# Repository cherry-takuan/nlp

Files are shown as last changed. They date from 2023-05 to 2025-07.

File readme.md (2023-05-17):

# NLP(NAND Logic Processor)
 現在開発中のNANDのみを用いたCPUのプロジェクトです．
現在以下のバリエーションが存在します  
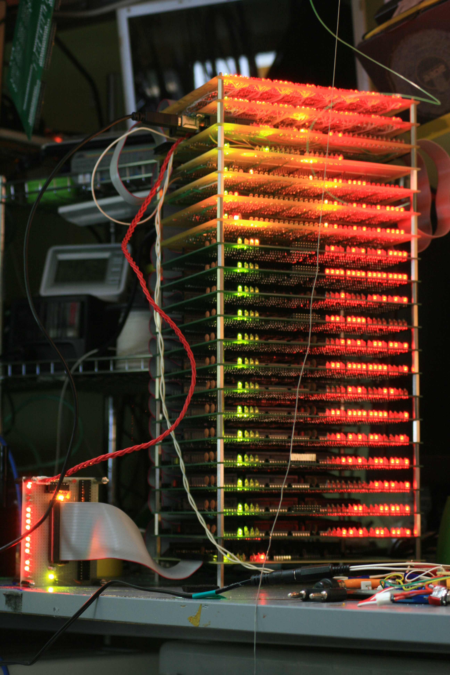
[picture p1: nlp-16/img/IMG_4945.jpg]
NLP-16

- NLP-16
- NLP-16A

 NLP-16は本プロジェクトの最初の成果物です．2019年(私が高校2年)の冬に設計を開始し，そこから３年ほどかけ製作しました．  
 [動作(Twitter)](https://twitter.com/cherry_takuan/status/1593374888496021505)  
単独での動作に成功しましたがいくつかの改善点が見つかったため，NLP-16によって得られた知見を基に改良版としてNLP-16Aを現在は開発中です．  
 また，NLP-16Aではキット化を目標に設計，製作しています．

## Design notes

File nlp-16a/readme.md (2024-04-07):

# NLP-16A
NLP-16の知見を基に現在製作しているNAND CPU．
スペックを維持したままキット化(あわよくば教育用に)を目標にしている．
## 歴
- 2023年始 次世代機(NLP-16A)の開発の検討
- 2023/03/11 NLP-16の開発を中止．NLP-16によって得られた知見を基に改良版の16Aの開発に移行．
- 2023/03/15 NLP-16A ALU開発開始
- 2023/05/15～ 基板到着．試作開始
- 2023/07/26～ ALU制御基板開発開始
- 2023/08/10～ デバッガ開発開始

## 現在の作業
- [ALUの製作](./Hardware/alu_c)→完了
- ALU制御(回路設計段階)→完了
- [デバッガの製作](./Hardware/debugger)→完了
- Y BUS制御→完了
- A BUS制御→完了
- Acc→完了
- Reg→完了

## 現時点で判明している不良個所
### ALU  
電源のターミナルブロックとICの干渉  
NLP-16と基板形状の不一致  
ALU制御基板-ALU基板間の制御ピンにおいて入力Bの符号ビットが設計から欠落  
デコード回路の軽微な修正
### 命令デコーダ
設計中
### レジスタ，データバス  
設計完了  
Y BUS内部処理モードにAccの追加
### I/O
設計完了  
特になし．

### デバッガ  
設計完了(USB-UART変換は未定)  

## 設計変更点  
- MEMのRegAddressを10から11に変更  
- RegAddress10をRegFに変更(これはまた変更の可能性があるが，変更の範囲は内部モードで使用しない用途に限る)  

## NLP-16との更新  
- PCB化  
- レジスタバスに用いた回路を変更．アクセスの最悪値を約1/3に高速化した  
- 1word命令の増強．演算系命令を中心にアキュムレータを積極的に使用する演算を行う．  
- 割り込み関連命令の増強．割り込み禁止/許可命令，ソフトウェア割り込みの実装を行った．

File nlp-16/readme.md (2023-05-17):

# NLP-16
NLP-16は2入力NANDのみで構成された16bitCPUです．  
NANDのみでありながらi8080のような多彩な命令を備えています．  
NLP-16  
## 歴
- 2019/11/19 プロジェクト開始
- 2020/06/13算術論理演算装置(ALU)の完成．PCによって制御を行いハードウェアのテストを行う
- 2022/03/21 レジスタおよびデータバス制御の完成．PCを用いてハードウェアの自動テストを行う
- 2022/03/30 プロセッサの各要素を外部のマイコンから制御し，目的の命令を実行できることを確認．また，テストの一環としてフィボナッチ数列を20項までを1セットとして1000セットの計算を実施，成功．
(以下は日にちを要確認，仮の日にち)
- 2022/09/02 命令デコーダを実装完了．
- 2022/09/03 ROM基板を製作．NLP-16のみで独立した動作に成功．
- 2022/09/04 MakerFaireTokyo2022にちぇりー技術として単独出展し，NLP-16を展示．不安定ながら好評いただいた．
- 2023/03/11 NLP-16の開発を中止．NLP-16によって得られた知見を基に改良版の16Aの開発に移行．

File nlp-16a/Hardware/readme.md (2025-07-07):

# ハードウェア
ハードウェアへのリンク。回路/基板データをクリックするとブラウザからアートワークや回路が閲覧できます。kicanvasすごい。ありがとう。

アーキテクチャ，命令セットは以下から。

[アーキテクチャ](https://github.com/cherry-takuan/nlp/tree/master/nlp-16a/architecture)
[命令セット](https://github.com/cherry-takuan/nlp/blob/master/nlp-16a/architecture/ISA.pdf)

## NLP-16A本体
***
### 演算装置
ALUはプロセッサ内での演算処理を行うユニットです。NLP-16Aでは8bit ALUを2ユニット使用し16bitの並列演算を行っています。

ALU制御回路回路はALUを操作するための制御信号生成し，また演算結果からフラグを生成する機能を持っています。
***
#### ALU本体
[alu_c](https://github.com/cherry-takuan/nlp/tree/master/nlp-16a/Hardware/alu_c)

[回路/基板データ](https://kicanvas.org/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)

最新バージョン : v1.2

#### ALU制御
[alu_ctrl](https://github.com/cherry-takuan/nlp/tree/master/nlp-16a/Hardware/alu_ctrl)

[回路/基板データ](https://kicanvas.org/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)

最新バージョン : v1.1
***
### レジスタファイル
レジスタファイルとは，プロセッサ内で一時的に記憶するレジスタと呼ばれる回路を複数集積したものです。NLP-16Aでは16bitのデータを記憶可能なレジスタを16本持っています。

汎用レジスタは5本で，残りのレジスタは何らかの役割を持ち，単純な記憶以外の動作も行うことがあります。

***
### レジスタ
[Reg](https://github.com/cherry-takuan/nlp/tree/master/nlp-16a/Hardware/Reg)

[回路/基板データ](https://kicanvas.org/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)

最新バージョン : v1.1

#### アキュムレータ
[Accumulztor](https://github.com/cherry-takuan/nlp/tree/master/nlp-16a/Hardware/Accumulator)

[回路/基板データ](https://kicanvas.org/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)

最新バージョン : v1.1

#### ALU入力バス(A BUS)制御
[A_BUS_Ctrl](https://github.com/cherry-takuan/nlp/tree/master/nlp-16a/Hardware/A_BUS_Ctrl)

[回路/基板データ](https://kicanvas.org/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)

最新バージョン : v1.1

#### ALU出力バス(Y BUS)制御
[Y_BUS_Ctrl](https://github.com/cherry-takuan/nlp/tree/master/nlp-16a/Hardware/Y_BUS_Ctrl)

[回路/基板データ](https://kicanvas.org/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)

最新バージョン : v1.2
***
### 入出力
NLP-16Aは16 bit x 64 kwordの1つの入出力ポートを持っています。
内部的にはレジスタの一つとしてアクセス可能な構造になっています。

主記憶及び外部デバイスとの接続に使用されます。
***
#### 外部バス制御
[Bus_terminator](https://github.com/cherry-takuan/nlp/tree/master/nlp-16a/Hardware/BUS_terminator)

[回路/基板データ](https://kicanvas.org/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)

最新バージョン : v1.1

***
### 制御装置
制御装置では，上記のユニットを入力された命令に従って制御を行います。

***

#### 命令デコーダ
[Instruction_decoder](https://github.com/cherry-takuan/nlp/tree/master/nlp-16a/Hardware/Instruction_decoder)

[回路/基板データ](https://kicanvas.org/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)

最新バージョン : v1.1

#### ステート保持レジスタ
[State_hold](https://github.com/cherry-takuan/nlp/tree/master/nlp-16a/Hardware/State_hold)

[回路/基板データ](https://kicanvas.org/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)

最新バージョン : v1.0

#### 命令デコーダ グルーロジック
[ID_interface](https://github.com/cherry-takuan/nlp/tree/master/nlp-16a/Hardware/ID_interface)

[回路/基板データ](https://kicanvas.org/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)

最新バージョン : v1.1

***

## 周辺機器

***

### NLP-16A専用デバッガ
基板の自動テストやRAMへのIPLデータ書き込み等で使用。

[debug](https://github.com/cherry-takuan/nlp/tree/master/nlp-16a/Hardware/debug)

[回路/基板データ](https://kicanvas.org/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)

最新バージョン : v1.1

### マザーボード
プロセッサに周辺機器を接続するためのボード。マザーと言いつつ本体よりかなり小さい。

[IO_board](https://github.com/cherry-takuan/nlp/tree/master/nlp-16a/Hardware/IO_board)

[回路/基板データ](https://kicanvas.org/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)

最新バージョン : v1.1

### RAMボード(デバッガ接続版)
主記憶装置。デバッガから内容を書き換えることが可能で，IPL等の導入に使用できる。

[RAM_board](https://github.com/cherry-takuan/nlp/tree/master/nlp-16a/Hardware/RAM_board)

[回路/基板データ](https://kicanvas.org/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)

最新バージョン : v1.1

### 通信ボード
RS-232Cを介して様々なデバイスと通信可能。PC，サーマルプリンタ，MSMPインターフェイス等と接続した実績がある。

[RS_232C_board](https://github.com/cherry-takuan/nlp/tree/master/nlp-16a/Hardware/RS_232C_board)

[回路/基板データ](https://kicanvas.org/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)

最新バージョン : v1.2

### ビデオボード

キャラクタジェネレータ付きの640x480画素のVGA映像出力ボード。
VRAM領域にテキストデータを書き込むと対応した画面位置に文字を表示する機能を持つ。

なお以下のリポジトリは画面に表示こそ可能だが，ハードウェアに一部不具合があるバージョン。今後修正を反映予定(正常に動作するボードは完成済みで反映待ち)

[VGAボード](https://github.com/cherry-takuan/NLP_VGA)

[回路/基板データ](https://kicanvas.org/?github=https%3A%2F%2Fgithub.com%2Fcherry-takuan%2FNLP_VGA)

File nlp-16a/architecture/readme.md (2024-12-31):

# NLP-16Aアーキテクチャ

NLP-16Aはストアドプログラム方式の16bit CPUです。
i8085の命令セットを参考に，16bitへの拡張やアドレッシングモードの拡充等を行っています。  

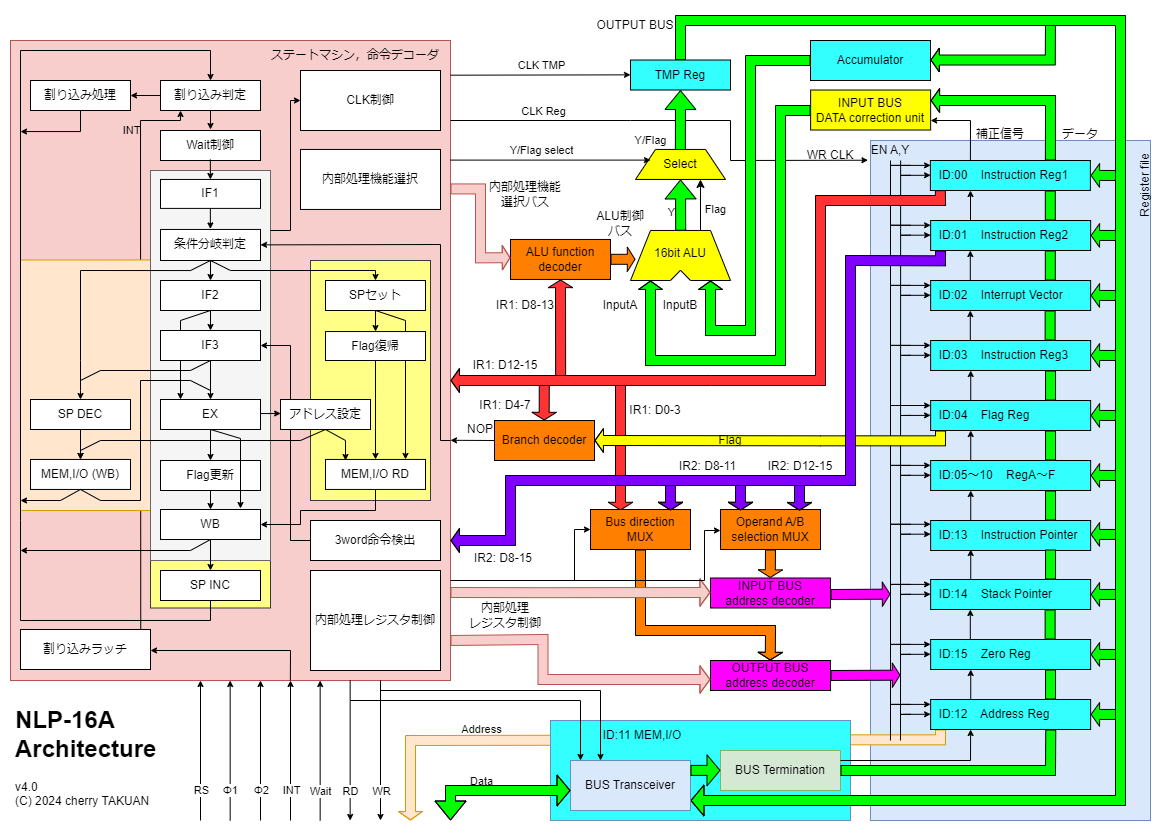
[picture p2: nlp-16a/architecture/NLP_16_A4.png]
Architecture アーキテクチャ


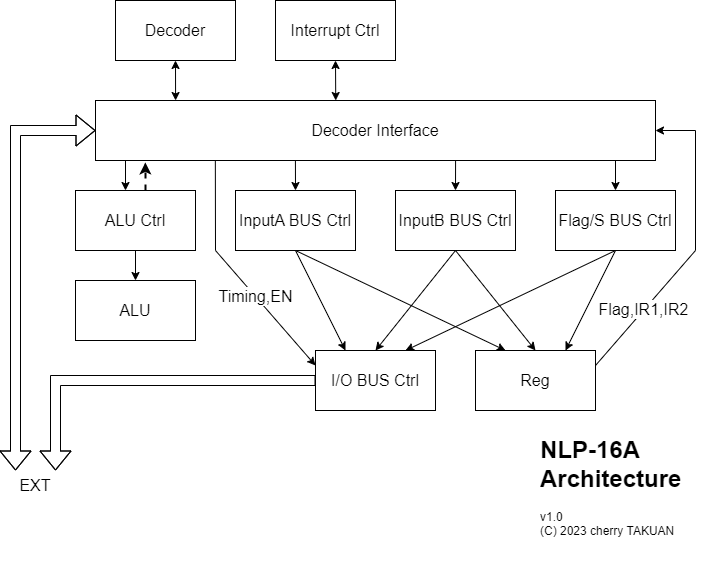
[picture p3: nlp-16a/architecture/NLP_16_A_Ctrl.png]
Control 制御関連の接続


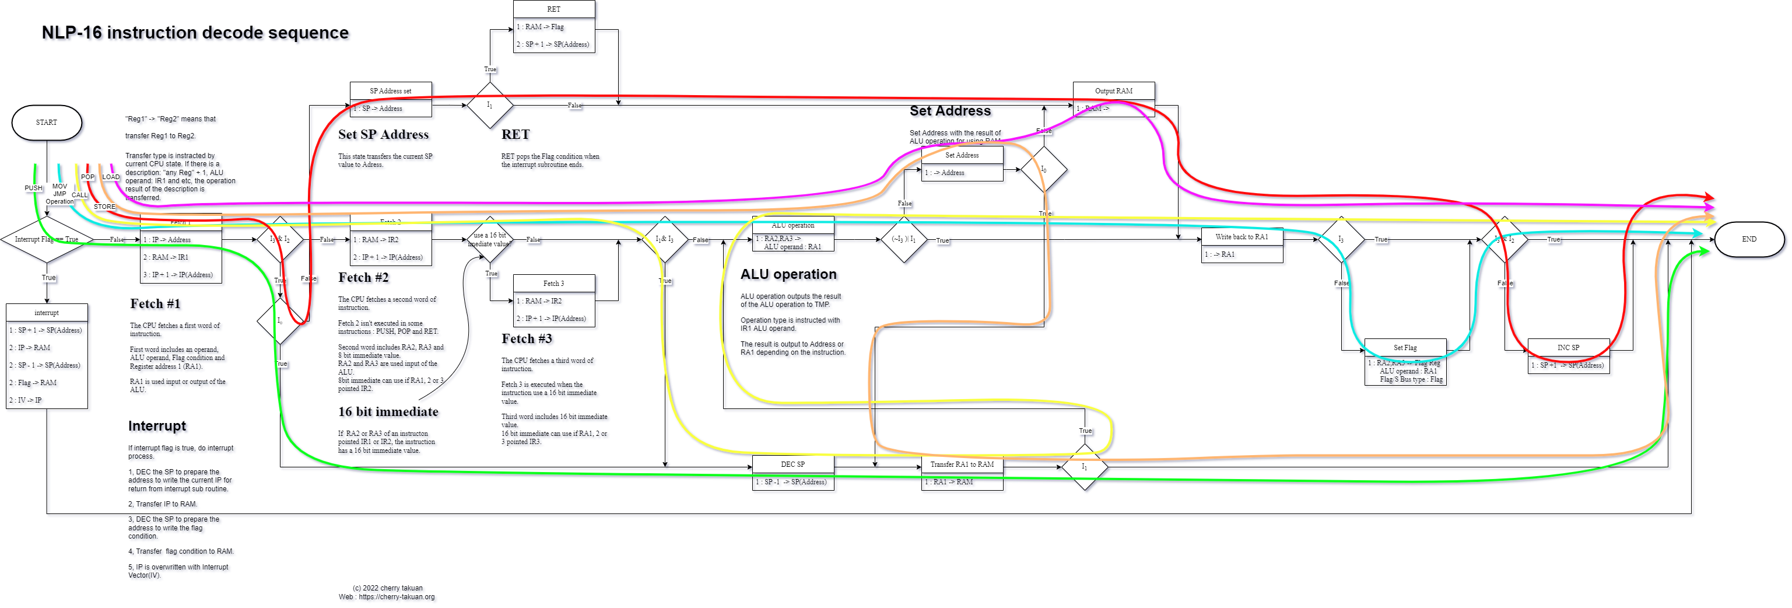
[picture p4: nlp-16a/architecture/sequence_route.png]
sequence 命令実行シーケンス


## ISA

[ISA.pdf](https://github.com/cherry-takuan/nlp/blob/master/nlp-16a/architecture/ISA.pdf)

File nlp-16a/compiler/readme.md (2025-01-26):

# NLP-16Aコンパイラ nlpcc  

開発中のNLP-16A向けのコンパイラです．最初はcherry c compilerの略でCCCにしようと思いましたがなんかアレなのでnlp c compilerからnlpccとしました．

機械語はコンパイル結果をnlpasmフォルダ内にあるアセンブラを通して生成します．

このコンパイラは主に以下のプロジェクトを参考にして作っています．  

- [低レイヤを知りたい人のためのCコンパイラ作成入門](https://www.sigbus.info/compilerbook)
- [comproc](https://github.com/uchan-nos/comproc/tree/main)

`make test`を実行するとエミュレータを通してテストが実行され，テスト結果が[report.txt](report.txt)に出力されます。

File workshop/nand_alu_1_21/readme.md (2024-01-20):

# NANDだけでALUを作るワークショップ資料

NANDだけでALUを作るワークショップ資料で使用する予定の資料を公開します．

なお，GitHub上のPDFビューアではリンクがクリックできないようなので資料中のリンクを掲載しておきます．

 [1ページ目 https://cherry-takuan.org](https://cherry-takuan.org)  

 [3ページ目 https://scrapbox.io/uchan/ComProc_CPU_Board%E7%B5%84%E3%81%BF%E7%AB%8B%E3%81%A6%E3%81%AE%E6%89%8B%E5%BC%95%E3%81%8D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](https://scrapbox.io/uchan/ComProc_CPU_Board%E7%B5%84%E3%81%BF%E7%AB%8B%E3%81%A6%E3%81%AE%E6%89%8B%E5%BC%95%E3%81%8D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)  
 
 [6ページ目 https://github.com/cherry-takuan/nlp/blob/master/nlp-16a/Hardware/alu_c/%E5%9B%9E%E8%B7%AF%E3%83%97%E3%83%AC%E3%83%93%E3%83%A5%E3%83%BC.pdf](https://github.com/cherry-takuan/nlp/blob/master/nlp-16a/Hardware/alu_c/%E5%9B%9E%E8%B7%AF%E3%83%97%E3%83%AC%E3%83%93%E3%83%A5%E3%83%BC.pdf)

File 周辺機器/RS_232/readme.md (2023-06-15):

# 通信モジュール  
RS-232Cを用いた通信モジュールの回路図を公開します．なお，レベル変換の回路は入っていないのでMAX232などを用いて適切に接続してください(ロジックレベルのUARTでは必要ありません)  
また詳細な解説については[ここ]()を参照してください．

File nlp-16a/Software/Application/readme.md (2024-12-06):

# アプリケーション例
NLP-16で実際に動作したアプリケーション例です．
このディレクトリにあるnlpasm.pyや[NLP-16Aオンラインアセンブラ](https://cherry-takuan.org/nlpasm/)からアセンブル可能。

- mikubug.asm  
モニタプログラムです．MIKBUGをパクってミクバグにしました．意味はない．  
以下のプログラムはこのモニタプログラムから呼び出して実行する．
  
- life_game.asm
知人の [きっちーさん](https://twitter.com/rikeden_net)が書いてくださったライフゲームのプログラムの修正版．  
なぜ修正版かと言うと，NLP-16には公式アセンブラが2種類あり，後発のアセンブラであるちぇりー製アセンブラで動くようにしたかったからという...なお，ちぇりー製アセンブラは記法が悪い意味でめちゃくちゃで癖が強い．  
0x9000-900Fの間を盤面の記憶に使用する(つまりその間に干渉する位置にはプログラムを配置できない)

- RPN.asm
逆ポーランド記法の計算機．多分動く

- gochiusa.asm
CPU本体から放射されるノイズを使用した演奏プログラム。実行すると付近においてあるラジオからごちうさOPが鳴るはず。(1.4MHz前後で使用し，ラジオのチューニングもその付近)

- pi.asm
円周率を150桁計算できる。3MHzで10分ほどかかる。がたろう氏のプログラムを移植した。  
参考:[自作TTLコンピュータで円周率を計算する](http://diode.matrix.jp/SOFT/R8/PAI_1.htm) がたろう  
0x9000-9200の間を数値保持に使用
- MSMP.asm
自作CPUを語る会の有志で策定，実装を行った通信プロトコル。  
[自作CPU向けメッセージングプロトコル](https://scrapbox.io/uchan/%E8%87%AA%E4%BD%9CCPU%E5%90%91%E3%81%91%E3%83%A1%E3%83%83%E3%82%BB%E3%83%BC%E3%82%B8%E3%83%B3%E3%82%B0%E3%83%97%E3%83%AD%E3%83%88%E3%82%B3%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)  
2024年冬に行った自作CPUを語る会で実機実験を行った。  
[自作 CPU 同士で通信してみた](https://uchan.net/ublog.cgi/communicating-between-toy-cpus) uchan  
本アプリケーションはMSMPで通信するだけでなく，逆ポーランド記法の計算式メッセージを受信すると，その計算結果を返信するAPIを含む。

## アプリケーションのロードと実行方法

### プログラムのロード
mikubug起動後，Lコマンドを使用。mikubugは標準のコントロールソフト(Software/debugger/test/main.py)から起動した後，自動的に立ち上がりプロンプト*が表示される。Lを入力後開始アドレスを入力する。開始アドレスはmikubug本体の領域，mikubugが使用する予約領域，プログラムが使用する領域を避ける必要がある。  
- mikubug 0x0000 - 0x0400
- mikugug予約領域 0x8000 - 0x8100

は指定不可。(MEM領域破壊が起きる)

だいたいいつも0x8100から0x8500あたりを指定している。

ok.が表示されたのちプログラム受信待ちになるため，アセンブラが出力したファイルを送信する。  
送信が完了するとok.が表示されてモニタに戻る。

### プログラムの起動
Gコマンドを使用。Gを入力後，開始アドレスを入力する。アドレスはロード時に使用したアドレスを指定する。

## 付属資料:MIKUBUG使用方法

Mikubugは6800用のモニタプログラム「MIKBUG」を参考に開発した，NLP-16A向けのプログラムのデバッグ，評価を簡単に行うためのソフトウェアです。

コマンド
- Dコマンド ： DUMPコマンド
指定した領域のメモリダンプを行います。バグを放置しているため，先頭アドレスから７FFF以内の領域を超えて指定すると即リターンされます。
- Mコマンド ： MODIFYコマンド
指定したアドレスの内容を操作できます。内容を入力後エンターで内容を操作，スペースで無変更，ESCで終了ができます。これを使用して機械語プログラミングも可能です。
- Lコマンド ： LOADコマンド
指定したアドレスにRS-232C経由でバイナリを転送することができます。ファイルは16進文字列をASCIIで転送し，スラッシュが来ると転送を終了します。自作UARTボードの性能をフルで使用するために色々やってます。
- Rコマンド ： Regコマンド？
レジスタの値を出力するコマンドです。一番デバッグに使用しそうなコマンドですが，全然使わなかったのでv2.0では消去されています。このコマンドが無いせいで実質デバッグ，評価を行うソフトウェアではなくなっている気がします。
- Gコマンド ： GOコマンド
指定したアドレスから始まるユーザープログラムを呼び出すコマンドです。

また，ユーティリティとして，RS-232C入出力ルーチン，PRINTルーチン，数値表示ルーチン，16進数値入力ルーチン，VGA(画面制御)ドライバ等が提供されています。

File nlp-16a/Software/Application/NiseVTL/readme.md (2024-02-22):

# 偽VTL
VTLっぽい奴＋テキストエディタをNLP-16，16Aに実装したい．
試しにCで書いてみた．

## エディタ
edっぽい操作．数値を入れるとその行にカーソルが飛んでaでその位置に挿入，cでその行を上書き，dで削除．

pで全ソース表示．

数値以外にも.で現在のカーソル位置，\$で最終行が指定できる．
例えば`1,4`で1-4行目を表示，`4,$`で4行目から最終行まで表示，`.,3`で先頭から3行目まで表示となる．

rで先頭からプログラムが走る．
おまけでDでギャップバッファのデバッグ表示．

## 偽VTL

だいたいVTL．
変数はA-Zと配列1つのみ．  
\#に数値を代入で指定行(先頭の行番号)に飛ぶ．?は数値の入出力で$が文字の入出力．  
式の評価はちょっと変で左辺をRPNで評価し，右辺に代入．
配列の使い方
```
10 20,2*1=:
20 1:=?
```
実行すると40が返ってくる．
```
10| array[1] = 20*2
20| print(array[1])
```
みたいな感じ．
最上位のスタックを配列のアドレスになり(ここでは1):で配列が使用される位置．

適当に使って試してみて欲しい．

実行できるサンプルプログラム(フィボナッチ数列)
```
10 0=A,1=B
20 AB+=C,B=A,C=B,C=?,',',100,C>20*=#
30 'END\n'
```

マンデルブロ集合の奴
```
10 50=F
20 0,12-=Y
30 0,39-=X
40 X229*100/=C
50 Y416*100/=D
60 C=A
70 D=B
80 0=I
90 BF/=Q,BQF*-=S
100 AA*BB*-F/C+=T
110 AQ*AS*F/+2*D+=B
120 T=A
130 AF/=P,BF/=Q
140 PP*QQ*+5>180*=#
150 I1+=I,I16<90*=#
160 ' '
170 200=#
180 I7I10>*+=I
190 I48+=$
200 X1+=X,X40<40*=#
210 '\n'
220 Y1+=Y,Y12<30*=#
```

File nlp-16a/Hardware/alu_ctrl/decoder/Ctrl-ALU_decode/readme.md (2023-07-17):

# ALU制御回路シミュレーション  
ALU制御回路の一部の機能を検証しました．  
具体的には  
ID -(6bit 制御バス)→ ALU制御回路 -(8bit制御バス + carry)→ ALU  
となっている部分のALU制御回路の部分にあるデコーダ回路を検証しています．  
  
実現したい真理値表はALU_Ctrl.jpgにあるもので，ALU制御回路からALUまでは負論理である．  

シミュレーション結果は以下のようになった．  

VCD info: dumpfile test.vcd opened for output.  
                   0: |0, 1, 1, 1, 1 | 0, 0, 0 |     C0 = 0, C1 = 1, C2 = 0, C3 = 0, C4 = 1, C5 = 0, c_flag = x  
                  10: |0, 1, 1, 1, 1 | 0, 0, 1 |     C0 = 0, C1 = 1, C2 = 0, C3 = 0, C4 = 0, C5 = 1, c_flag = x  
                  20: |1, 0, 1, 1, 1 | 1, 0, 0 |     C0 = 0, C1 = 0, C2 = 1, C3 = 0, C4 = 1, C5 = 0, c_flag = x  
                  30: |1, 0, 1, 1, 1 | 0, 1, 1 |     C0 = 0, C1 = 0, C2 = 1, C3 = 1, C4 = 0, C5 = 0, c_flag = x  
                  40: |1, 0, 1, 1, 1 | 0, 0, 0 |     C0 = 0, C1 = 0, C2 = 1, C3 = 1, C4 = 1, C5 = 0, c_flag = x  
                  50: |1, 1, 0, 1, 1 | 0, 0, 0 |     C0 = 0, C1 = 0, C2 = 0, C3 = 1, C4 = 1, C5 = 0, c_flag = x  
                  60: |1, 1, 0, 1, 1 | 1, 1, 1 |     C0 = 0, C1 = 0, C2 = 0, C3 = 0, C4 = 0, C5 = 0, c_flag = x  
                  70: |0, 1, 1, 1, 1 | 0, 1, 0 |     C0 = 0, C1 = 1, C2 = 1, C3 = 0, C4 = 1, C5 = 1, c_flag = x  
                  80: |0, 1, 1, 1, 1 | 0, 1, 1 |     C0 = 0, C1 = 1, C2 = 1, C3 = 0, C4 = 0, C5 = 0, c_flag = x  
                  90: |1, 1, 1, 0, 1 | 0, 1, 1 |     C0 = 1, C1 = 0, C2 = 0, C3 = 1, C4 = 0, C5 = 0, c_flag = x  
                 100: |1, 1, 1, 0, 1 | 1, 1, 1 |     C0 = 1, C1 = 0, C2 = 0, C3 = 0, C4 = 0, C5 = 0, c_flag = x  
                 110: |1, 1, 1, 0, 1 | 1, 0, 1 |     C0 = 1, C1 = 0, C2 = 0, C3 = 0, C4 = 1, C5 = 0, c_flag = x  
                 120: |1, 1, 1, 1, 0 | 0, 1, 1 |     C0 = 1, C1 = 0, C2 = 1, C3 = 1, C4 = 0, C5 = 0, c_flag = x  
                 130: |1, 1, 1, 1, 0 | 1, 1, 1 |     C0 = 1, C1 = 0, C2 = 1, C3 = 0, C4 = 0, C5 = 0, c_flag = x  
                 140: |1, 1, 1, 1, 0 | 1, 0, 1 |     C0 = 1, C1 = 0, C2 = 1, C3 = 0, C4 = 1, C5 = 0, c_flag = x  

(carryは行っていない)  
あってるのでおｋ．以上．

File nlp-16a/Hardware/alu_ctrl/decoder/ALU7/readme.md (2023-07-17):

# 入力  
Ctrl0  
介入モード(~ALU_G)  
    デフォルト動作はMOV

非演算モード(IR16)
    デフォルト動作はスルー

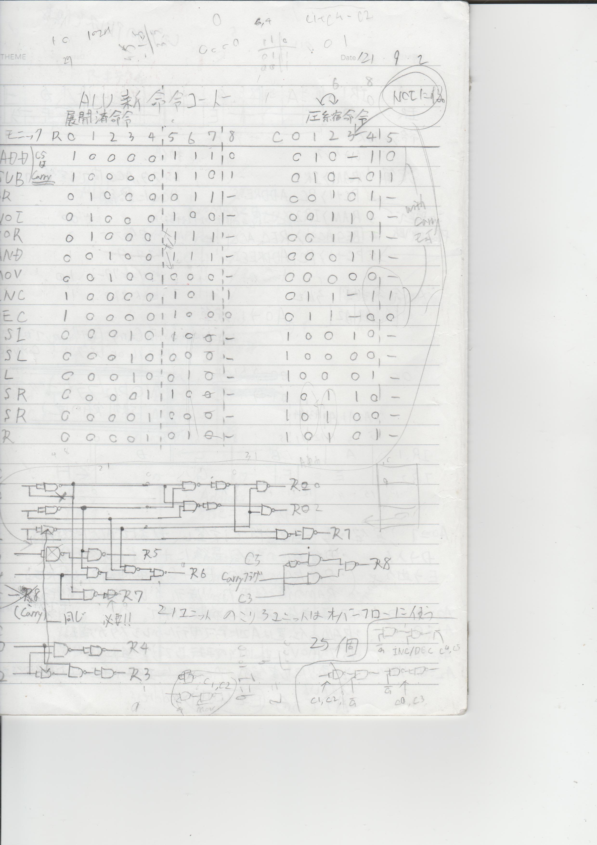
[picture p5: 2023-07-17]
nlp-16a/Hardware/alu_ctrl/decoder/Ctrl-ALU_decode/ALU_Ctrl.jpg

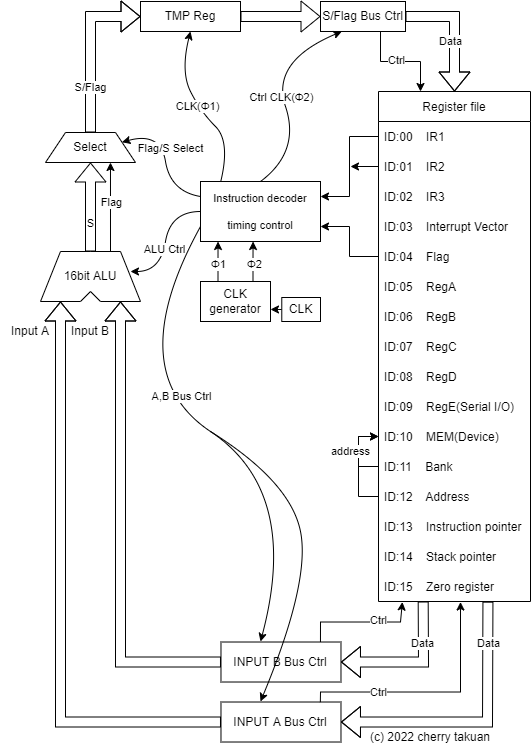
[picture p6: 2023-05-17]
nlp-16/architecture/architecture.png

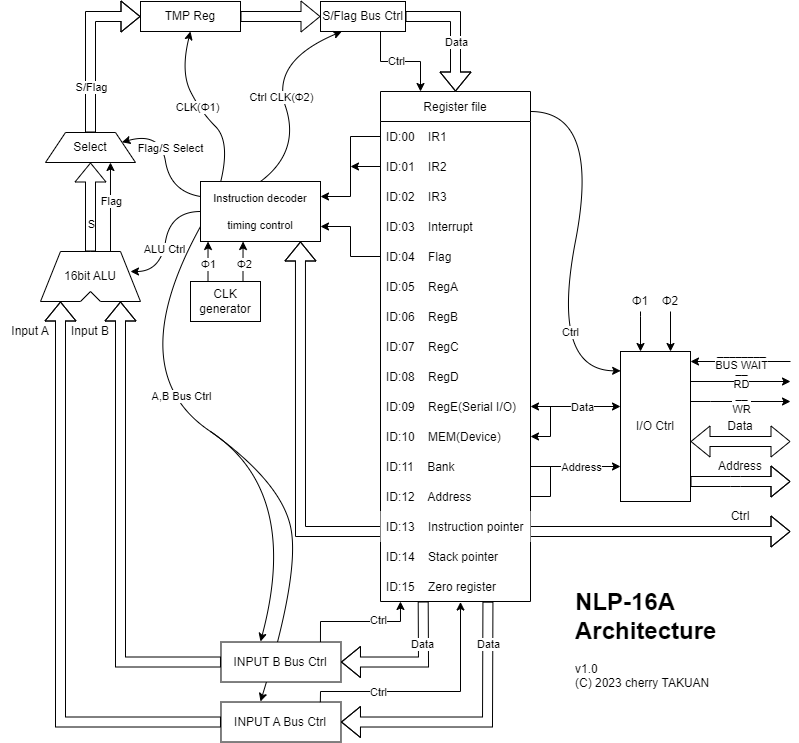
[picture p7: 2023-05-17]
nlp-16a/architecture/NLP_16_A.png

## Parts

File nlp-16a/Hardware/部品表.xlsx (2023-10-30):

 | 調達先はすべて株式会社秋月電子通商
 | 品名 | 型番 | 通販コード | 単価 | 個数 | 小計
ALU制御 | NAND | U74HC00 | I-14052 | ¥20 | 28 | ¥560
 | ネットワーク抵抗4.7k ohm | RKC8BD472J | R-13724 | ¥25 | 3 | ¥75
 | チップ抵抗 470R | RC0603J470R | R-06471 | ¥500 | 1 | ¥500
 | チップ抵抗 10R | RC0603J10R | R-13832 | ¥850 | 1 | ¥850
 | セラミックコンデンサ 0.1μF 200個入り | DSXC75TJYF104Z | P-07935 | ¥200 | 1 | ¥200
 | 黄色LED 10個入り | OSY6PA3E34B | I-12692 | ¥110 | 1 | ¥110
 | 赤色LED 10個入り | OSR5JA3E34B | I-16588 | ¥80 | 1 | ¥80
 | ターミナルブロック2P | WJ300-5.0-02P-140-00A | P-15877 | ¥20 | 1 | ¥20
 | ピンヘッダL型2x40 | PH-2x40RG | C-00148 | ¥100 | 1 | ¥100
 | ピンヘッダ2x40 | PH-2x40SG | C-00082 | ¥50 | 2 | ¥100
 | 調達先はすべて株式会社秋月電子通商
 |  |  |  |  | 合計 | ¥2595
デバッガ1セット | CH32V003F4P6 | CH32V003F4P6 | I-18061 | ¥50 | 1 | ¥50 | 個数4→1に
 | ピンヘッダ1x6L | PH-1X6RG(2) | C-05336 | ¥10 | 1 | ¥10
 | ピンソケット1x6L | 2212R-06G-85 | C-03795 | ¥20 | 2 | ¥40
 | ピンヘッダ2x10 | PH-2x10SG | C-00078 | ¥50 | 4 | ¥200
 | ピンヘッダ2x20 | PH-2x20SG/RH | C-00080 | ¥50 | 1 | ¥50
 | チップ抵抗470 | ALU制御の余りを使用 |  |  |  | ¥0
 | チップ抵抗4.7k | ALU制御の余りを使用 |  |  |  | ¥0
 | ネットワーク抵抗4.7k ohm | RKC8BD472J | R-13724 | ¥25 | 2 | ¥50 | 個数0→2に
 | LED |  |  |  |  | ¥0
 |  |  |  |  | 合計 | ¥400
 | チップセラミックコンデンサ0.1μF | GRM188R11E104KA01D | P-14557 | ¥100 | 1 | ¥100
 |  |  |  |  | 4セット | ¥1700
ALU手動テストボード | USB Type-Cコネクタ 電源供給用 | A295-CTRPB-1 | C-16895 | ¥40 | 1 | ¥40
 | DIPスイッチ 8P | EDS108SZ | P-00587 | ¥70 | 1 | ¥70
 | DIPスイッチ 4P | EDS104SZ | P-00586 | ¥60 | 1 | ¥60
 | ピンヘッダ 2×10 (20P) | PH-2x10SG | C-00078 | ¥50 | 2 | ¥100
 | ターミナルブロック 2P 緑 縦 小 | TB111-2-2-E-1-1 | P-02333 | ¥35 | 2 | ¥70 | 20円のものははまらない時があるので35円のものに変更
 | 集合抵抗 8素子 10kΩ | RKC8BD103J | R-11910 | ¥30 | 1 | ¥30 | 4.7kは4素子が無かったため，10kに変更
 | 集合抵抗 4素子 10kΩ | RKC4BD103 | R-11909 | ¥20 | 1 | ¥20
 | ２×１０（２０Ｐ）リボンケーブル | DG01032-0041-01-180mm | C-13378 | ¥200 | 1 | ¥200
 |  |  |  |  | 合計 | ¥590
 |  |  |  |  | 1人で | ¥1770
 |  |  |  |  | 2人で | ¥3540
ALU | NAND | U74HC00 | I-14052 | ¥20 | 60 | ¥1200
 | ネットワーク抵抗4.7k ohm | RKC8BD472J | R-13724 | ¥25 | 8 | ¥200
 | 3mm赤色LED 625nm OSR5JA3E34B (10個入) | OSR5JA3E34B | I-16588 | ¥80 | 6 | ¥480
 | ピンヘッダ (オスL型) 2×10 (20P) | PH-2x10RG | C-10903 | ¥60 | 4 | ¥240
 | 電源用電解コンデンサー100μF35V105℃ ルビコンZLH | 35ZLH100MEFC6.3X11 | P-02724 | ¥15 | 1 | ¥15
 | ターミナルブロック 2P 緑 縦 小 | TB111-2-2-E-1-1 | P-02333 | ¥35 | 1 | ¥35
 |  |  |  |  | 合計 | ¥2170
 |  |  |  |  | ふたりで | ¥4340
 | セラミックコンデンサ 0.1μF 200個入り | DSXC75TJYF104Z | P-07935 | ¥200 | 0 | ¥0
 | チップ抵抗 10R | RC0603J10R | R-13832 |  | 0 | ¥0 | 前回までに発注した余りのパーツを使用
 | チップ抵抗 470R | RC0603J10R | R-13832 |  | 0 | ¥0
 |  |  |  |  | 合計 | ¥0
その他 | 耐熱電子ワイヤー 1m×10色 導体外径0.54mm(AWG24相当) | 0.2sq (7/0.18) AWG24x10 | P-10672 | ¥300 | 1 | ¥300
 | USB Type-A Type-C変換ケーブル | 100円ショップで調達 |  | ¥110 | 2 | ¥220
 |  |  |  |  | 総計 | ¥7880
 |  |  |  |  | 送料込み | ¥8380

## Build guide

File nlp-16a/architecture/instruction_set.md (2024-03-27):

# NLP-16A 命令セット

2024-03-09 改定

NLP-16Aの命令セット，2024/02/26時点での暫定．
本当はNLP-16にバイナリレベルでの後方互換を保ちたかったのですが，デコードの関係上ちょっとやめました．

## 命令bit構成
NLP-16A 命令セットでは1～3ワードの可変長命令を採用している．
各ワードの構成は以下の通り．

| 1word |  |  |
|:-:|:-:|:-:|
| opcode (8 bit) | Flag (4 bit) | operand A (4 bit)|

| 2word |  |  |
|:-:|:-:|:-:|
| operand B (4 bit)| operand C (4 bit)| 8 bit Imm (8 bit)|

| 3word |
|:-:|
| 16 bit Imm (16 bit)|

### Flagフィールド
NLP-16A命令セットではすべての命令において条件実行ができる．条件は1ワード目のFlagフィールドで設定し，条件に合致した場合は実行され，合致しない場合には命令は無視され，次の命令を実行する．

なお，必要クロック数は実行，非実行に依らない．

サフィックスはアセンブリでは以下のような表現になる．
`MOV.s B,A`(直前の演算結果が負の場合，RegAの値をRegBに転送する．)
| 条件 |サフィックス| 値 |
|:-:|:-:|:-:|
|NOP|.nop|0x0|
|Cが立っている時に実行|.c|0x8|
|前回の演算結果がオーバーフローしたときに実行|.v|0xA|
|0の時に実行|.z|0xC|
|負の時に実行|.s|0xE|
|常に実行|無|0x1|
|Cが立っていない時に実行|.nc|0x9|
|オーバーフローしなかったときに実行|.nv|0xB|
|非ゼロで実行|.nz|0xD|
|正，もしくは0の時に実行|.ns|0xF|

### 汎用レジスタID
operand AからCで指定するレジスタのID．アキュムレータAccは指定することはできない．
| 汎用レジスタ | 値 |
|:-:|:-:|
| Reg A | 0x5 |
| Reg B | 0x6 |
| Reg C | 0x7 |
| Reg D | 0x8 |
| Reg E | 0x9 |
| Reg F | 0xA |

## 演算系命令

`x`はDon't care，`-`は存在しない(例えば2ワード命令では3ワード目を使用しない等)フィールド．

### 算術演算

#### ADD
|ニモニック (効果)| 命令ワード数 | opcode | operand A | operand B | operand C| 8 bit Imm| 16 bit Imm|備考|
|:-:|:-:|:-:|:-:|:-:|:-:|:-:|:-:|:-:|
|ADD c, a,  b<br>(c = a+b)|2| 0x0A | c | a | b | x | - ||
|ADD c, a,  Imm8<br>(c = a+Imm8)|2| 0x0A | c | a | 0x1 | Imm8 | - ||
|ADD c, a,  Imm16<br>(c = a+Imm16)|3| 0x0A | c | a | 0x2 | x | Imm16 ||
|ADD a<br>(a = a + Acc)|1| 0x4A | a | - | - | - | - ||
|ADC c, a,  b<br>(c = a+b+carry)|2| 0x0E | c | a | b | x | - ||
|ADC c, a,  Imm8<br>(c = a+Imm8+carry)|2| 0x0E | c | a | 0x1 | Imm8 | - ||
|ADC c, a,  Imm16<br>(c = a+Imm16+carry)|3| 0x0E | c | a | 0x2 | x | Imm16 ||
|ADC a<br>(a = a + Acc+carry)|1| 0x4E | a | - | - | - | - ||

#### SUB
|ニモニック (効果)| 命令ワード数 | opcode | operand A | operand B | operand C| 8 bit Imm| 16 bit Imm|備考|
|:-:|:-:|:-:|:-:|:-:|:-:|:-:|:-:|:-:|
|SUB c, a,  b<br>(c = a-b)|2| 0x09 | c | a | b | x | - ||
|SUB c, a,  Imm8<br>(c = a-Imm8)|2| 0x09 | c | a | 0x1 | Imm8 | - |operand BとCは入れ替え(計算順序の入れ替え)可能(次行)|
|SUB c, Imm8, a<br>(c = Imm8 - a)|2| 0x09 | c | 0x01 | a | Imm8 | - |入れ替え後|
|SUB c, a,  Imm16<br>(c = a-Imm16)|3| 0x09 | c | a | 0x2 | x | Imm16 |計算順序の入れ替え可能 SUB c,a,Imm8参照|
|SUB a<br>(a = a - Acc)|1| 0x49 | a | - | - | - | - ||
|SBB c, a,  b<br>(c = a-b-borrow)|2| 0x0D | c | a | b | x | - ||
|SBB c, a,  Imm8<br>(c = a-Imm8-borrow)|2| 0x0D | c | a | 0x1 | Imm8 | - |計算順序の入れ替え可能 SUB c,a,Imm8参照|
|SBB c, a,  Imm16<br>(c = a-Imm16-borrow)|3| 0x0D | c | a | 0x2 | x | Imm16 |計算順序の入れ替え可能 SUB c,a,Imm8参照|
|SBB a<br>(a = a - Acc-borrow)|1| 0x4D | a | - | - | - | - ||

#### INC
|ニモニック (効果)| 命令ワード数 | opcode | operand A | operand B | operand C| 8 bit Imm| 16 bit Imm|備考|
|:-:|:-:|:-:|:-:|:-:|:-:|:-:|:-:|:-:|
|INC b, a<br>(b = a+1)|2| 0x1B | b | a | x | x | - ||
|INC a, Imm8<br>(a = Imm8+1)|2| 0x1B | a | 0x1 | x | Imm8 | - ||
|INC a, Imm16<br>(a = Imm16+1)|3| 0x1B | a | 0x2 | x | x | Imm16 ||
|INC a<br>(a = a+1)|1| 0x5B | a | - | - | - | - ||
|INCC b, a<br>(b = a+1+carry)|2| 0x1F | b | a | x | x | - ||
|INCC a, Imm8<br>(a = Imm8+1+carry)|2| 0x1F | a | 0x1 | x | Imm8 | - ||
|INCC a, Imm16<br>(a = Imm16+1+carry)|3| 0x1F | a | 0x2 | x | x | Imm16 ||
|INCC a<br>(a = a+1+carry)|1| 0x5F | a | - | - | - | - ||

#### DEC
|ニモニック (効果)| 命令ワード数 | opcode | operand A | operand B | operand C| 8 bit Imm| 16 bit Imm|備考|
|:-:|:-:|:-:|:-:|:-:|:-:|:-:|:-:|:-:|
|DEC b, a<br>(b = a-1)|2| 0x18 | b | a | x | x | - ||
|DEC a, Imm8<br>(a = Imm8-1)|2| 0x18 | a | 0x1 | x | Imm8 | - ||
|DEC a, Imm16<br>(a = Imm16-1)|3| 0x18 | a | 0x2 | x | x | Imm16 ||
|DEC a<br>(a = a-1)|1| 0x58 | a | - | - | - | - ||
|DECB b, a<br>(b = a-1-borrow)|2| 0x1C | b | a | x | x | - ||
|DECB a, Imm8<br>(a = Imm8-1-borrow)|2| 0x1C | a | 0x1 | x | Imm8 | - ||
|DECB a, Imm16<br>(a = Imm16-1-borrow)|3| 0x1C | a | 0x2 | x | x | Imm16 ||
|DECB a<br>(a = a-1-borrow)|1| 0x5C | a | - | - | - | - ||

### 論理演算
|ニモニック (効果)| 命令ワード数 | opcode | operand A | operand B | operand C| 8 bit Imm| 16 bit Imm|備考|
|:-:|:-:|:-:|:-:|:-:|:-:|:-:|:-:|:-:|
|AND c, a,b<br>(c = a & b)|2| 0x06 | c | a | b | x | - ||
|AND a<br>(a = a & Acc)|1| 0x46 | a | - | - | - | - ||
|OR c, a,b<br>(c = a \| b)|2| 0x12 | c | a | b | x | - ||
|OR a<br>(a = a \| Acc)|1| 0x52 | a | - | - | - | - ||
|NOT b, a<br>(b = ~a)|2| 0x14 | b | a | x | x | - ||
|NOT a<br>(a = ~a)|1| 0x54 | a | - | - | - | - ||
|XOR c, a,b<br>(c = a ^ b)|2| 0x16 | c | a | b | x | - ||
|XOR a<br>(a = a ^ Acc)|1| 0x56 | a | - | - | - | - ||

### シフト演算
|ニモニック (効果)| 命令ワード数 | opcode | operand A | operand B | operand C| 8 bit Imm| 16 bit Imm|備考|
|:-:|:-:|:-:|:-:|:-:|:-:|:-:|:-:|:-:|
|SHL a<br>(a = a << 1)|1| 0x60 | a | - | - | - | - ||
|SHR a<br>(a = a >> 1)|1| 0x70 | a | - | - | - | - ||
|SAL a<br>(a = a << 1)|1| 0x64 | a | - | - | - | - |算術シフト|
|SAR a<br>(a = a >> 1)|1| 0x74 | a | - | - | - | - |算術シフト|
|ROL a<br>(a = a << 1)|1| 0x62 | a | - | - | - | - |ロール命令|
|ROR a<br>(a = a >> 1)|1| 0x72 | a | - | - | - | - |ロール命令|
|SHL b,a<br>(b = a << 1)|2| 0x60 | b | a | x | x | - ||
|SHR b,a<br>(b = a >> 1)|2| 0x70 | b | a | x | x | - ||
|SAL b,a<br>(b = a << 1)|2| 0x64 | b | a | x | x | - |算術シフト|
|SAR b,a<br>(b = a >> 1)|2| 0x74 | b | a | x | x | - |算術シフト|
|ROL b,a<br>(b = a << 1)|2| 0x62 | b | a | x | x | - |ロール命令|
|ROR b,a<br>(b = a >> 1)|2| 0x72 | b | a | x | x | - |ロール命令|

## 転送命令
|ニモニック (効果)| 命令ワード数 | opcode | operand A | operand B | operand C| 8 bit Imm| 16 bit Imm|備考|
|:-:|:-:|:-:|:-:|:-:|:-:|:-:|:-:|:-:|
|MOV b, a<br>(b <- a)|2| 0x00 | b | a | x | x | - ||
|MOV a, Imm8<br>(a <- Imm8)|2| 0x00 | a | 0x1 | x | Imm8 | - ||
|MOV a, Imm16<br>(a <- Imm16)|3| 0x00 | a | 0x2 | x | x | Imm16 ||

## JMP命令
### 無条件JMP命令
#### 直接アドレッシング
|ニモニック (効果)| 命令ワード数 | opcode | operand A | operand B | operand C| 8 bit Imm| 16 bit Imm|備考|
|:-:|:-:|:-:|:-:|:-:|:-:|:-:|:-:|:-:|
|JMP Imm8<br>(IP <- Imm8)|2| 0x00 | 0xD | 0x1 | Imm8 | x | - ||
|JMP Imm16<br>(IP <- Imm16)|3| 0x00 | 0xD | 0x2 | x | x | Imm16 ||

#### レジスタ間接アドレッシング
|ニモニック (効果)| 命令ワード数 | opcode | operand A | operand B | operand C| 8 bit Imm| 16 bit Imm|備考|
|:-:|:-:|:-:|:-:|:-:|:-:|:-:|:-:|:-:|
|JMP a<br>(IP <- a)|2| 0x00 | 0xD | a | x | x | - ||

#### ベース修飾アドレッシング？
ベースレジスタは存在しないため，ベースレジスタに代わり汎用レジスタを使用する
|ニモニック (効果)| 命令ワード数 | opcode | operand A | operand B | operand C| 8 bit Imm| 16 bit Imm|備考|
|:-:|:-:|:-:|:-:|:-:|:-:|:-:|:-:|:-:|
|JMP a+Imm8<br>(IP <- a+Imm8)|2| 0x0A | 0xD | a | 0x1 | Imm8 | - |ベース+オフセット(Imm)|
|JMP a+Imm16<br>(IP <- a+Imm16)|3| 0x0A | 0xD | a | 0x2 | x | Imm16 |ベース+オフセット(Imm)|
|JMP a-Imm8<br>(IP <- a-Imm8)|2| 0x09 | 0xD | a | 0x1 | Imm8 | - |ベース-オフセット(Imm)|
|JMP a-Imm16<br>(IP <- a-Imm16)|3| 0x09 | 0xD | a | 0x2 | x | Imm16 |ベース-オフセット(Imm)|
|JMP a+b<br>(IP <- a+b)|2| 0x0A | 0xD | a | b | x | - ||
|JMP a-b<br>(IP <- a-b)|2| 0x09 | 0xD | a | b | x | - ||

#### IP相対アドレッシング
|ニモニック (効果)| 命令ワード数 | opcode | operand A | operand B | operand C| 8 bit Imm| 16 bit Imm|備考|
|:-:|:-:|:-:|:-:|:-:|:-:|:-:|:-:|:-:|
|JMP IP+a<br>(IP <- IP+a)|2| 0x0A | 0xD | 0xD | a | x | - ||
|JMP IP+Imm8<br>(IP <- a+Imm8)|2| 0x0A | 0xD | 0xD | 0x1 | Imm8 | - ||
|JMP IP+Imm16<br>(IP <- a+Imm16)|3| 0x0A | 0xD | 0xD | 0x2 | x | Imm16 ||
|JMP IP-a<br>(IP <- IP-a)|2| 0x09 | 0xD | 0xD | a | x | - ||
|JMP IP-Imm8<br>(IP <- a-Imm8)|2| 0x09 | 0xD | 0xD | 0x1 | Imm8 | - ||
|JMP IP-Imm16<br>(IP <- a-Imm16)|3| 0x09 | 0xD | 0xD | 0x2 | x | Imm16 ||

### 条件JMP命令
NLP-16Aではすべての命令を条件実行可能なため，通常のJMP命令のFlagフィールドに条件を指定し，条件JMPを実現する．

## サブルーチン命令
### サブルーチンコール命令
#### 直接アドレッシング
|ニモニック (効果)| 命令ワード数 | opcode | operand A | operand B | operand C| 8 bit Imm| 16 bit Imm|備考|
|:-:|:-:|:-:|:-:|:-:|:-:|:-:|:-:|:-:|
|CALL Imm8<br>(IP <- Imm8)|2| 0xB0 | 0xD | 0x1 | Imm8 | x | - ||
|CALL Imm16<br>(IP <- Imm16)|3| 0xB0 | 0xD | 0x2 | x | Imm16 | - ||

#### レジスタ間接アドレッシング
|ニモニック (効果)| 命令ワード数 | opcode | operand A | operand B | operand C| 8 bit Imm| 16 bit Imm|備考|
|:-:|:-:|:-:|:-:|:-:|:-:|:-:|:-:|:-:|
|CALL a<br>(IP <- a)|2| 0xB0 | 0xD | a | x | x | - ||

#### ベース修飾アドレッシング？
ベースレジスタは存在しないため，ベースレジスタに代わり汎用レジスタを使用する
|ニモニック (効果)| 命令ワード数 | opcode | operand A | operand B | operand C| 8 bit Imm| 16 bit Imm|備考|
|:-:|:-:|:-:|:-:|:-:|:-:|:-:|:-:|:-:|
|CALL a+Imm8<br>(IP <- a+Imm8)|2| 0xBA | 0xD | a | 0x1 | Imm8 | - |ベース+オフセット(Imm)|
|CALL a+Imm16<br>(IP <- a+Imm16)|3| 0xBA | 0xD | a | 0x2 | x | Imm16 |ベース+オフセット(Imm)|
|CALL a-Imm8<br>(IP <- a-Imm8)|2| 0xB9 | 0xD | a | 0x1 | Imm8 | - |ベース-オフセット(Imm)|
|CALL a-Imm16<br>(IP <- a-Imm16)|3| 0xB9 | 0xD | a | 0x2 | x | Imm16 |ベース-オフセット(Imm)|
|CALL a+b<br>(IP <- a+b)|2| 0xBA | 0xD | a | b | x | - ||
|CALL a-b<br>(IP <- a-b)|2| 0xB9 | 0xD | a | b | x | - ||

#### IP相対アドレッシング
|ニモニック (効果)| 命令ワード数 | opcode | operand A | operand B | operand C| 8 bit Imm| 16 bit Imm|備考|
|:-:|:-:|:-:|:-:|:-:|:-:|:-:|:-:|:-:|
|CALL IP+a<br>(IP <- IP+a)|2| 0xBA | 0xD | 0xD | a | x | - ||
|CALL IP+Imm8<br>(IP <- a+Imm8)|2| 0xBA | 0xD | 0xD | 0x1 | Imm8 | - ||
|CALL IP+Imm16<br>(IP <- a+Imm16)|3| 0xBA | 0xD | 0xD | 0x2 | x | Imm16 ||
|CALL IP-a<br>(IP <- IP-a)|2| 0xB9 | 0xD | 0xD | a | x | - ||
|CALL IP-Imm8<br>(IP <- a-Imm8)|2| 0xB9 | 0xD | 0xD | 0x1 | Imm8 | - ||
|CALL IP-Imm16<br>(IP <- a-Imm16)|3| 0xB9 | 0xD | 0xD | 0x2 | x | Imm16 ||

#### 条件サブルーチンコール
条件JMP同様．

### リターン命令
|ニモニック (効果)| 命令ワード数 | opcode | operand A | operand B | operand C| 8 bit Imm| 16 bit Imm|備考|
|:-:|:-:|:-:|:-:|:-:|:-:|:-:|:-:|:-:|
|RET|1| 0xC0 | 0xD | - | - | - | - ||

## メモリ操作
### LOAD命令
#### 直接アドレッシング
|ニモニック (効果)| 命令ワード数 | opcode | operand A | operand B | operand C| 8 bit Imm| 16 bit Imm|備考|
|:-:|:-:|:-:|:-:|:-:|:-:|:-:|:-:|:-:|
|LOAD a,Imm8<br>(a <-MEM\[Imm8])|2| 0x80 | a | 0x1 | Imm8 | x | - ||
|LOAD a,Imm16<br>(a <-MEM\[Imm16])|3| 0x80 | a | 0x2 | x | x | Imm16 ||

#### レジスタ間接アドレッシング
|ニモニック (効果)| 命令ワード数 | opcode | operand A | operand B | operand C| 8 bit Imm| 16 bit Imm|備考|
|:-:|:-:|:-:|:-:|:-:|:-:|:-:|:-:|:-:|
|LOAD a,b<br>(a <-MEM\[b])|2| 0x80 | a | b | x | x | - ||

#### ベース修飾アドレッシング？
ベースレジスタは存在しないため，ベースレジスタに代わり汎用レジスタを使用する
|ニモニック (効果)| 命令ワード数 | opcode | operand A | operand B | operand C| 8 bit Imm| 16 bit Imm|備考|
|:-:|:-:|:-:|:-:|:-:|:-:|:-:|:-:|:-:|
|LOAD a,b+Imm8<br>(a <-MEM\[b+Imm8])|2| 0x8A | a | b | 0x1 | Imm8 | - |ベース+オフセット(Imm)|
|LOAD a,b+Imm16<br>(a <-MEM\[b+Imm16])|3| 0x8A | a | b | 0x2 | x | Imm16 |ベース+オフセット(Imm)|
|LOAD a,b-Imm8<br>(a <-MEM\[b-Imm8])|2| 0x89 | a | b | 0x1 | Imm8 | - |ベース-オフセット(Imm)|
|LOAD a,b-Imm16<br>(a <-MEM\[b-Imm16])|3| 0x89 | a | b | 0x2 | x | Imm16 |ベース-オフセット(Imm)|
|LOAD a,b+c<br>(a <-MEM\[b+c])|2| 0x8A | a | b | c | x | - ||
|LOAD a,b-c<br>(a <-MEM\[b-c])|2| 0x89 | a | b | c | x | - ||

#### IP相対アドレッシング
|ニモニック (効果)| 命令ワード数 | opcode | operand A | operand B | operand C| 8 bit Imm| 16 bit Imm|備考|
|:-:|:-:|:-:|:-:|:-:|:-:|:-:|:-:|:-:|
|LOAD a,IP+b|2| 0x8A | a | 0xD | b | x | - ||
|LOAD a,IP+Imm8|2| 0x8A | a | 0xD | 0x1 | Imm8 | - ||
|LOAD a,IP+Imm16|3| 0x8A | a | 0xD | 0x2 | x | Imm16 ||
|LOAD a,IP-b<br>|2| 0x89 | a | 0xD | b | x | - ||
|LOAD a,IP-Imm8|2| 0x89 | a | 0xD | 0x1 | Imm8 | - ||
|LOAD a,IP-Imm16|3| 0x89 | a | 0xD | 0x2 | x | Imm16 ||

#### SP相対アドレッシング
|ニモニック (効果)| 命令ワード数 | opcode | operand A | operand B | operand C| 8 bit Imm| 16 bit Imm|備考|
|:-:|:-:|:-:|:-:|:-:|:-:|:-:|:-:|:-:|
|LOAD a,SP+b|2| 0x8A | a | 0xE | b | x | - ||
|LOAD a,SP+Imm8|2| 0x8A | a | 0xE | 0x1 | Imm8 | - ||
|LOAD a,SP+Imm16|3| 0x8A | a | 0xE | 0x2 | x | Imm16 ||
|LOAD a,SP-b<br>|2| 0x89 | a | 0xE | b | x | - ||
|LOAD a,SP-Imm8|2| 0x89 | a | 0xE | 0x1 | Imm8 | - ||
|LOAD a,SP-Imm16|3| 0x89 | a | 0xE | 0x2 | x | Imm16 ||

### STORE命令
LOADのopcode最上位ニブルが0x9となる．例えばSP相対の`STORE a,SP+Imm8`であれば以下のようになる．
|ニモニック (効果)| 命令ワード数 | opcode | operand A | operand B | operand C| 8 bit Imm| 16 bit Imm|備考|
|:-:|:-:|:-:|:-:|:-:|:-:|:-:|:-:|:-:|
|STORE a,SP+Imm8<br>(MEM\[SP+Imm8] <- a)|2| 0x9A | a | 0xE | 0x1 | Imm8 | - ||

その他のアドレッシングでもLOAD同様である．

## POP，PUSH命令
### POP
|ニモニック (効果)| 命令ワード数 | opcode | operand A | operand B | operand C| 8 bit Imm| 16 bit Imm|備考|
|:-:|:-:|:-:|:-:|:-:|:-:|:-:|:-:|:-:|
|POP a|1| 0xD0 | a | - | - | - | - ||
### PUSH
|ニモニック (効果)| 命令ワード数 | opcode | operand A | operand B | operand C| 8 bit Imm| 16 bit Imm|備考|
|:-:|:-:|:-:|:-:|:-:|:-:|:-:|:-:|:-:|
|PUSH a|1| 0xC0 | a | - | - | - | - ||

## 比較命令
### CMP
|ニモニック (効果)| 命令ワード数 | opcode | operand A | operand B | operand C| 8 bit Imm| 16 bit Imm|備考|
|:-:|:-:|:-:|:-:|:-:|:-:|:-:|:-:|:-:|
|CMP a, b|2| 0x09 | 0xF | a | b | x | - ||

#### 即値とのCMP
|ニモニック (効果)| 命令ワード数 | opcode | operand A | operand B | operand C| 8 bit Imm| 16 bit Imm|備考|
|:-:|:-:|:-:|:-:|:-:|:-:|:-:|:-:|:-:|
|CMP a, Imm8|2| 0x09 | 0xF | a | 0x1 | Imm8 | - ||
|CMP a, Imm8|3| 0x09 | 0xF | a | 0x2 | x | Imm16 ||

## 割り込み命令
### 割り込み許可
|ニモニック (効果)| 命令ワード数 | opcode | operand A | operand B | operand C| 8 bit Imm| 16 bit Imm|備考|
|:-:|:-:|:-:|:-:|:-:|:-:|:-:|:-:|:-:|
|STI|1| 0xFF | x | - | - | - | - ||
### 割り込み禁止
|ニモニック (効果)| 命令ワード数 | opcode | operand A | operand B | operand C| 8 bit Imm| 16 bit Imm|備考|
|:-:|:-:|:-:|:-:|:-:|:-:|:-:|:-:|:-:|
|CLI|1| 0xFE | x | - | - | - | - ||
### 割り込み復帰
|ニモニック (効果)| 命令ワード数 | opcode | operand A | operand B | operand C| 8 bit Imm| 16 bit Imm|備考|
|:-:|:-:|:-:|:-:|:-:|:-:|:-:|:-:|:-:|
|IRET|1| 0xE0 | 0xD | - | - | - | - ||
### ソフトウェア割り込み
JMP先はハードウェア割り込みと同様にIV Regにある番地に飛ぶ．
|ニモニック (効果)| 命令ワード数 | opcode | operand A | operand B | operand C| 8 bit Imm| 16 bit Imm|備考|
|:-:|:-:|:-:|:-:|:-:|:-:|:-:|:-:|:-:|
|INT|1| 0xFC | x | - | - | - | - ||

以上．

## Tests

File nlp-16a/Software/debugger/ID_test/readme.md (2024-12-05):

# 命令デコーダテスト
命令デコーダの動作テスト
テスト結果のリファレンスと実機の動作を比較し，テストを行う

## ハードウェア構成

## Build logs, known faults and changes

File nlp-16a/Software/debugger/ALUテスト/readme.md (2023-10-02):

# ALUテスト  

ALUハードウェアの自動テストを行います．

## ハードウェア構成

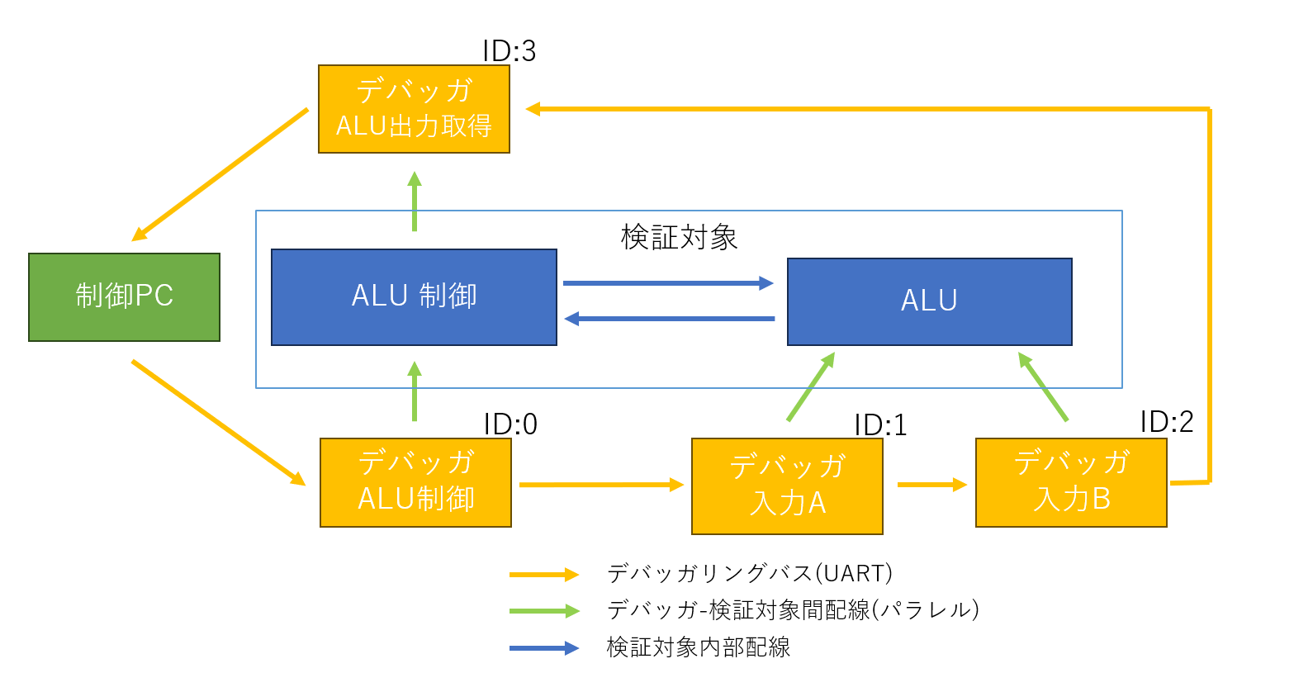
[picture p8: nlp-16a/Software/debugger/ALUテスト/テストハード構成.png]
テストハード構成
  

# 実行シーケンス

```
内容                    :   コマンド        :   レスポンス(期待する値)
----------------------------------------------------------------------
全体設定
全体リセット            :   FE-0F-0000      :   FE-0F-0000
デバイス認識            :   FE-00-0000      :   FE-00-0004

状態取得(全デバッガに対して繰り返し)
入出力方向取得          :   (ID)-01-0000    :   FF-01-0000
入力状態取得            :   (ID)-04-0000    :   FF-04-(現在の入力状態)
出力状態取得            :   (ID)-05-0000    :   FF-05-0000

入出力設定
ALU制御入出力設定       :   00-02-0FFF      :   FF-02-0FFF
入力A入出力設定         :   01-02-FFFF      :   FF-02-FFFF
入力B入出力設定         :   02-02-FFFF      :   FF-02-FFFF
ALU出力入出力設定       :   03-02-0000      :   FF-02-0000

テスト(ファンクション，値を変更し繰り返し)
ALUテスト機能設定       :   00-03-(機能)    :   FF-03-(機能)
入力Aテスト値設定       :   01-03-(値)      :   FF-03-(値)
入力Bテスト値設定       :   02-03-(値)      :   FF-03-(値)
ALU出力取得             :   03-04-0000      :   FF-04-(正常な演算結果)
```

## テスト機能

・A<<1  
・A>>1  
・A+B  
・A-B  
・A & B  
・A | B  
・A ^ B  
・A  
・~A  
・A + 1  
・A - 1

main.py内のFuncに追記すれば他の命令もテスト可能．

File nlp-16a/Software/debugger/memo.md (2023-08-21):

# メモ  
PC側はタイムアウト設定必須  
リングバス接続断を検出したい  
## 目指す入出力
### 構成  

・スレーブ2台  
・スレーブ1 16bit全出力  
・スレーブ2 16bit全入力  

```
    ┌───┐  ┌────┐  ┌────┐  
PC⇔│master│→│スレーブ│→│スレーブ│─┐  
    │      │←│ID 0    │←│ID 1    │─┘  
    └───┘  └────┘  └────┘  
                      ↓            ↓  
                     NLP-16Aの対象I/Oへ  
```

### 初期化フェーズ

マスタ出力  
FE-00-0000  
スレーブ出力  
FE-00-0002  
0002が返ってきているためスレーブ台数は2台と推定できる．  

### 機器状態取得
未定  

### 入出力方向取得フェーズ
#### スレーブ1
マスタ出力  
00-01-0000  
スレーブ出力  
FF-01-XXXX  

#### スレーブ2
マスタ出力  
01-01-0000  
スレーブ出力  
FF-01-XXXX

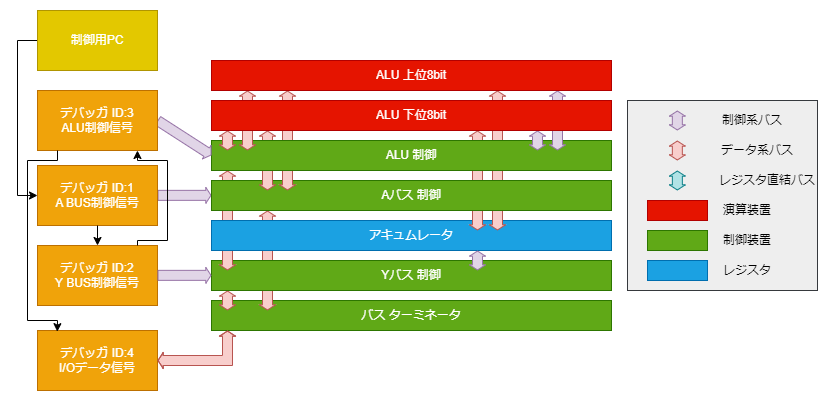
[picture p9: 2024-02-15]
nlp-16a/Software/debugger/ALU-データバステスト/テストハード構成.png

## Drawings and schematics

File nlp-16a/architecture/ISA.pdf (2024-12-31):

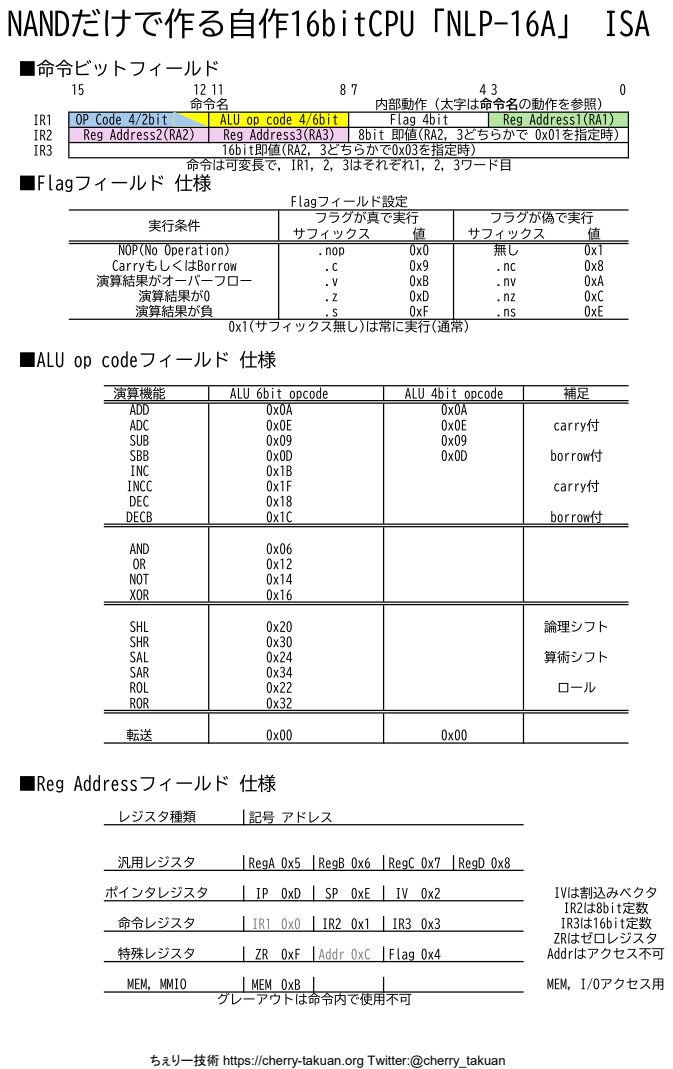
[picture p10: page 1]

ちぇりー技術 https://cherry-takuan.org Twitter:@cherry_takuan

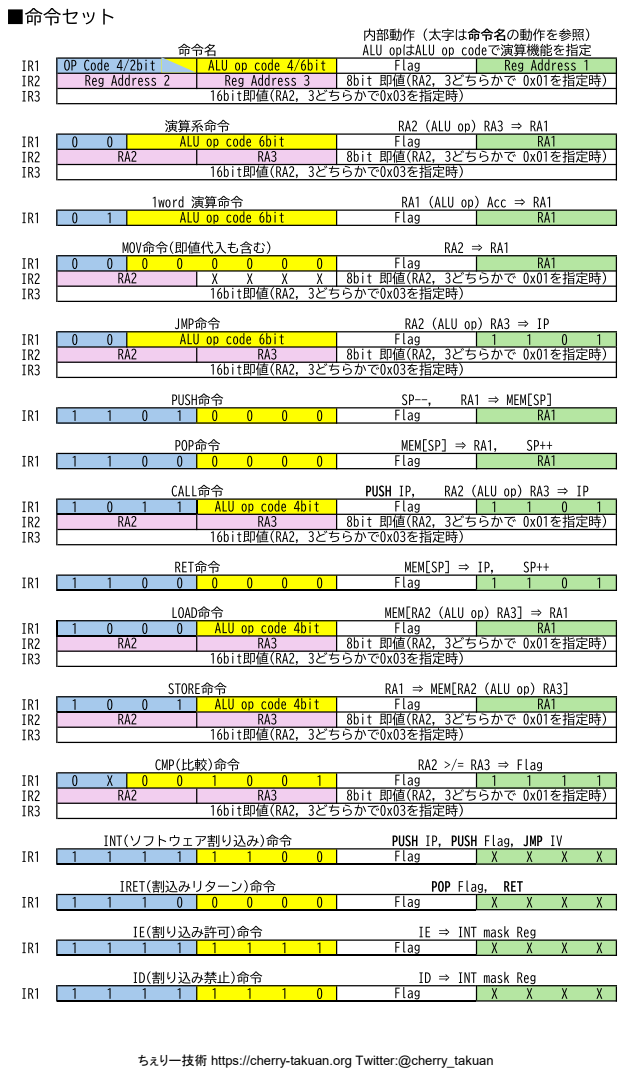
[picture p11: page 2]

ちぇりー技術 https://cherry-takuan.org Twitter:@cherry_takuan

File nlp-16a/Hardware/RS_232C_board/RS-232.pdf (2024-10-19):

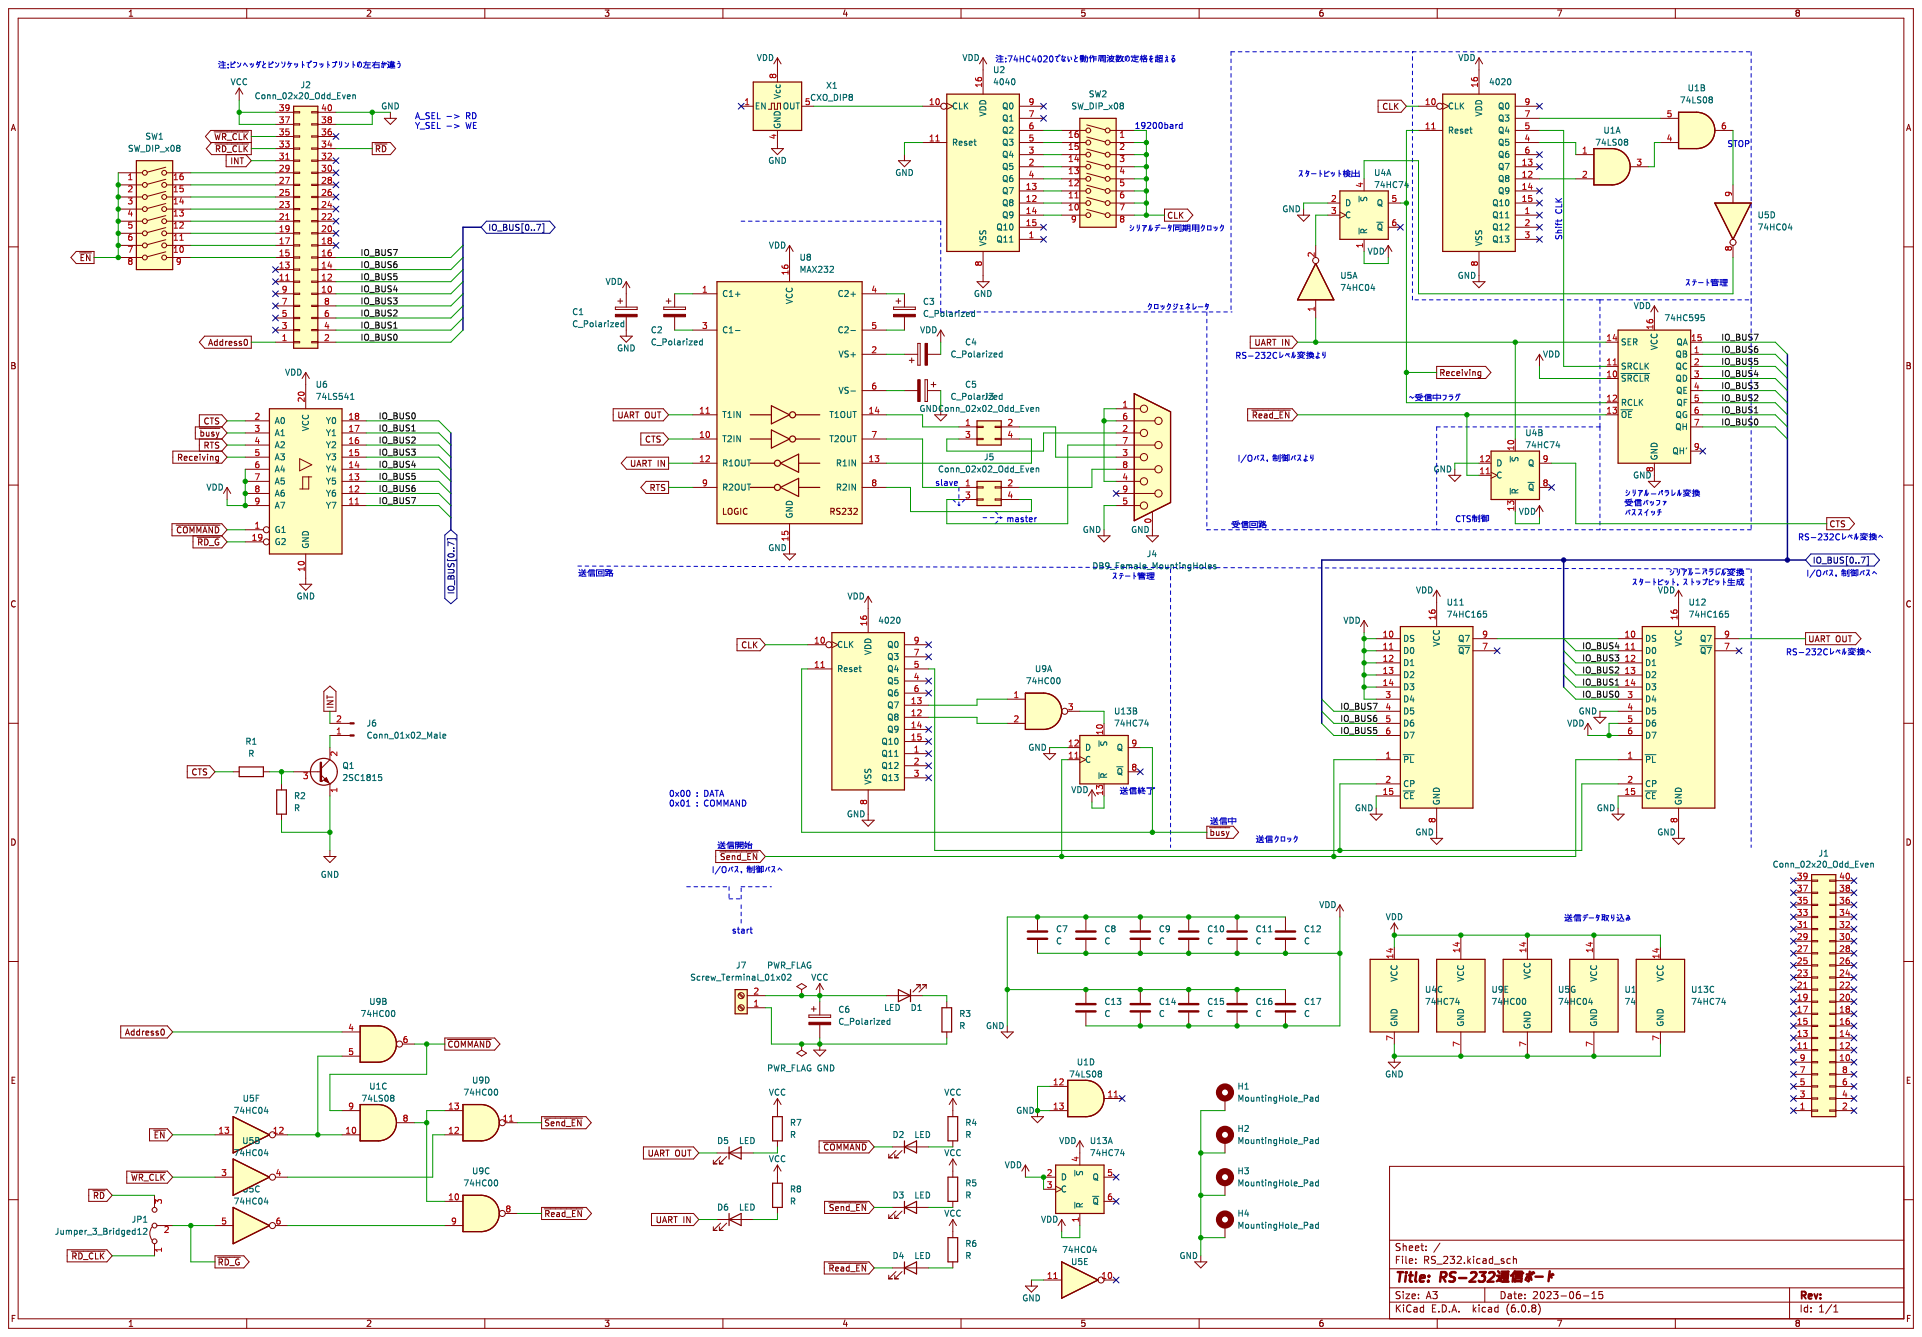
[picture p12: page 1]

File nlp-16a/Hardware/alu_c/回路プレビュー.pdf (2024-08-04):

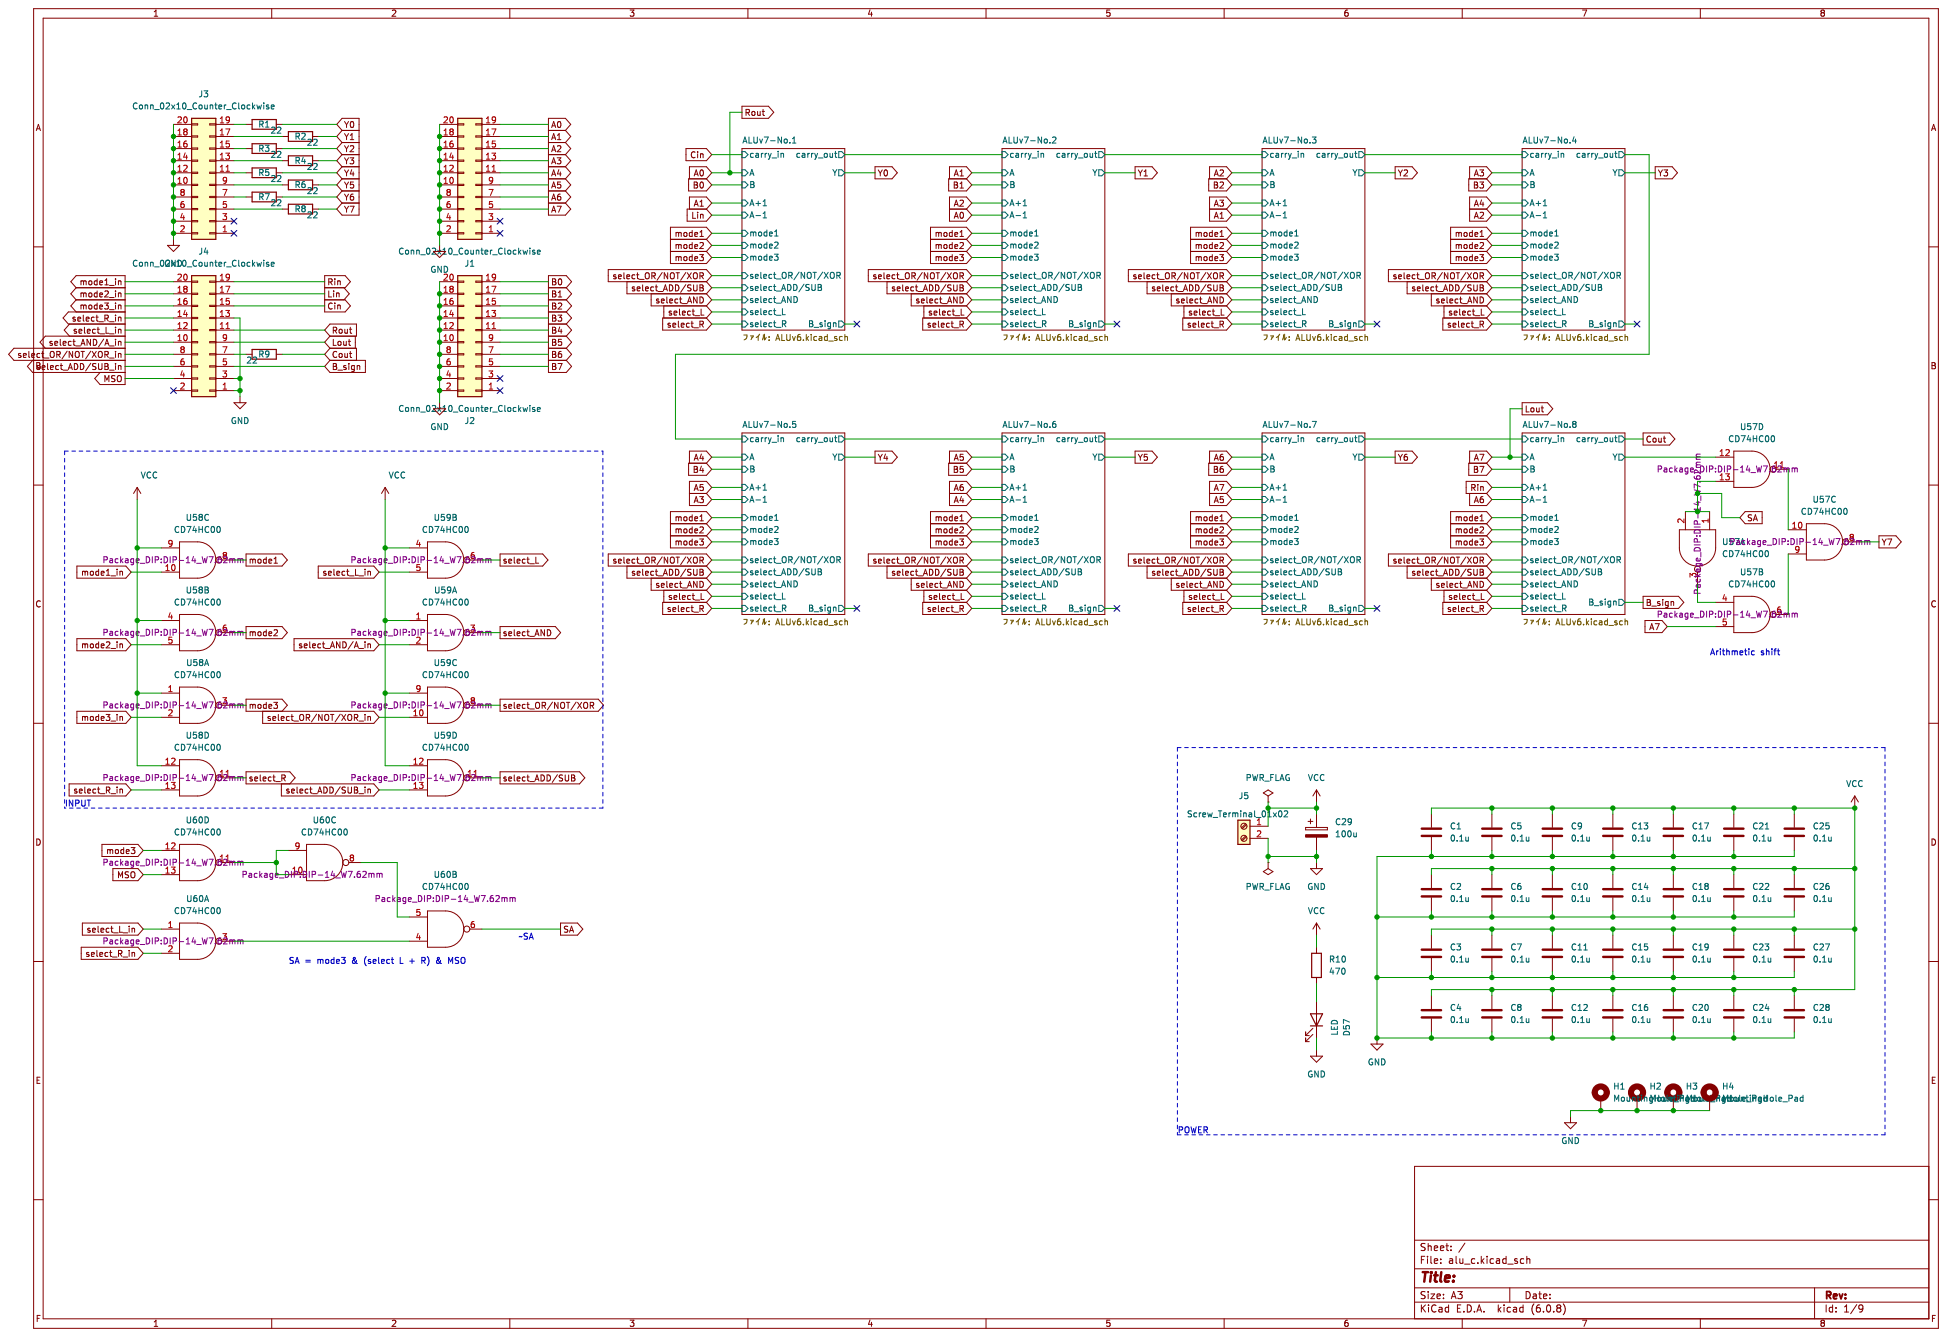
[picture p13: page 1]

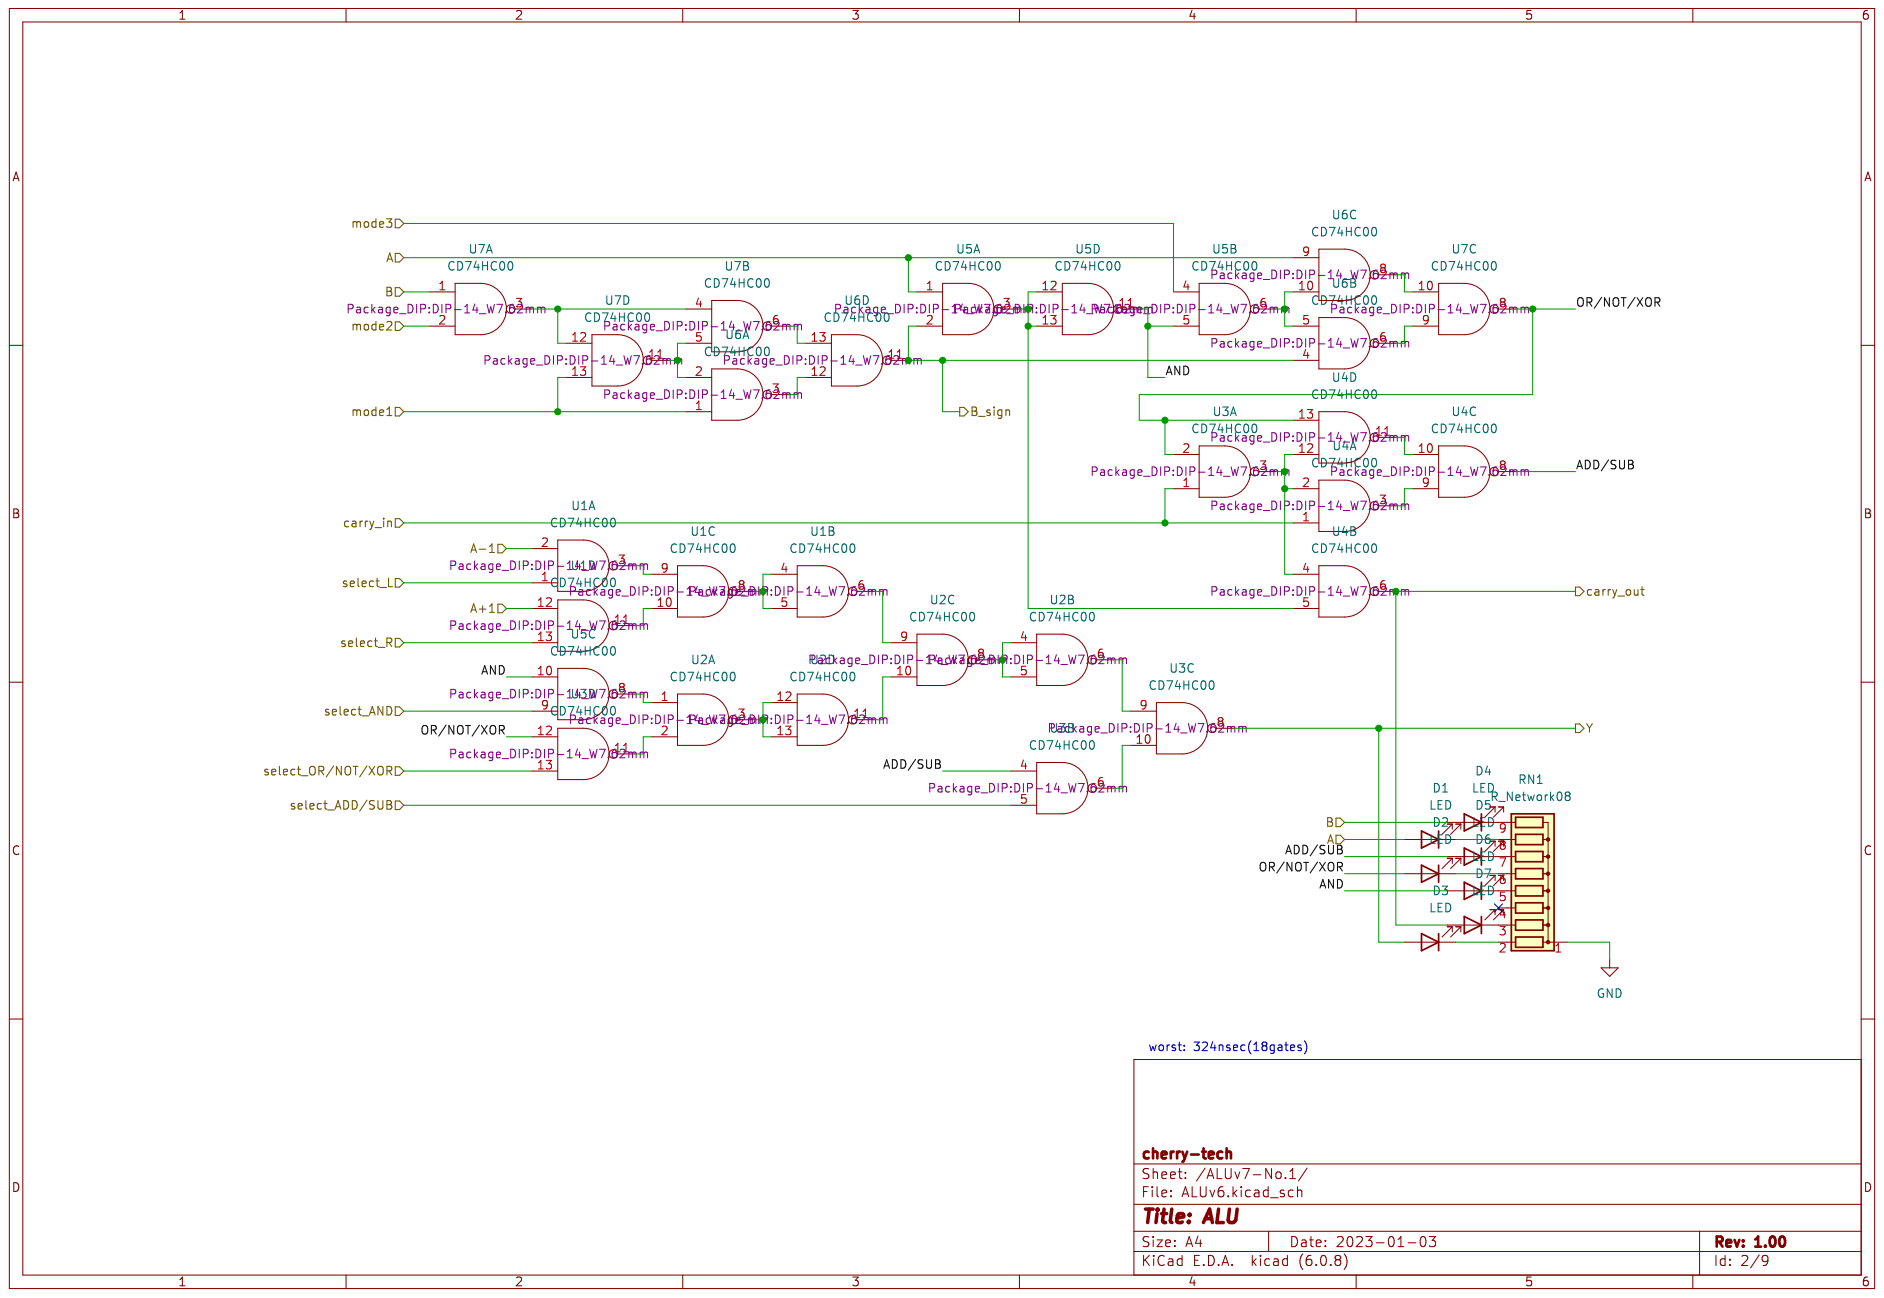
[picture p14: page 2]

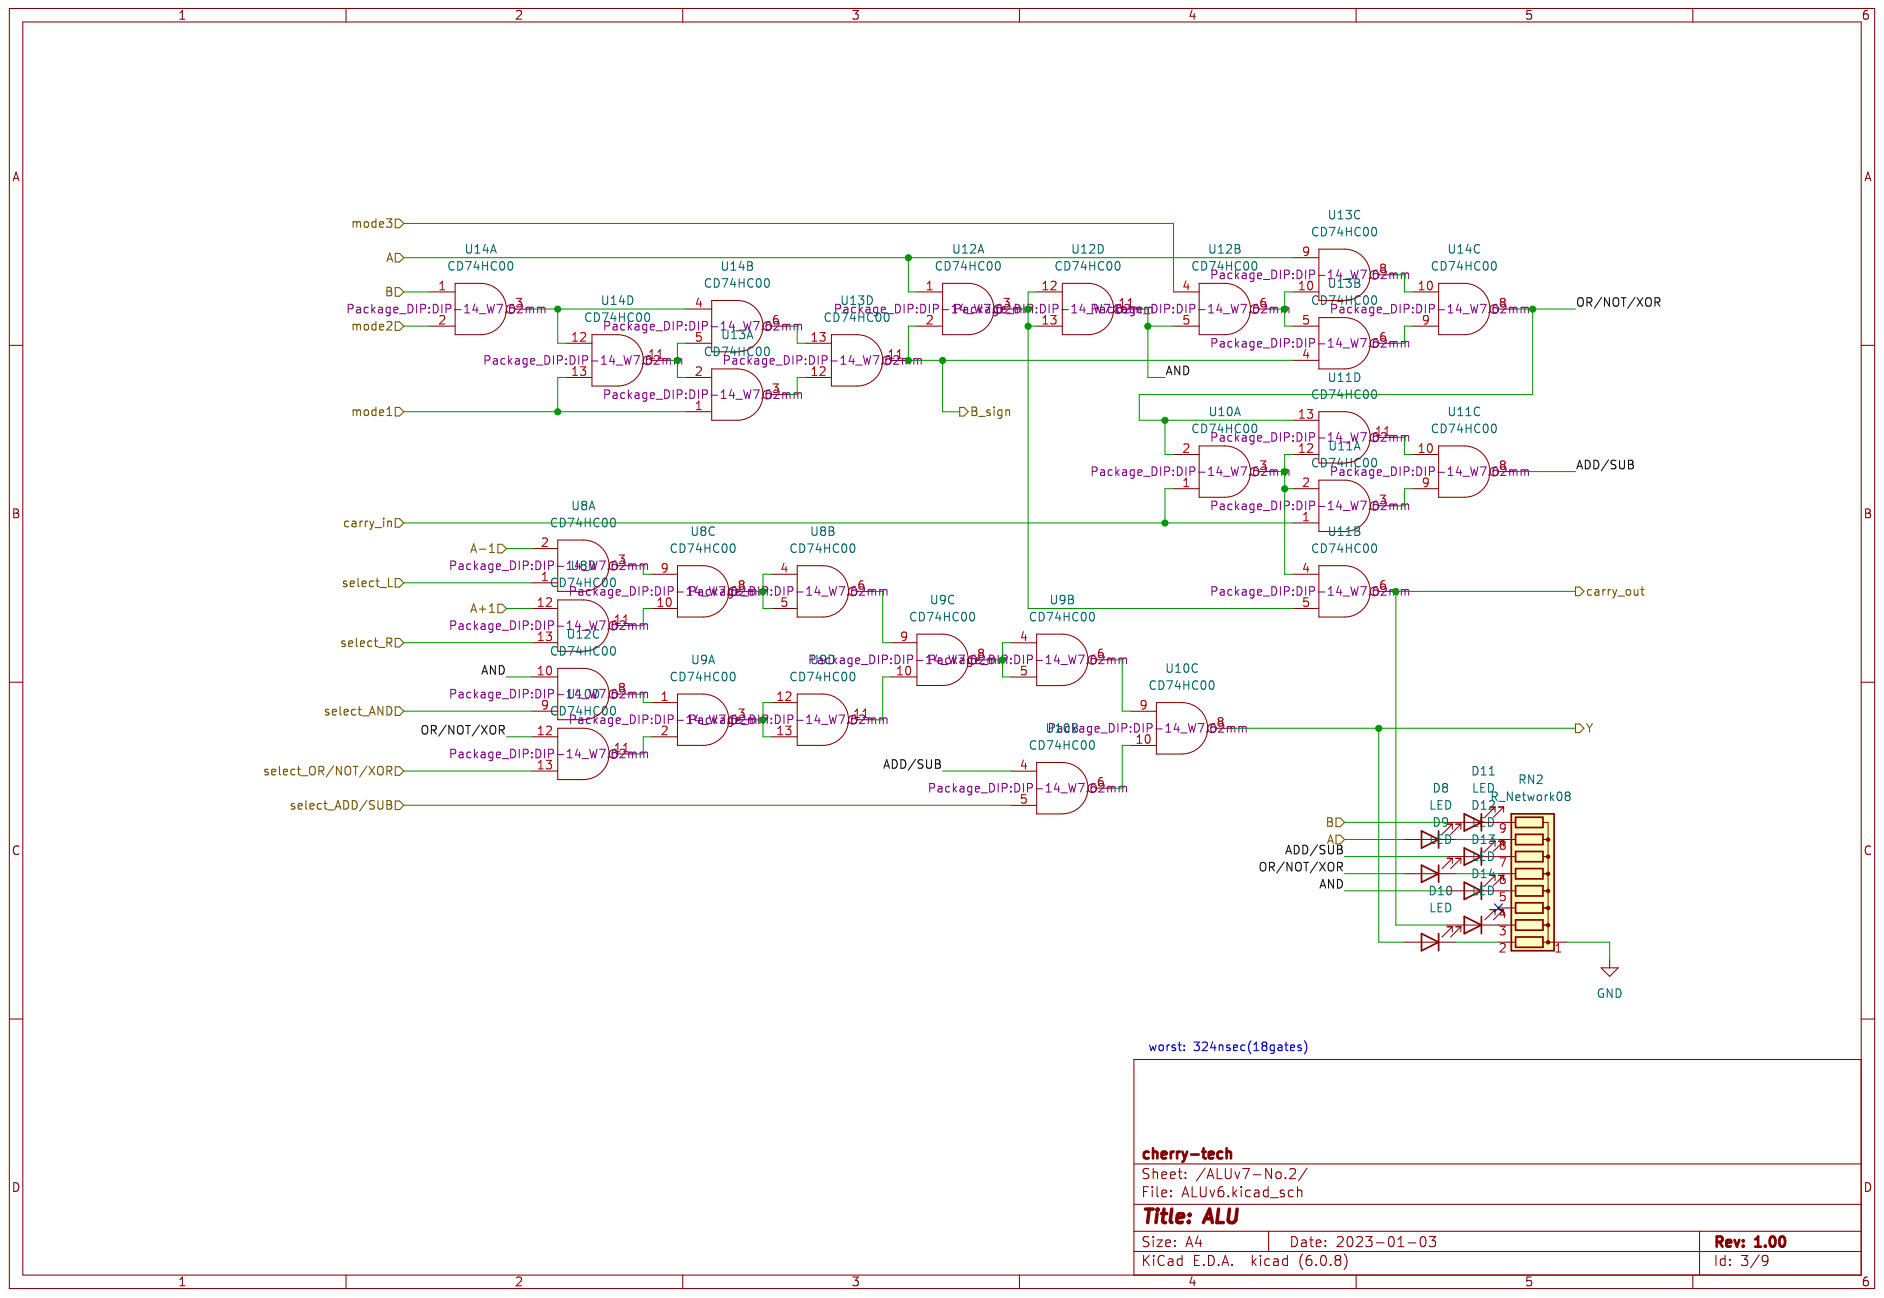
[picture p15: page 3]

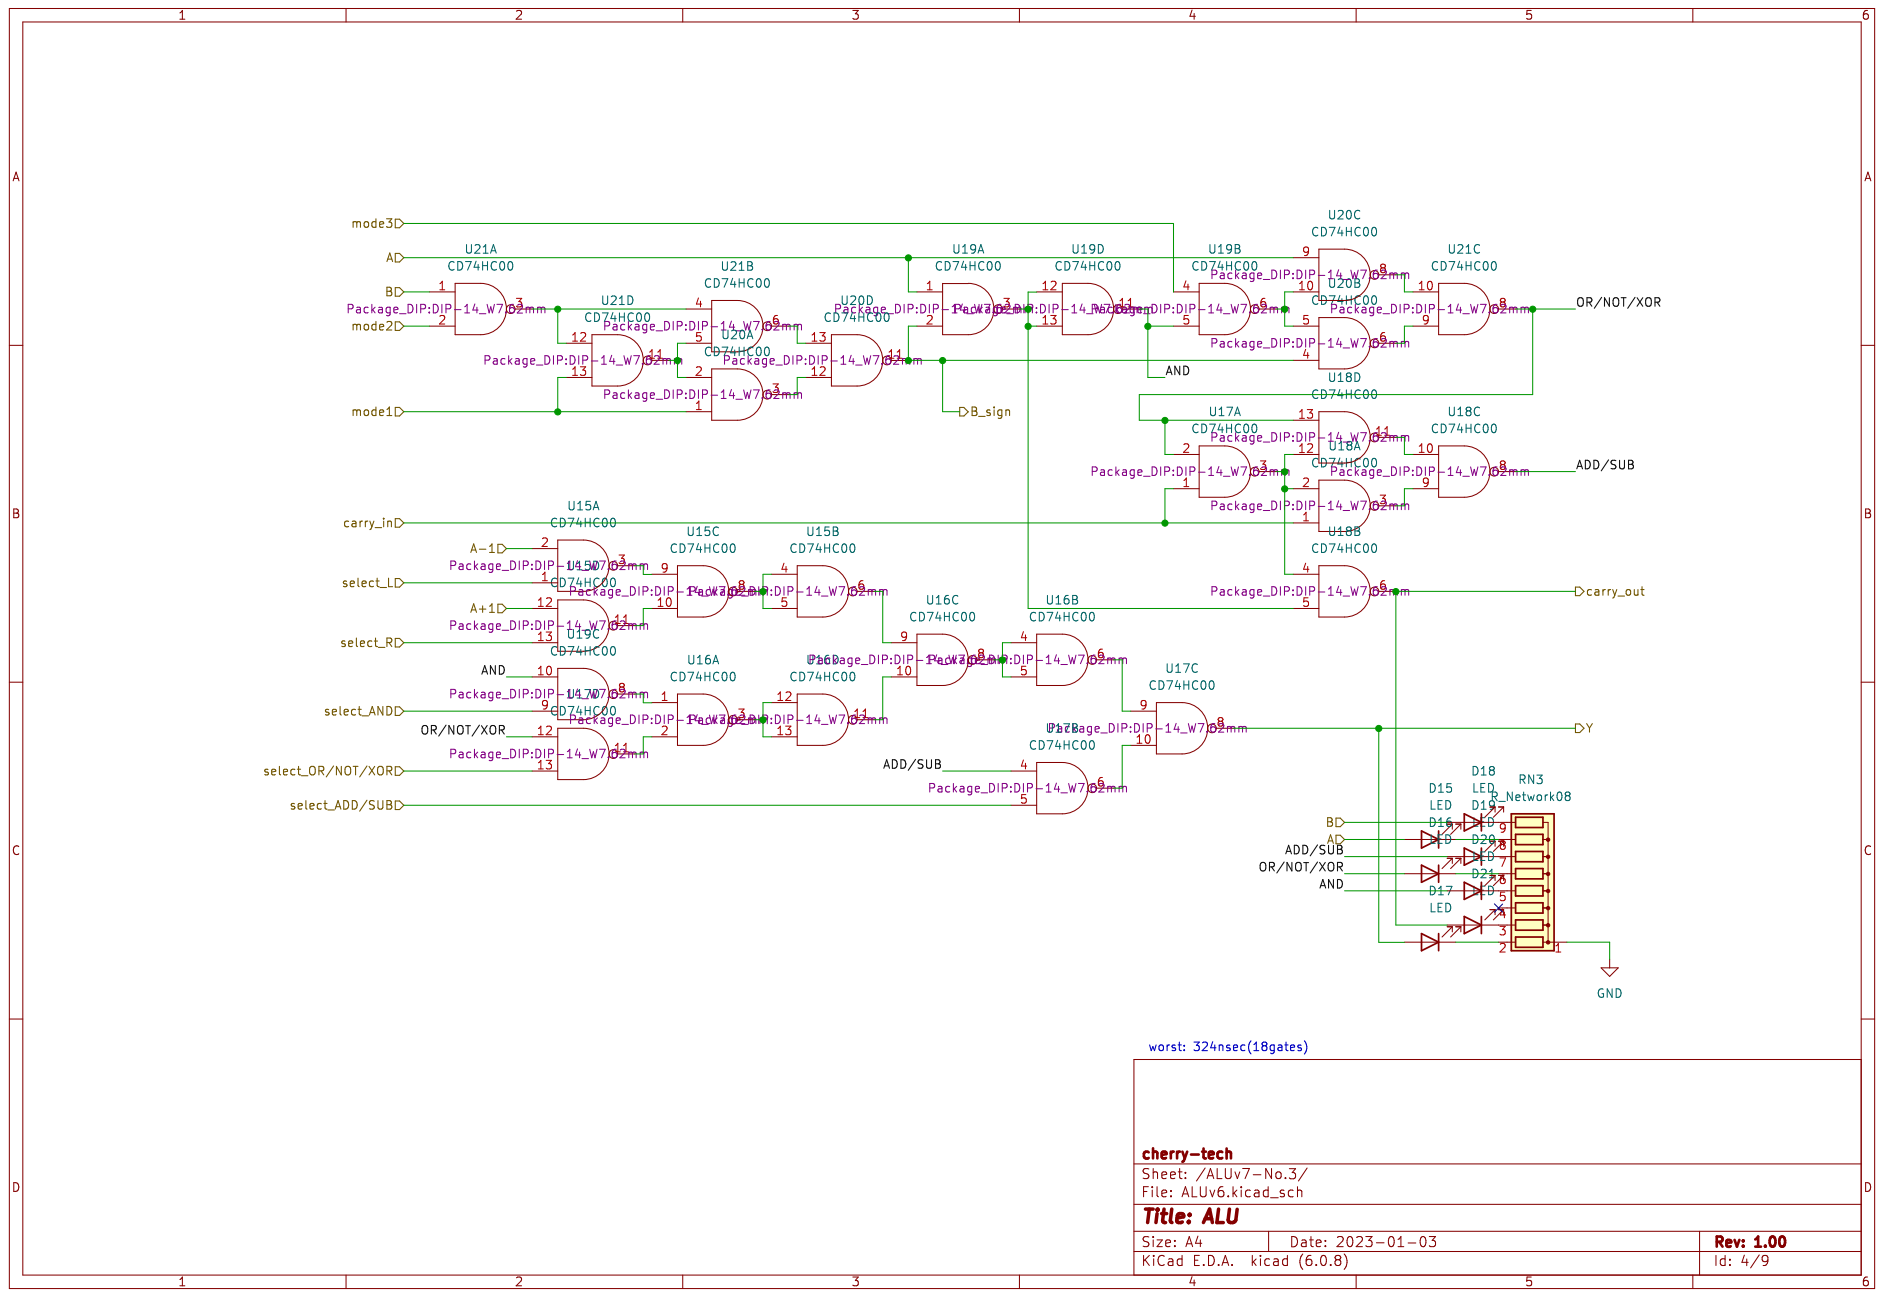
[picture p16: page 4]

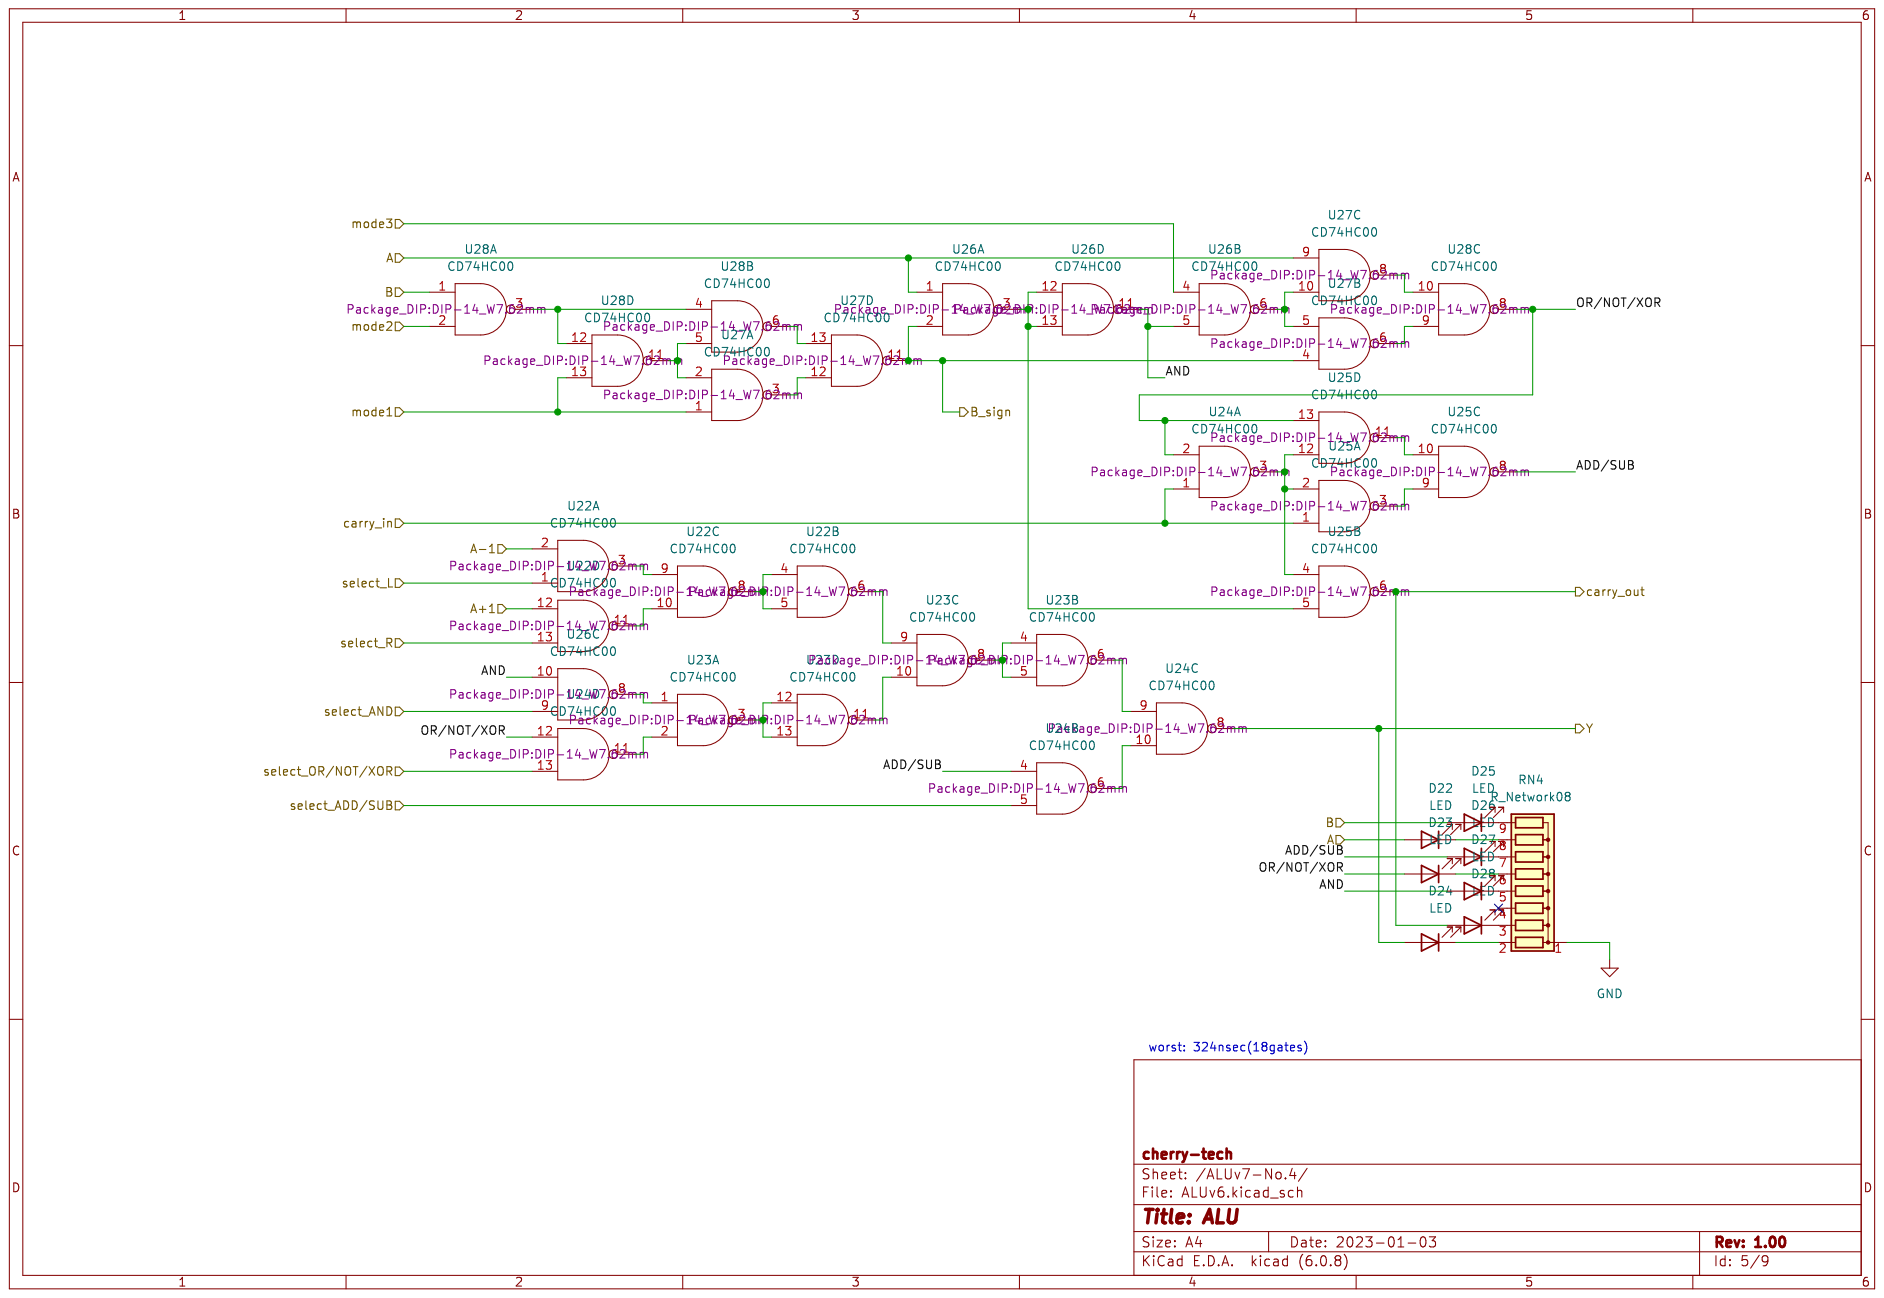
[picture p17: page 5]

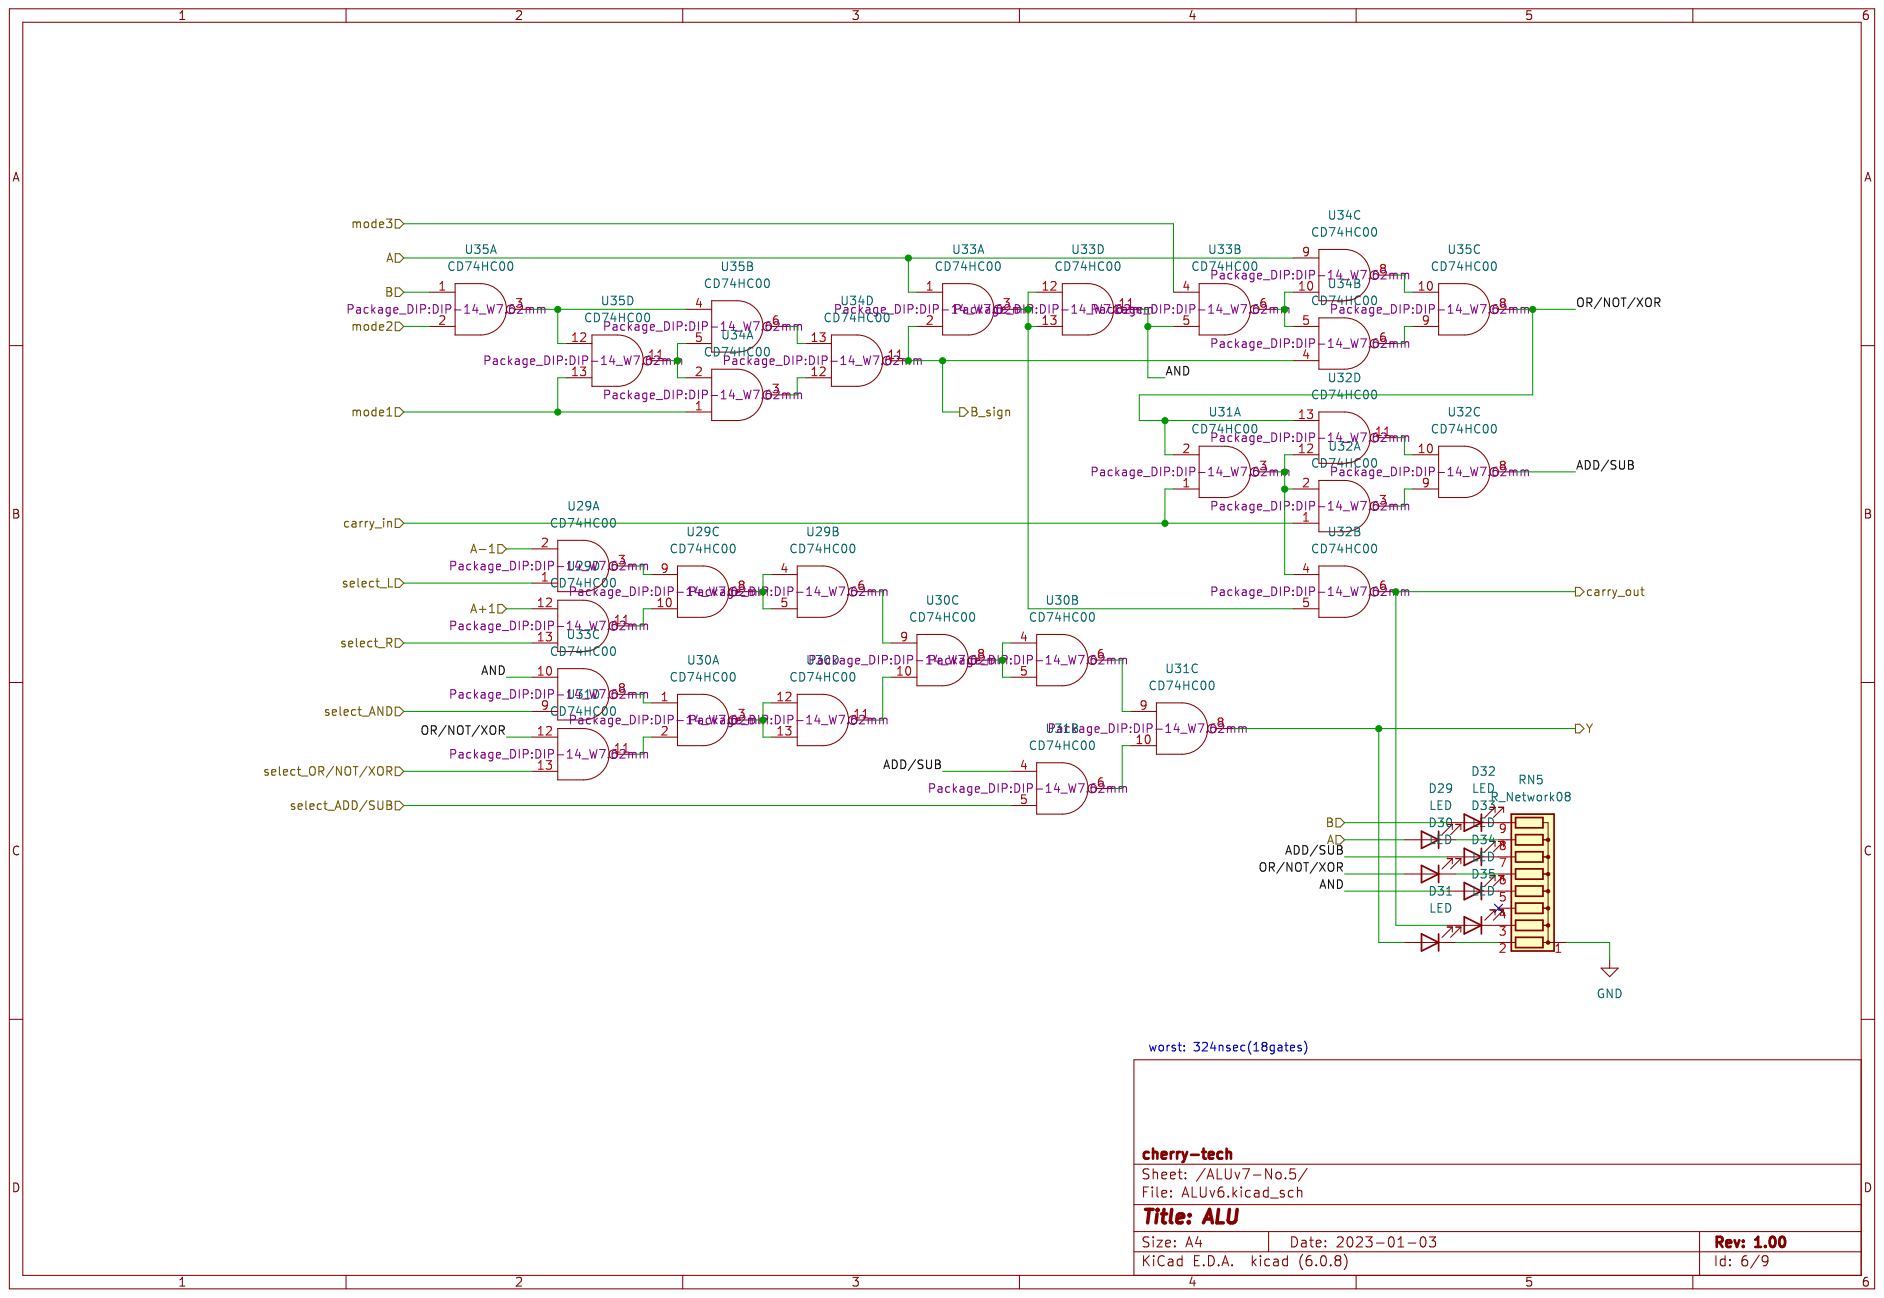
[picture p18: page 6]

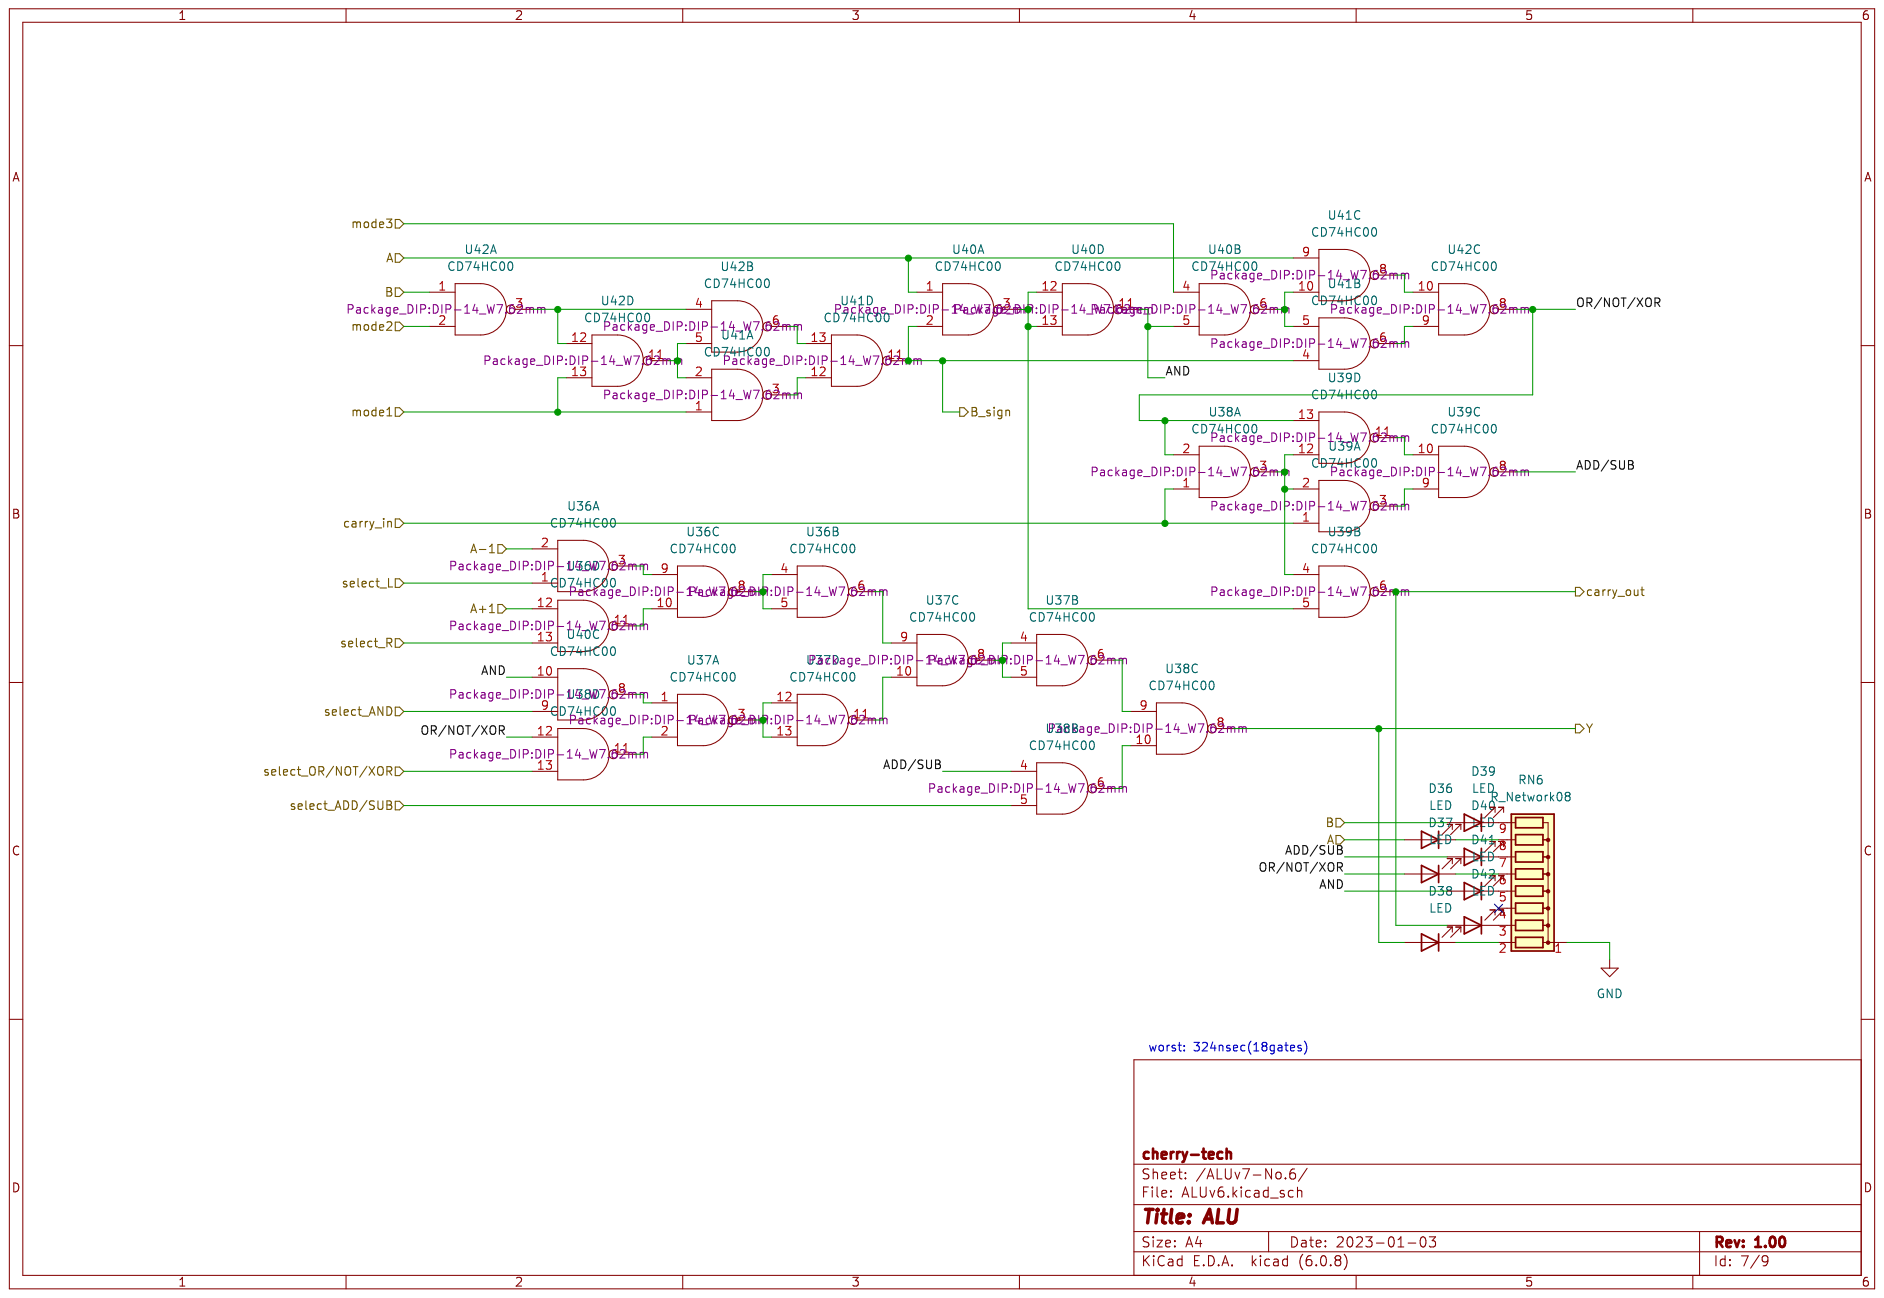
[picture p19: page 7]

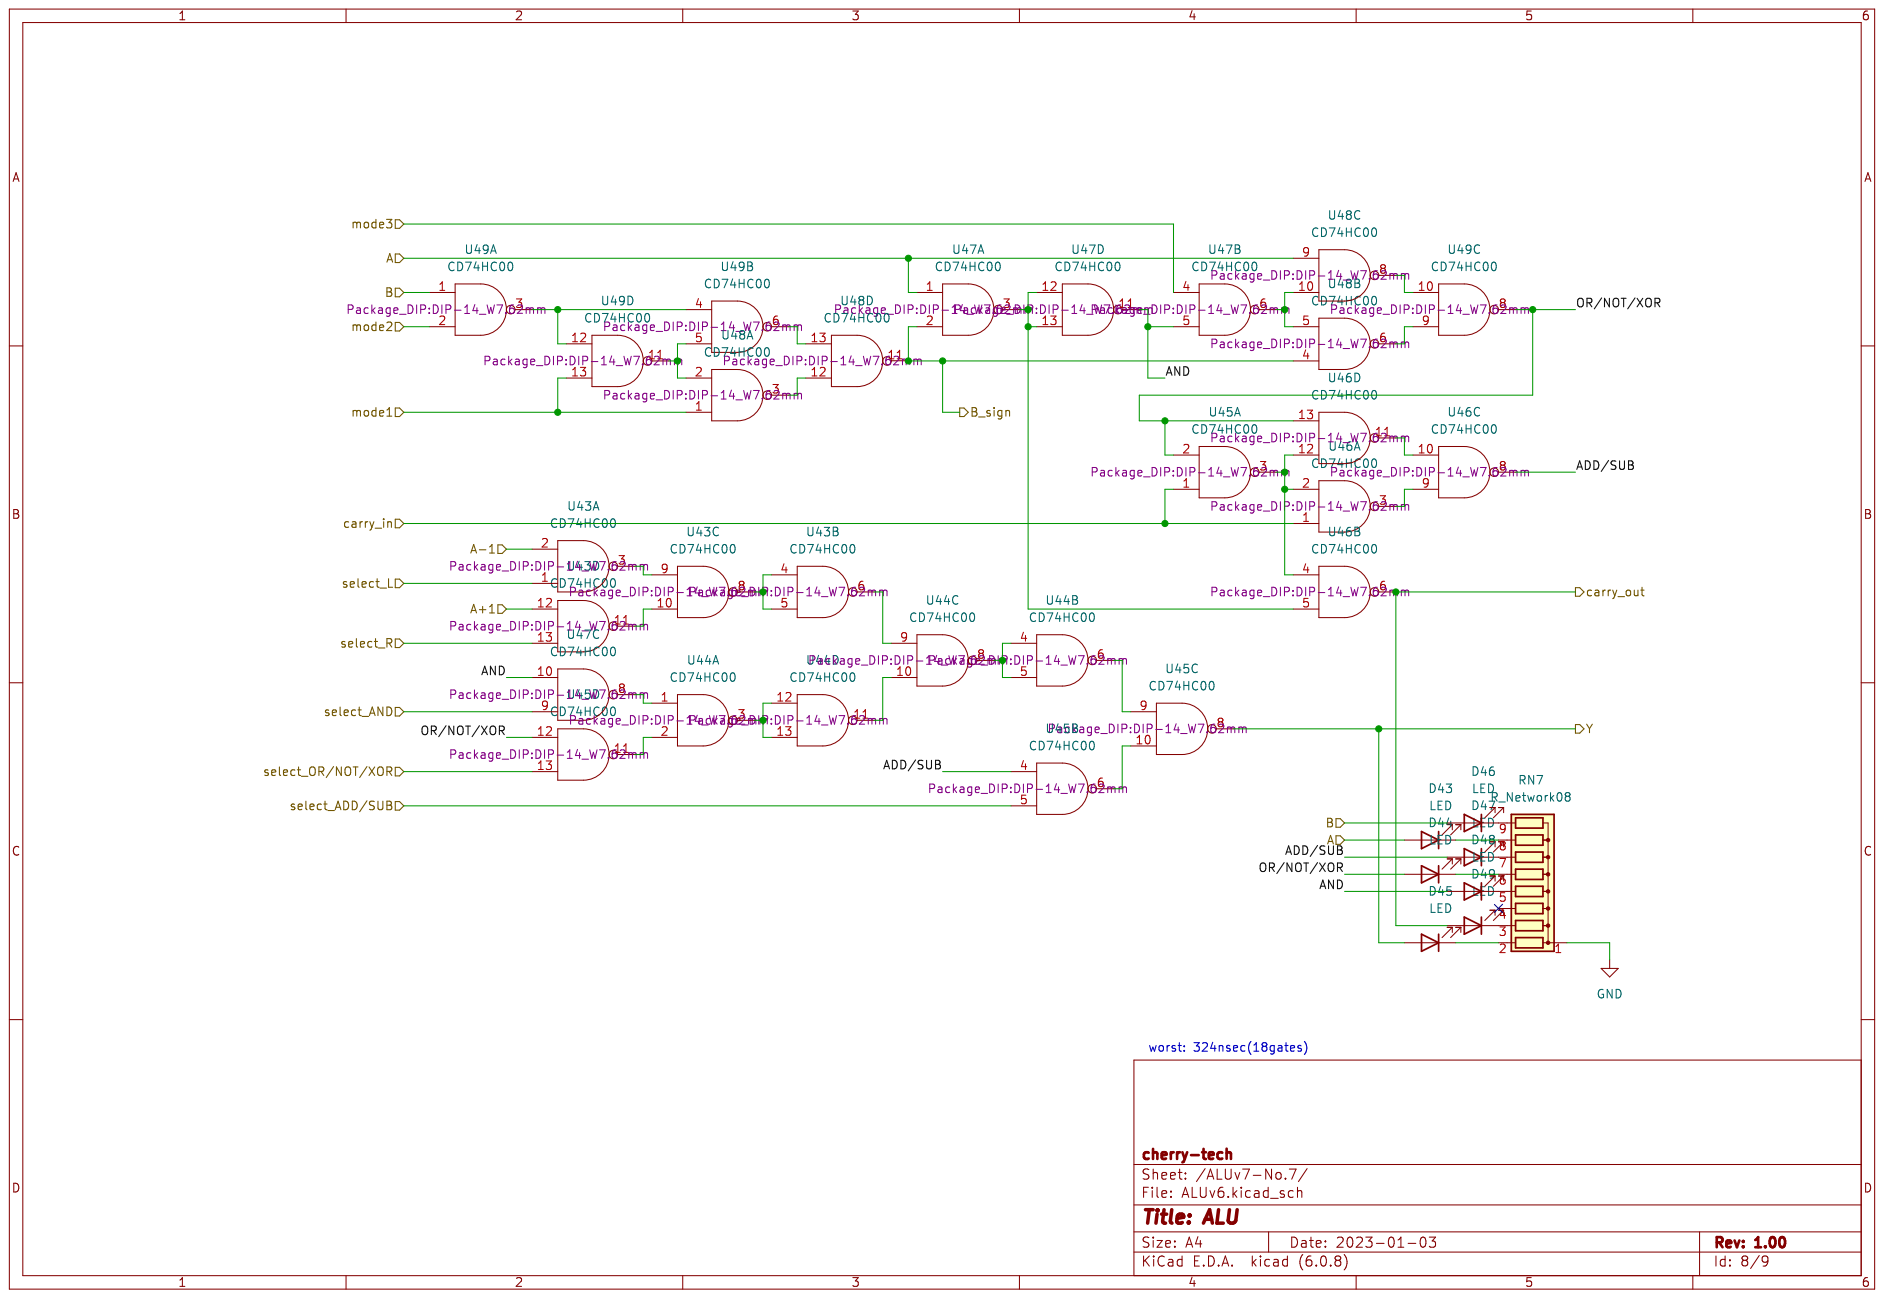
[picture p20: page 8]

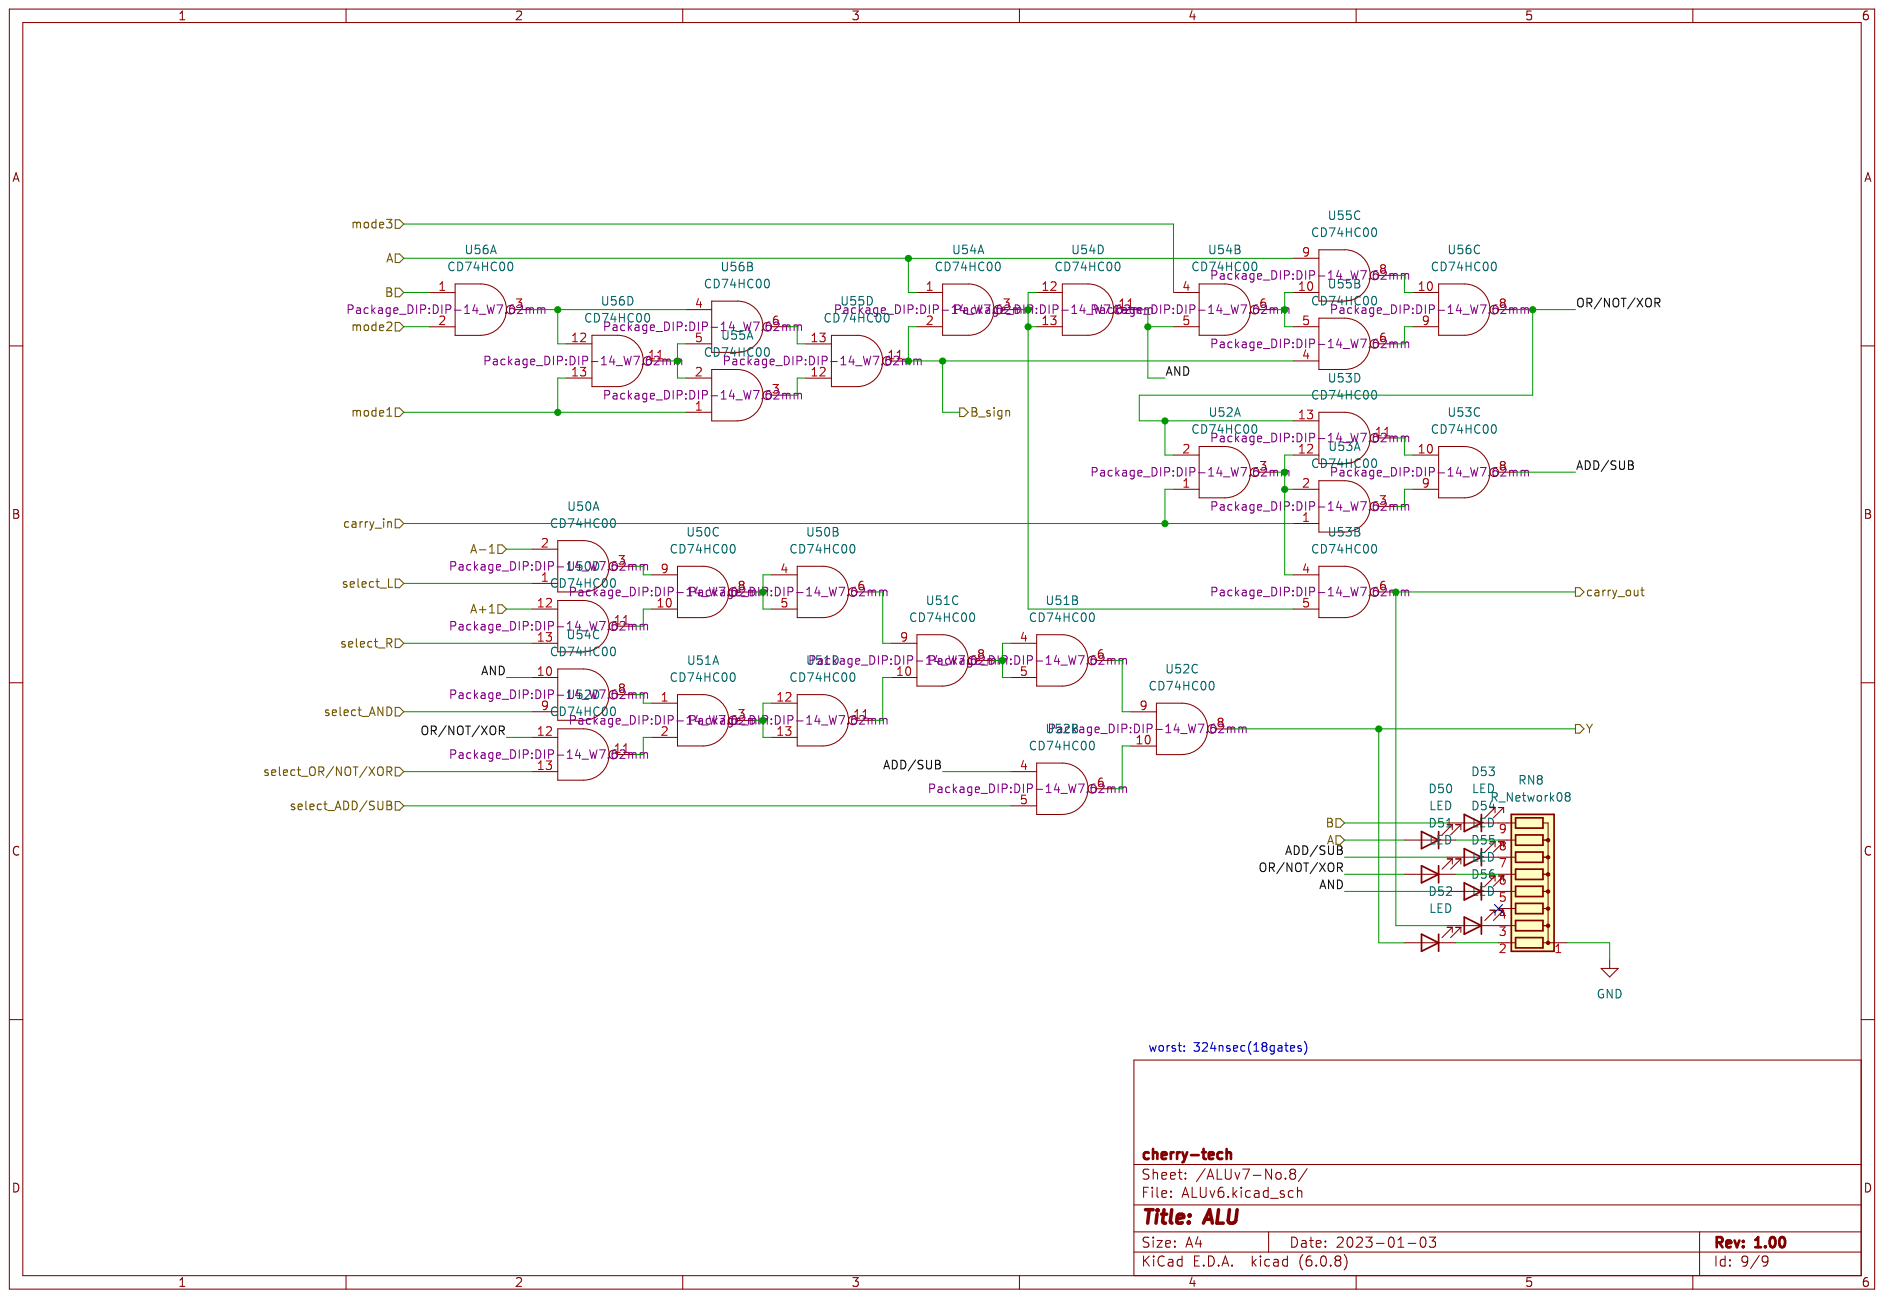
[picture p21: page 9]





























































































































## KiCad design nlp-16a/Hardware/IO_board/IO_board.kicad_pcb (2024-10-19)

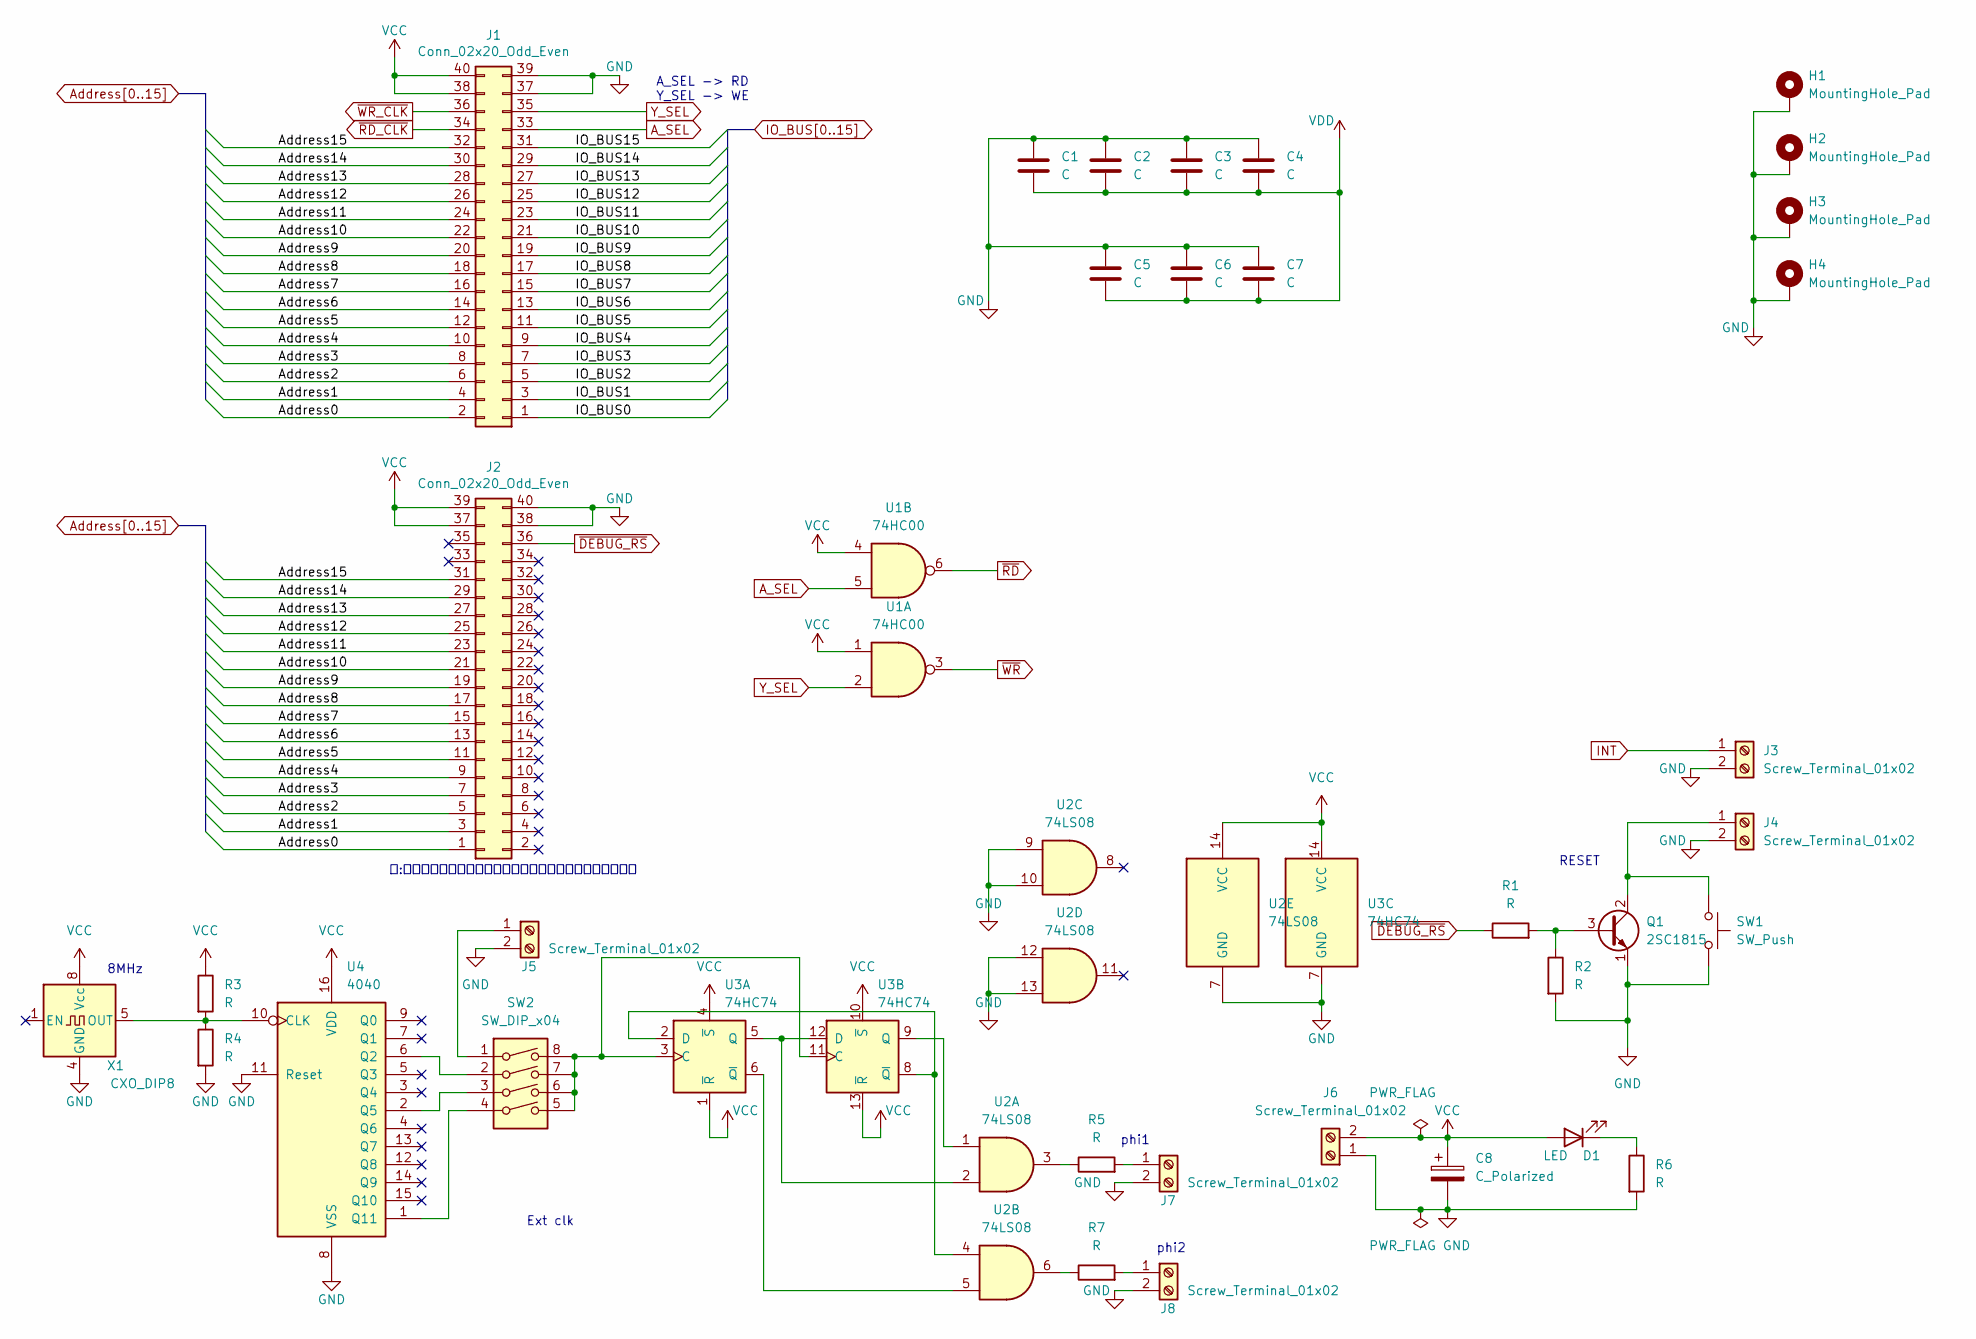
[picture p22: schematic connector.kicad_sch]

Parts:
C1, C2, C3, C4, C5, C6, C7: C; C_Disc_D7.0mm_W2.5mm_P5.00mm
C8: C_Polarized; CP_Radial_D5.0mm_P2.50mm
D1: LED; LED_D3.0mm
H1, H2, H3, H4: MountingHole_Pad; MountingHole_3.2mm_M3_Pad
J1: Conn_02x20_Odd_Even; PinHeader_2x20_P2.54mm_Horizontal
J2: Conn_02x20_Odd_Even; PinSocket_2x20_P2.54mm_Vertical
J3, J4, J5, J6, J7, J8: Screw_Terminal_01x02; TerminalBlock_bornier-2_P5.08mm
Q1: 2SC1815; TO-92_Inline
R1, R2, R3, R4, R5, R6, R7: R; R_0603_1608Metric_Pad0.98x0.95mm_HandSolder
SW1: SW_Push; SW_Tactile_SPST_Angled_PTS645Vx31-2LFS
SW2: SW_DIP_x04; SW_DIP_SPSTx04_Piano_10.8x11.72mm_W7.62mm_P2.54mm
U1: 74HC00; DIP-14_W7.62mm
U2: 74LS08; DIP-14_W7.62mm
U3: 74HC74; DIP-14_W7.62mm
U4: 4040; DIP-16_W7.62mm
X1: CXO_DIP8; Oscillator_DIP-8

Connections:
A_SEL: J1.33, U1.5
Address0: J1.2, J2.1; also elsewhere on the board
Address1: J1.4, J2.3; also elsewhere on the board
Address2: J1.6, J2.5; also elsewhere on the board
Address3: J1.8, J2.7; also elsewhere on the board
Address4: J1.10, J2.9; also elsewhere on the board
Address5: J1.12, J2.11; also elsewhere on the board
Address6: J1.14, J2.13; also elsewhere on the board
Address7: J1.16, J2.15; also elsewhere on the board
Address8: J1.18, J2.17; also elsewhere on the board
Address9: J1.20, J2.19; also elsewhere on the board
Address10: J1.22, J2.21; also elsewhere on the board
Address11: J1.24, J2.23; also elsewhere on the board
Address12: J1.26, J2.25; also elsewhere on the board
Address13: J1.28, J2.27; also elsewhere on the board
Address14: J1.30, J2.29; also elsewhere on the board
Address15: J1.32, J2.31; also elsewhere on the board
GND: C1.1, C2.1, C3.1, C4.1, C5.1, C6.1, C7.1, C8.2, H1.1, H2.1, H3.1, H4.1, J1.37, J1.39, J2.38, J2.40, J3.2, J4.2, J5.2, J6.1, J7.2, J8.2, Q1.1 (E), R2.2, R4.2, R6.2, SW1.2, U2.7 (GND), U2.9, U2.10, U2.12, U2.13, U3.7 (GND), U4.8 (VSS), U4.11 (Reset), X1.4 (GND); also elsewhere on the board
INT: J3.1; also elsewhere on the board
IO_BUS0: J1.1; also elsewhere on the board
IO_BUS1: J1.3; also elsewhere on the board
IO_BUS2: J1.5; also elsewhere on the board
IO_BUS3: J1.7; also elsewhere on the board
IO_BUS4: J1.9; also elsewhere on the board
IO_BUS5: J1.11; also elsewhere on the board
IO_BUS6: J1.13; also elsewhere on the board
IO_BUS7: J1.15; also elsewhere on the board
IO_BUS8: J1.17; also elsewhere on the board
IO_BUS9: J1.19; also elsewhere on the board
IO_BUS10: J1.21; also elsewhere on the board
IO_BUS11: J1.23; also elsewhere on the board
IO_BUS12: J1.25; also elsewhere on the board
IO_BUS13: J1.27; also elsewhere on the board
IO_BUS14: J1.29; also elsewhere on the board
IO_BUS15: J1.31; also elsewhere on the board
unnamed: D1.1 (K), R6.1
unnamed: J4.1, Q1.2 (C), SW1.1
unnamed: J5.1, SW2.1
unnamed: J7.1, R5.2
unnamed: J8.1, R7.2
unnamed: Q1.3 (B), R1.2, R2.1
unnamed: R3.2, R4.1, U4.10 (CLK), X1.5 (OUT)
unnamed: R5.1, U2.3
unnamed: R7.1, U2.6
unnamed: SW2.2, U4.6 (Q2)
unnamed: SW2.3, U4.2 (Q5)
unnamed: SW2.4, U4.1 (Q11)
unnamed: SW2.5, SW2.6, SW2.7, SW2.8, U3.3 (C), U3.11 (C)
unnamed: U2.1, U3.9 (Q)
unnamed: U2.2, U3.5 (Q), U3.12 (D)
unnamed: U2.4, U3.2 (D), U3.8 (~Q)
unnamed: U2.5, U3.6 (~Q)
Y_SEL: J1.35, U1.2
~DEBUG_RS: J2.36, R1.1
~RD_CLK: J1.34; also elsewhere on the board
~RD: U1.6; also elsewhere on the board
~WR_CLK: J1.36; also elsewhere on the board
~WR: U1.3; also elsewhere on the board

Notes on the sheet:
phi1
A_SEL -> RD Y_SEL -> WE
RESET
Ext clk
注:ピンヘッダとピンソケットでフットプリントの左右が違う
8MHz
phi2

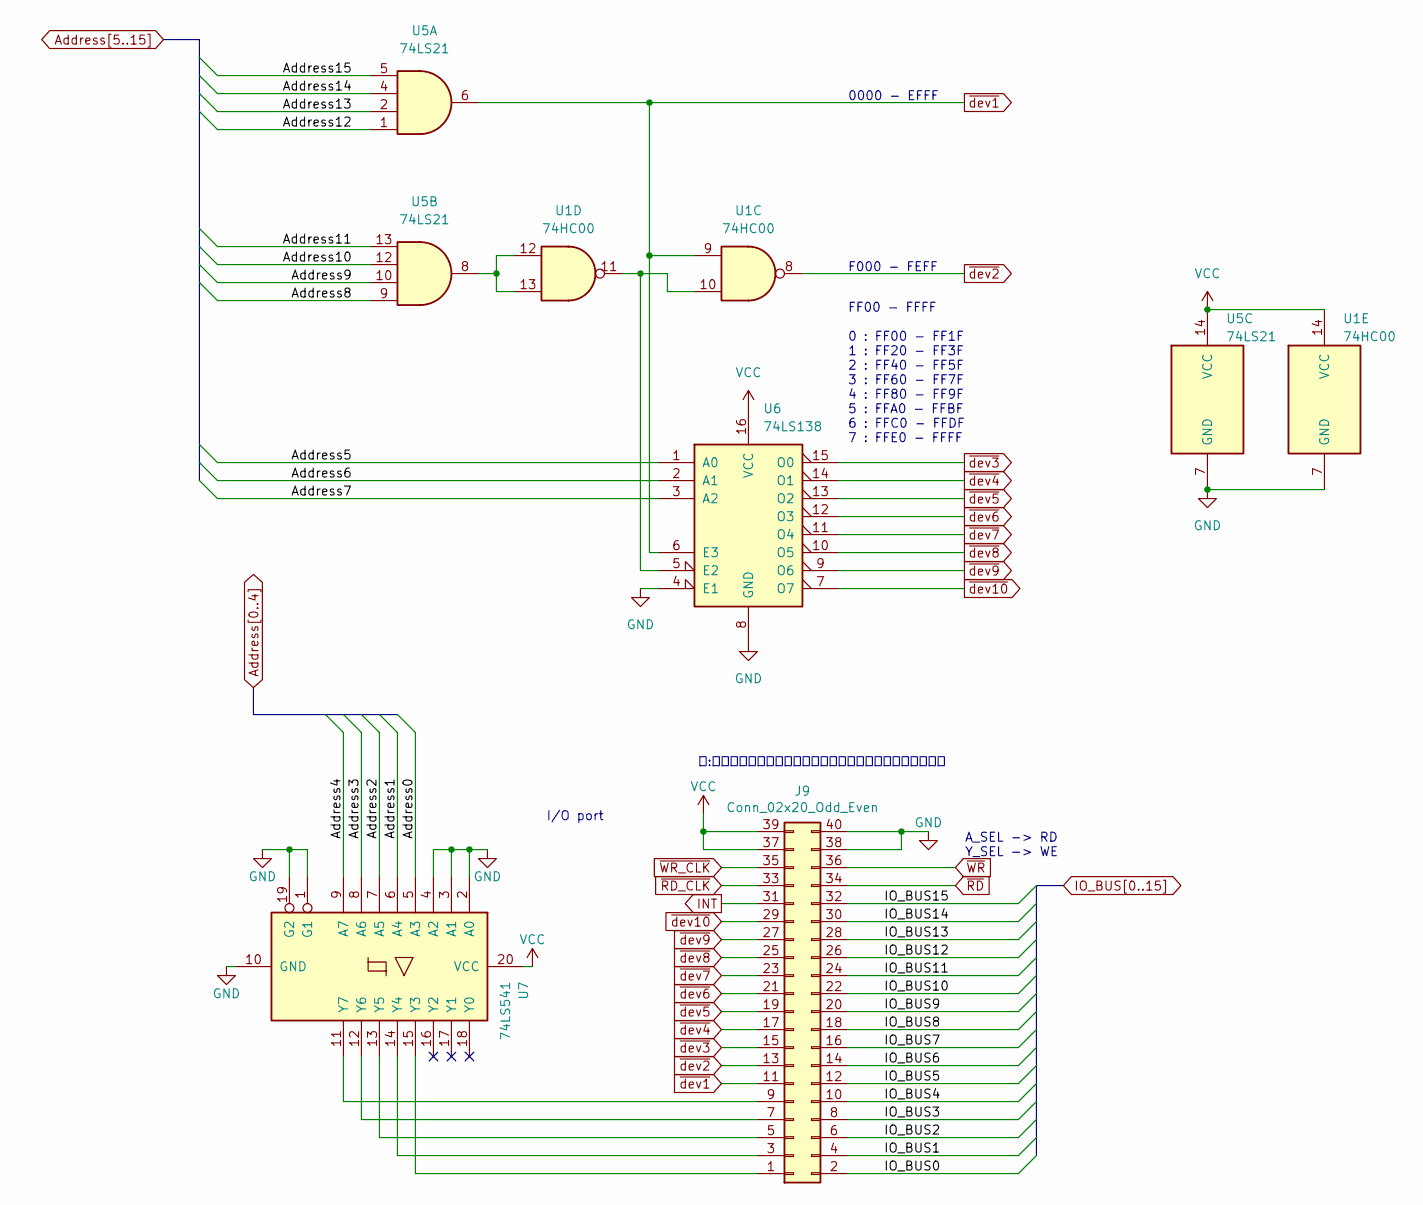
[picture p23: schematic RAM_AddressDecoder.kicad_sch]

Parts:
J9: Conn_02x20_Odd_Even; PinSocket_2x20_P2.54mm_Vertical
U1: 74HC00; DIP-14_W7.62mm
U5: 74LS21; DIP-14_W7.62mm
U6: 74LS138; DIP-16_W7.62mm
U7: 74LS541; DIP-20_W7.62mm

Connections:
Address0: U7.5 (A3); also elsewhere on the board
Address1: U7.6 (A4); also elsewhere on the board
Address2: U7.7 (A5); also elsewhere on the board
Address3: U7.8 (A6); also elsewhere on the board
Address4: U7.9 (A7); also elsewhere on the board
Address5: U6.1 (A0); also elsewhere on the board
Address6: U6.2 (A1); also elsewhere on the board
Address7: U6.3 (A2); also elsewhere on the board
Address8: U5.9; also elsewhere on the board
Address9: U5.10; also elsewhere on the board
Address10: U5.12; also elsewhere on the board
Address11: U5.13; also elsewhere on the board
Address12: U5.1; also elsewhere on the board
Address13: U5.2; also elsewhere on the board
Address14: U5.4; also elsewhere on the board
Address15: U5.5; also elsewhere on the board
GND: J9.38, J9.40, U1.7 (GND), U5.7 (GND), U6.4 (E1), U6.8 (GND), U7.1 (G1), U7.2 (A0), U7.3 (A1), U7.4 (A2), U7.10 (GND), U7.19 (G2); also elsewhere on the board
INT: J9.31; also elsewhere on the board
IO_BUS0: J9.2; also elsewhere on the board
IO_BUS1: J9.4; also elsewhere on the board
IO_BUS2: J9.6; also elsewhere on the board
IO_BUS3: J9.8; also elsewhere on the board
IO_BUS4: J9.10; also elsewhere on the board
IO_BUS5: J9.12; also elsewhere on the board
IO_BUS6: J9.14; also elsewhere on the board
IO_BUS7: J9.16; also elsewhere on the board
IO_BUS8: J9.18; also elsewhere on the board
IO_BUS9: J9.20; also elsewhere on the board
IO_BUS10: J9.22; also elsewhere on the board
IO_BUS11: J9.24; also elsewhere on the board
IO_BUS12: J9.26; also elsewhere on the board
IO_BUS13: J9.28; also elsewhere on the board
IO_BUS14: J9.30; also elsewhere on the board
IO_BUS15: J9.32; also elsewhere on the board
unnamed: J9.1, U7.15 (Y3)
unnamed: J9.3, U7.14 (Y4)
unnamed: J9.5, U7.13 (Y5)
unnamed: J9.7, U7.12 (Y6)
unnamed: J9.9, U7.11 (Y7)
unnamed: U1.10, U1.11, U6.5 (E2)
unnamed: U1.12, U1.13, U5.8
~RD_CLK: J9.33; also elsewhere on the board
~RD: J9.34; also elsewhere on the board
~WR_CLK: J9.35; also elsewhere on the board
~WR: J9.36; also elsewhere on the board
~dev1: J9.11, U1.9, U5.6, U6.6 (E3)
~dev2: J9.13, U1.8
~dev3: J9.15, U6.15 (O0)
~dev4: J9.17, U6.14 (O1)
~dev5: J9.19, U6.13 (O2)
~dev6: J9.21, U6.12 (O3)
~dev7: J9.23, U6.11 (O4)
~dev8: J9.25, U6.10 (O5)
~dev9: J9.27, U6.9 (O6)
~dev10: J9.29, U6.7 (O7)

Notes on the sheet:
F000 - FEFF
A_SEL -> RD Y_SEL -> WE
0000 - EFFF
I/O port
FF00 - FFFF 0 : FF00 - FF1F 1 : FF20 - FF3F 2 : FF40 - FF5F 3 : FF60 - FF7F 4 : FF80 - FF9F 5 : FFA0 - FFBF 6 : FFC0 - FFDF 7 : FFE0 - FFFF
注:ピンヘッダとピンソケットでフットプリントの左右が違う

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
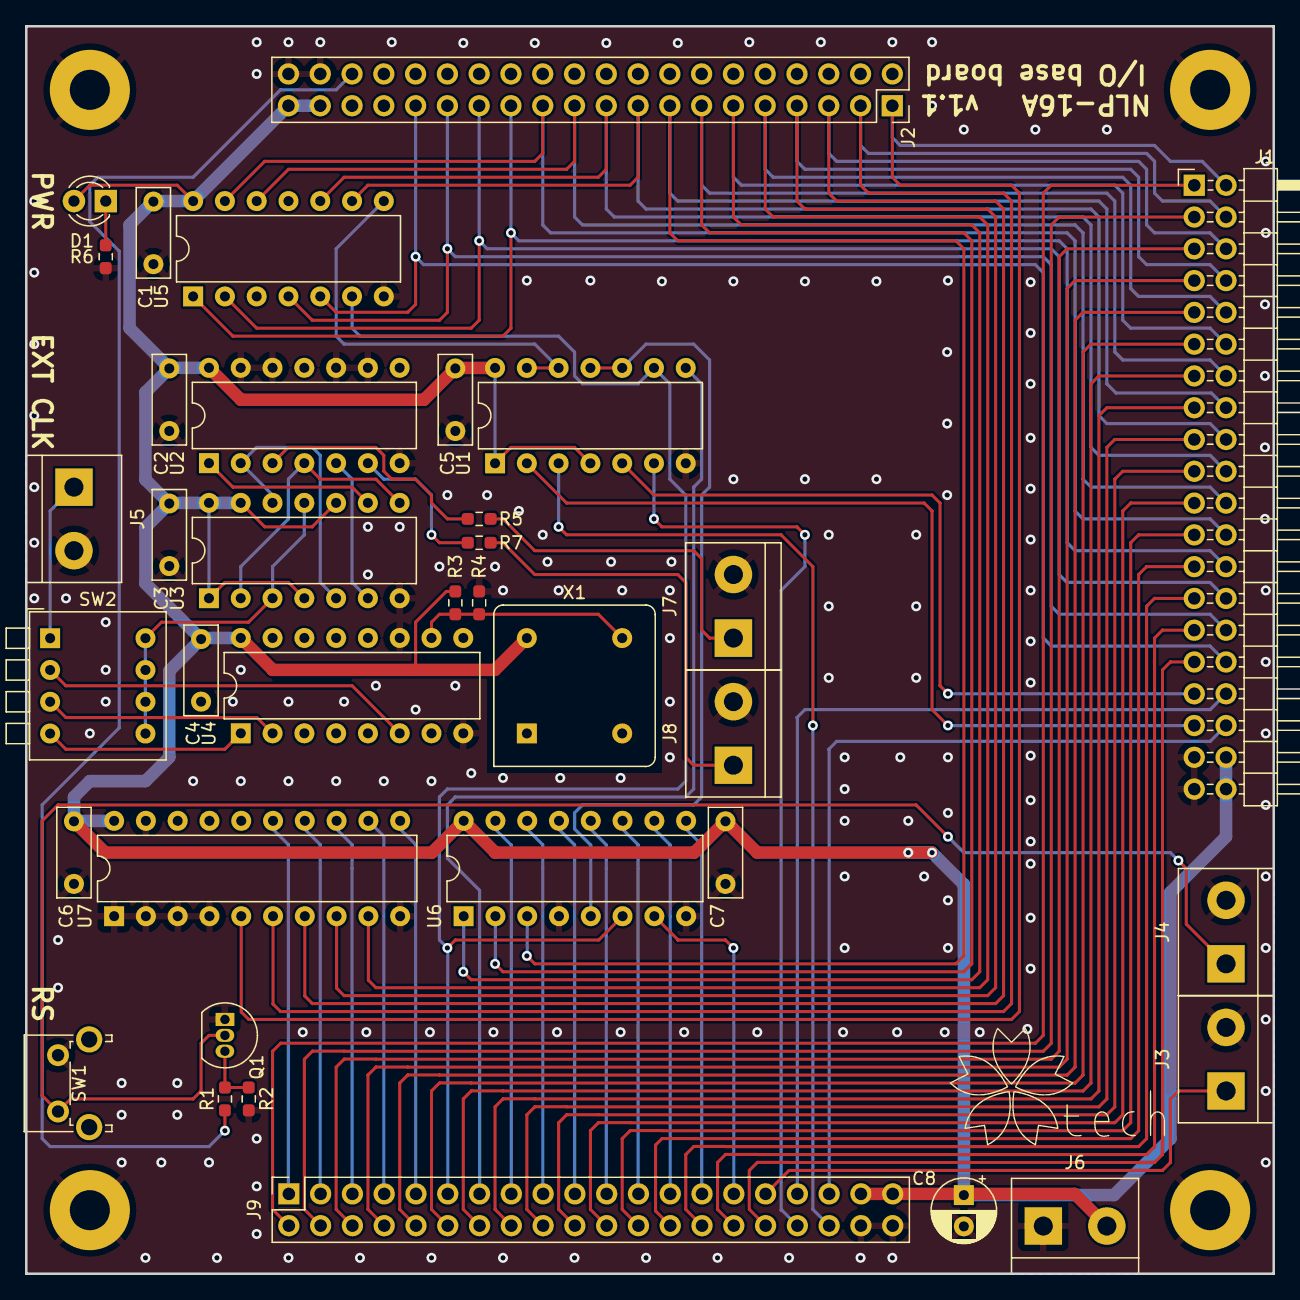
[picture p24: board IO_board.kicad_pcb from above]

Board: 2 copper layers, 99.7 x 99.7 mm, 40 parts (0 on the bottom side), 76 nets.

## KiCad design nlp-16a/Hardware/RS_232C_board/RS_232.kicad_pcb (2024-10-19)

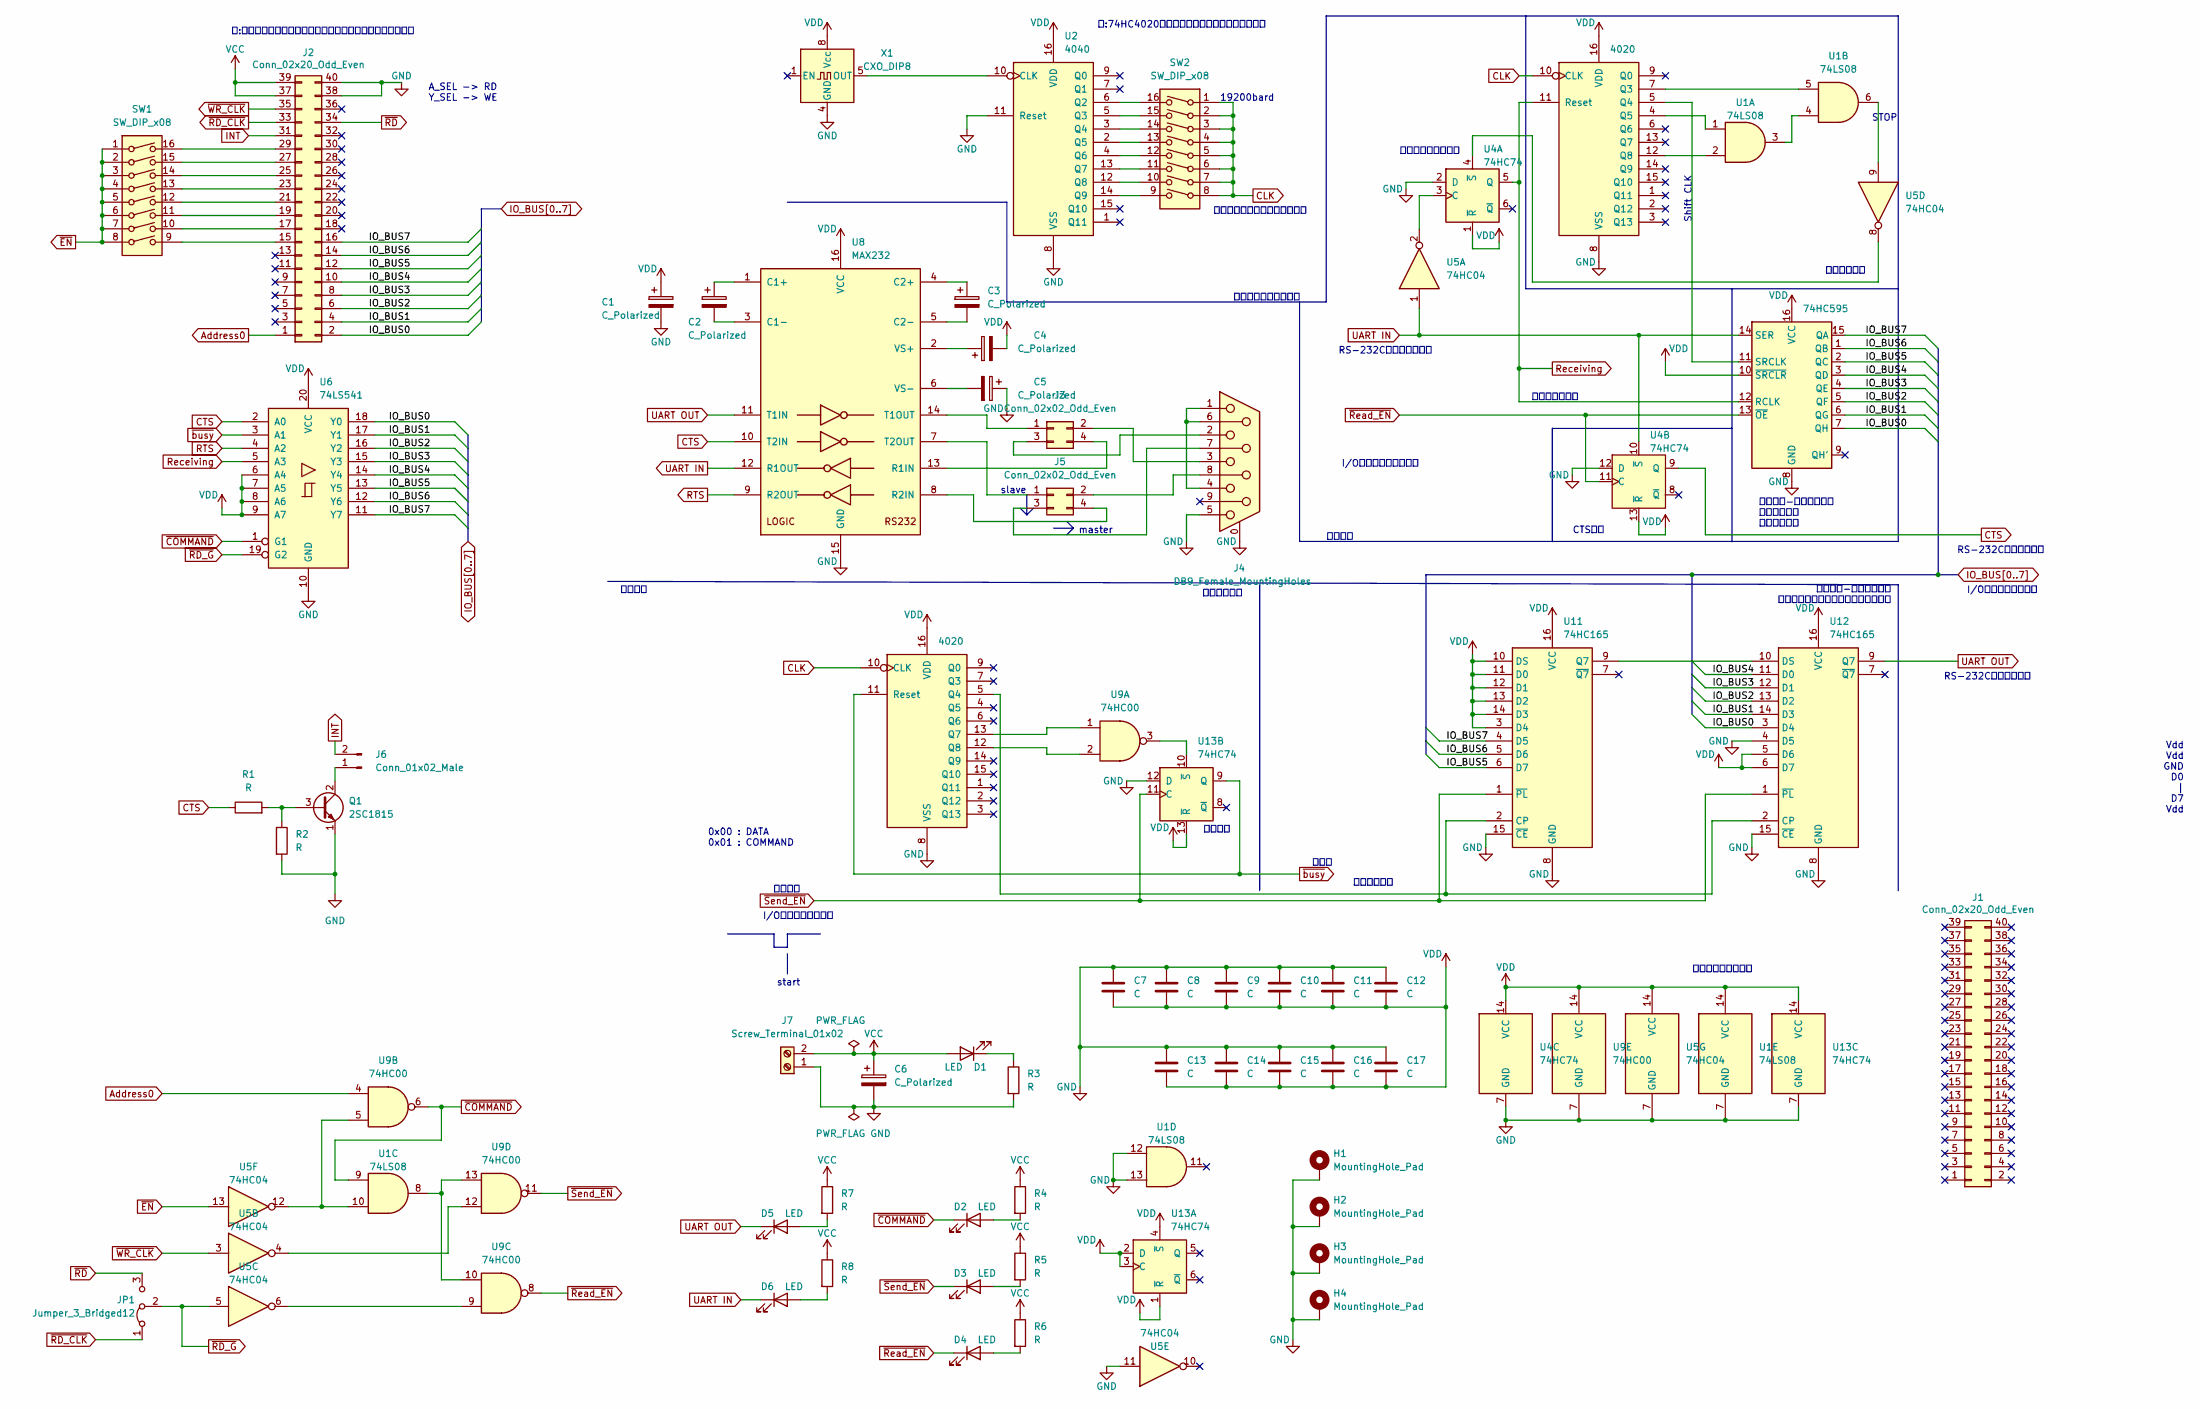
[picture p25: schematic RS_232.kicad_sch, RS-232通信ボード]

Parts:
C1, C2, C3, C4, C5, C6: C_Polarized; CP_Radial_D5.0mm_P2.50mm
C7, C8, C9, C10, C11, C12, C13, C14, C15, C16, C17: C; C_Disc_D7.0mm_W2.5mm_P5.00mm
D1, D2, D3, D4, D5, D6: LED; LED_D3.0mm
H1, H2, H3, H4: MountingHole_Pad; MountingHole_3.2mm_M3_Pad
J1, J2: Conn_02x20_Odd_Even; PinSocket_2x20_P2.54mm_Vertical
J3, J5: Conn_02x02_Odd_Even; PinHeader_2x02_P2.54mm_Vertical
J4: DB9_Female_MountingHoles; DSUB-9_Female_Horizontal_P2.77x2.84mm_EdgePinOffset4.94mm_H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
J6: Conn_01x02_Male; PinHeader_1x02_P2.54mm_Vertical
J7: Screw_Terminal_01x02; TerminalBlock_bornier-2_P5.08mm
JP1: Jumper_3_Bridged12; SolderJumper-3_P1.3mm_Bridged12_Pad1.0x1.5mm
Q1: 2SC1815; TO-92_Inline
R1, R2, R3, R4, R5, R6, R7, R8: R; R_0603_1608Metric_Pad0.98x0.95mm_HandSolder
SW1, SW2: SW_DIP_x08; SW_DIP_SPSTx08_Piano_10.8x21.88mm_W7.62mm_P2.54mm
U1: 74LS08; DIP-14_W7.62mm
U2: 4040; DIP-16_W7.62mm
U3, U10: 4020; DIP-16_W7.62mm
U4, U13: 74HC74; DIP-14_W7.62mm
U5: 74HC04; DIP-14_W7.62mm
U6: 74LS541; DIP-20_W7.62mm
U7: 74HC595; DIP-16_W7.62mm
U8: MAX232; DIP-16_W7.62mm
U9: 74HC00; DIP-14_W7.62mm
U11, U12: 74HC165; DIP-16_W7.62mm
X1: CXO_DIP8; Oscillator_DIP-8

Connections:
Address0: J2.1, U9.4
CLK: SW2.1, SW2.2, SW2.3, SW2.4, SW2.5, SW2.6, SW2.7, SW2.8, U3.10 (CLK), U10.10 (CLK)
CTS: R1.1, U4.9 (Q), U6.2 (A0), U8.10 (T2IN)
GND: C1.2, C5.1, C6.2, C7.1, C8.1, C9.1, C10.1, C11.1, C12.1, C13.1, C14.1, C15.1, C16.1, C17.1, H1.1, H2.1, H3.1, H4.1, J2.38, J2.40, J4.0 (PAD), J4.5, J7.1, Q1.1 (E), R2.2, R3.2, U1.7 (GND), U1.12, U1.13, U2.8 (VSS), U2.11 (Reset), U3.8 (VSS), U4.2 (D), U4.7 (GND), U4.12 (D), U5.7 (GND), U5.11, U6.10 (GND), U7.8 (GND), U8.15 (GND), U9.7 (GND), U10.8 (VSS), U11.8 (GND), U11.15 (~CE), U12.4 (D5), U12.8 (GND), U12.15 (~CE), U13.7 (GND), U13.12 (D), X1.4 (GND)
INT: J2.31, J6.2
IO_BUS0: J2.2, U6.18 (Y0), U7.7 (QH), U12.3 (D4)
IO_BUS1: J2.4, U6.17 (Y1), U7.6 (QG), U12.14 (D3)
IO_BUS2: J2.6, U6.16 (Y2), U7.5 (QF), U12.13 (D2)
IO_BUS3: J2.8, U6.15 (Y3), U7.4 (QE), U12.12 (D1)
IO_BUS4: J2.10, U6.14 (Y4), U7.3 (QD), U12.11 (D0)
IO_BUS5: J2.12, U6.13 (Y5), U7.2 (QC), U11.6 (D7)
IO_BUS6: J2.14, U6.12 (Y6), U7.1 (QB), U11.5 (D6)
IO_BUS7: J2.16, U6.11 (Y7), U7.15 (QA), U11.4 (D5)
unnamed: C2.1, U8.1 (C1+)
unnamed: C2.2, U8.3 (C1-)
unnamed: C3.1, U8.4 (C2+)
unnamed: C3.2, U8.5 (C2-)
unnamed: C4.1, U8.2 (VS+)
unnamed: C5.2, U8.6 (VS-)
unnamed: D1.1 (K), R3.1
unnamed: D2.2 (A), R4.2
unnamed: D3.2 (A), R5.2
unnamed: D4.2 (A), R6.2
unnamed: D5.2 (A), R7.2
unnamed: D6.2 (A), R8.2
unnamed: J2.15, SW1.9
unnamed: J2.17, SW1.10
unnamed: J2.19, SW1.11
unnamed: J2.21, SW1.12
unnamed: J2.23, SW1.13
unnamed: J2.25, SW1.14
unnamed: J2.27, SW1.15
unnamed: J2.29, SW1.16
unnamed: J3.1, U8.14 (T1OUT)
unnamed: J3.2, J4.3
unnamed: J3.3, J4.2
unnamed: J3.4, U8.13 (R1IN)
unnamed: J4.1, J4.4, J4.6
unnamed: J4.7, J5.3
unnamed: J4.8, J5.2
unnamed: J5.1, U8.7 (T2OUT)
unnamed: J5.4, U8.8 (R2IN)
unnamed: J6.1, Q1.2 (C)
unnamed: Q1.3 (B), R1.2, R2.1
unnamed: SW2.9, U2.14 (Q9)
unnamed: SW2.10, U2.12 (Q8)
unnamed: SW2.11, U2.13 (Q7)
unnamed: SW2.12, U2.4 (Q6)
unnamed: SW2.13, U2.2 (Q5)
unnamed: SW2.14, U2.3 (Q4)
unnamed: SW2.15, U2.5 (Q3)
unnamed: SW2.16, U2.6 (Q2)
unnamed: U1.1, U3.4 (Q5)
unnamed: U1.2, U3.12 (Q8)
unnamed: U1.3, U1.4
unnamed: U1.5, U3.7 (Q3)
unnamed: U1.6, U5.9
unnamed: U1.8, U9.10, U9.13
unnamed: U1.10, U5.12, U9.5
unnamed: U2.10 (CLK), X1.5 (OUT)
unnamed: U3.5 (Q4), U7.11 (SRCLK)
unnamed: U4.3 (C), U5.2
unnamed: U4.4 (~S), U5.8
unnamed: U5.4, U9.12
unnamed: U5.6, U9.9
unnamed: U10.5 (Q4), U11.2 (CP), U12.2 (CP)
unnamed: U9.2, U10.12 (Q8)
unnamed: U9.1, U10.13 (Q7)
unnamed: U11.9 (Q7), U12.10 (DS)
unnamed: U9.3, U13.10 (~S)
RTS: U6.4 (A2), U8.9 (R2OUT)
Receiving: U3.11 (Reset), U4.5 (Q), U6.5 (A3), U7.12 (RCLK)
UART IN: D6.1 (K), U4.10 (~S), U5.1, U7.14 (SER), U8.12 (R1OUT)
UART OUT: D5.1 (K), U8.11 (T1IN), U12.9 (Q7)
~COMMAND: D2.1 (K), U1.9, U6.1 (G1), U9.6
~EN: SW1.1, SW1.2, SW1.3, SW1.4, SW1.5, SW1.6, SW1.7, SW1.8, U5.13
~RD_CLK: J2.33, JP1.1 (A)
~RD_G: JP1.2 (C), U5.5, U6.19 (G2)
~RD: J2.34, JP1.3 (B)
~Read_EN: D4.1 (K), U4.11 (C), U7.13 (~OE), U9.8
~Send_EN: D3.1 (K), U9.11, U11.1 (~PL), U12.1 (~PL), U13.11 (C)
~WR_CLK: J2.35, U5.3
~busy: U6.3 (A1), U10.11 (Reset), U13.9 (Q)

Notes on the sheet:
RS-232Cレベル変換より
A_SEL -> RD Y_SEL -> WE
送信データ取り込み
シリアル-パラレル変換 受信バッファ バススイッチ
slave
ステート管理
送信回路
RS-232Cレベル変換へ
送信終了
送信開始
STOP
0x00 : DATA 0x01 : COMMAND
スタートビット検出
クロックジェネレータ
start
シリアル-パラレル変換 スタートビット，ストップビット生成
I/Oバス，制御バスへ
シリアルデータ同期用クロック
I/Oバス，制御バスより
Shift CLK
〜受信中フラグ
Vdd Vdd GND D0 | D7 Vdd
注:ピンヘッダとピンソケットでフットプリントの左右が違う
送信中
19200bard
CTS制御
送信クロック
受信回路
master
注:74HC4020でないと動作周波数の定格を超える

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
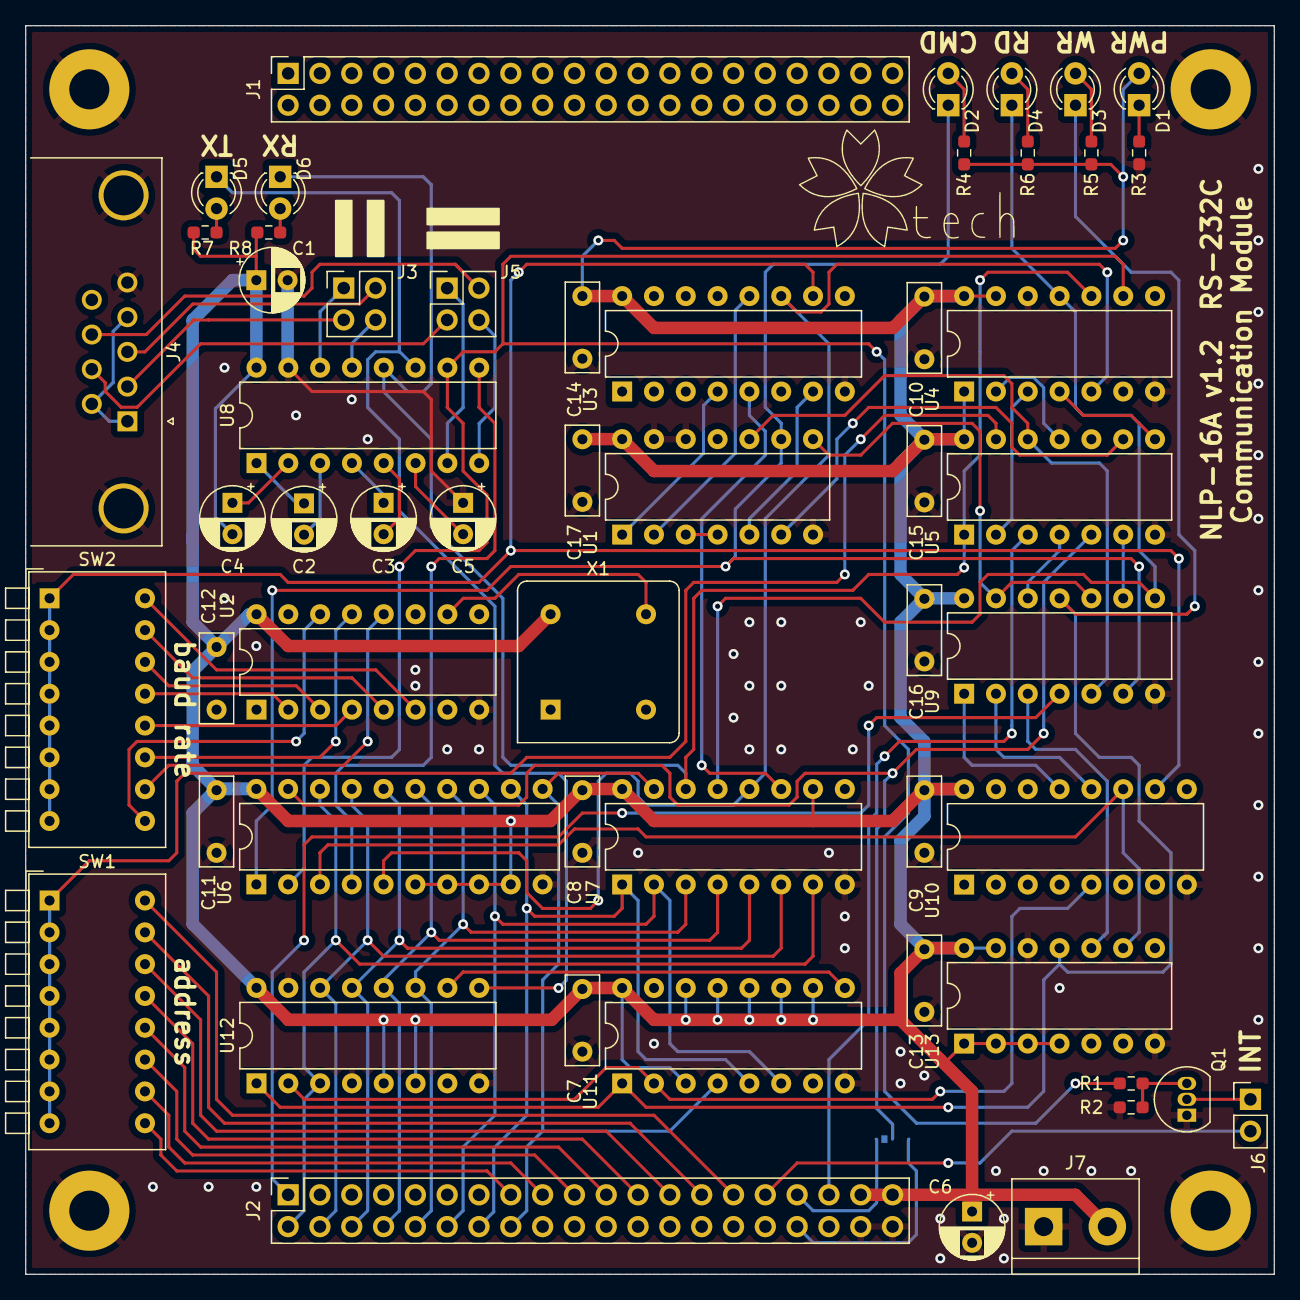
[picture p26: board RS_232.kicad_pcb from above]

Board: 2 copper layers, 99.7 x 99.7 mm, 60 parts (1 on the bottom side), 84 nets.

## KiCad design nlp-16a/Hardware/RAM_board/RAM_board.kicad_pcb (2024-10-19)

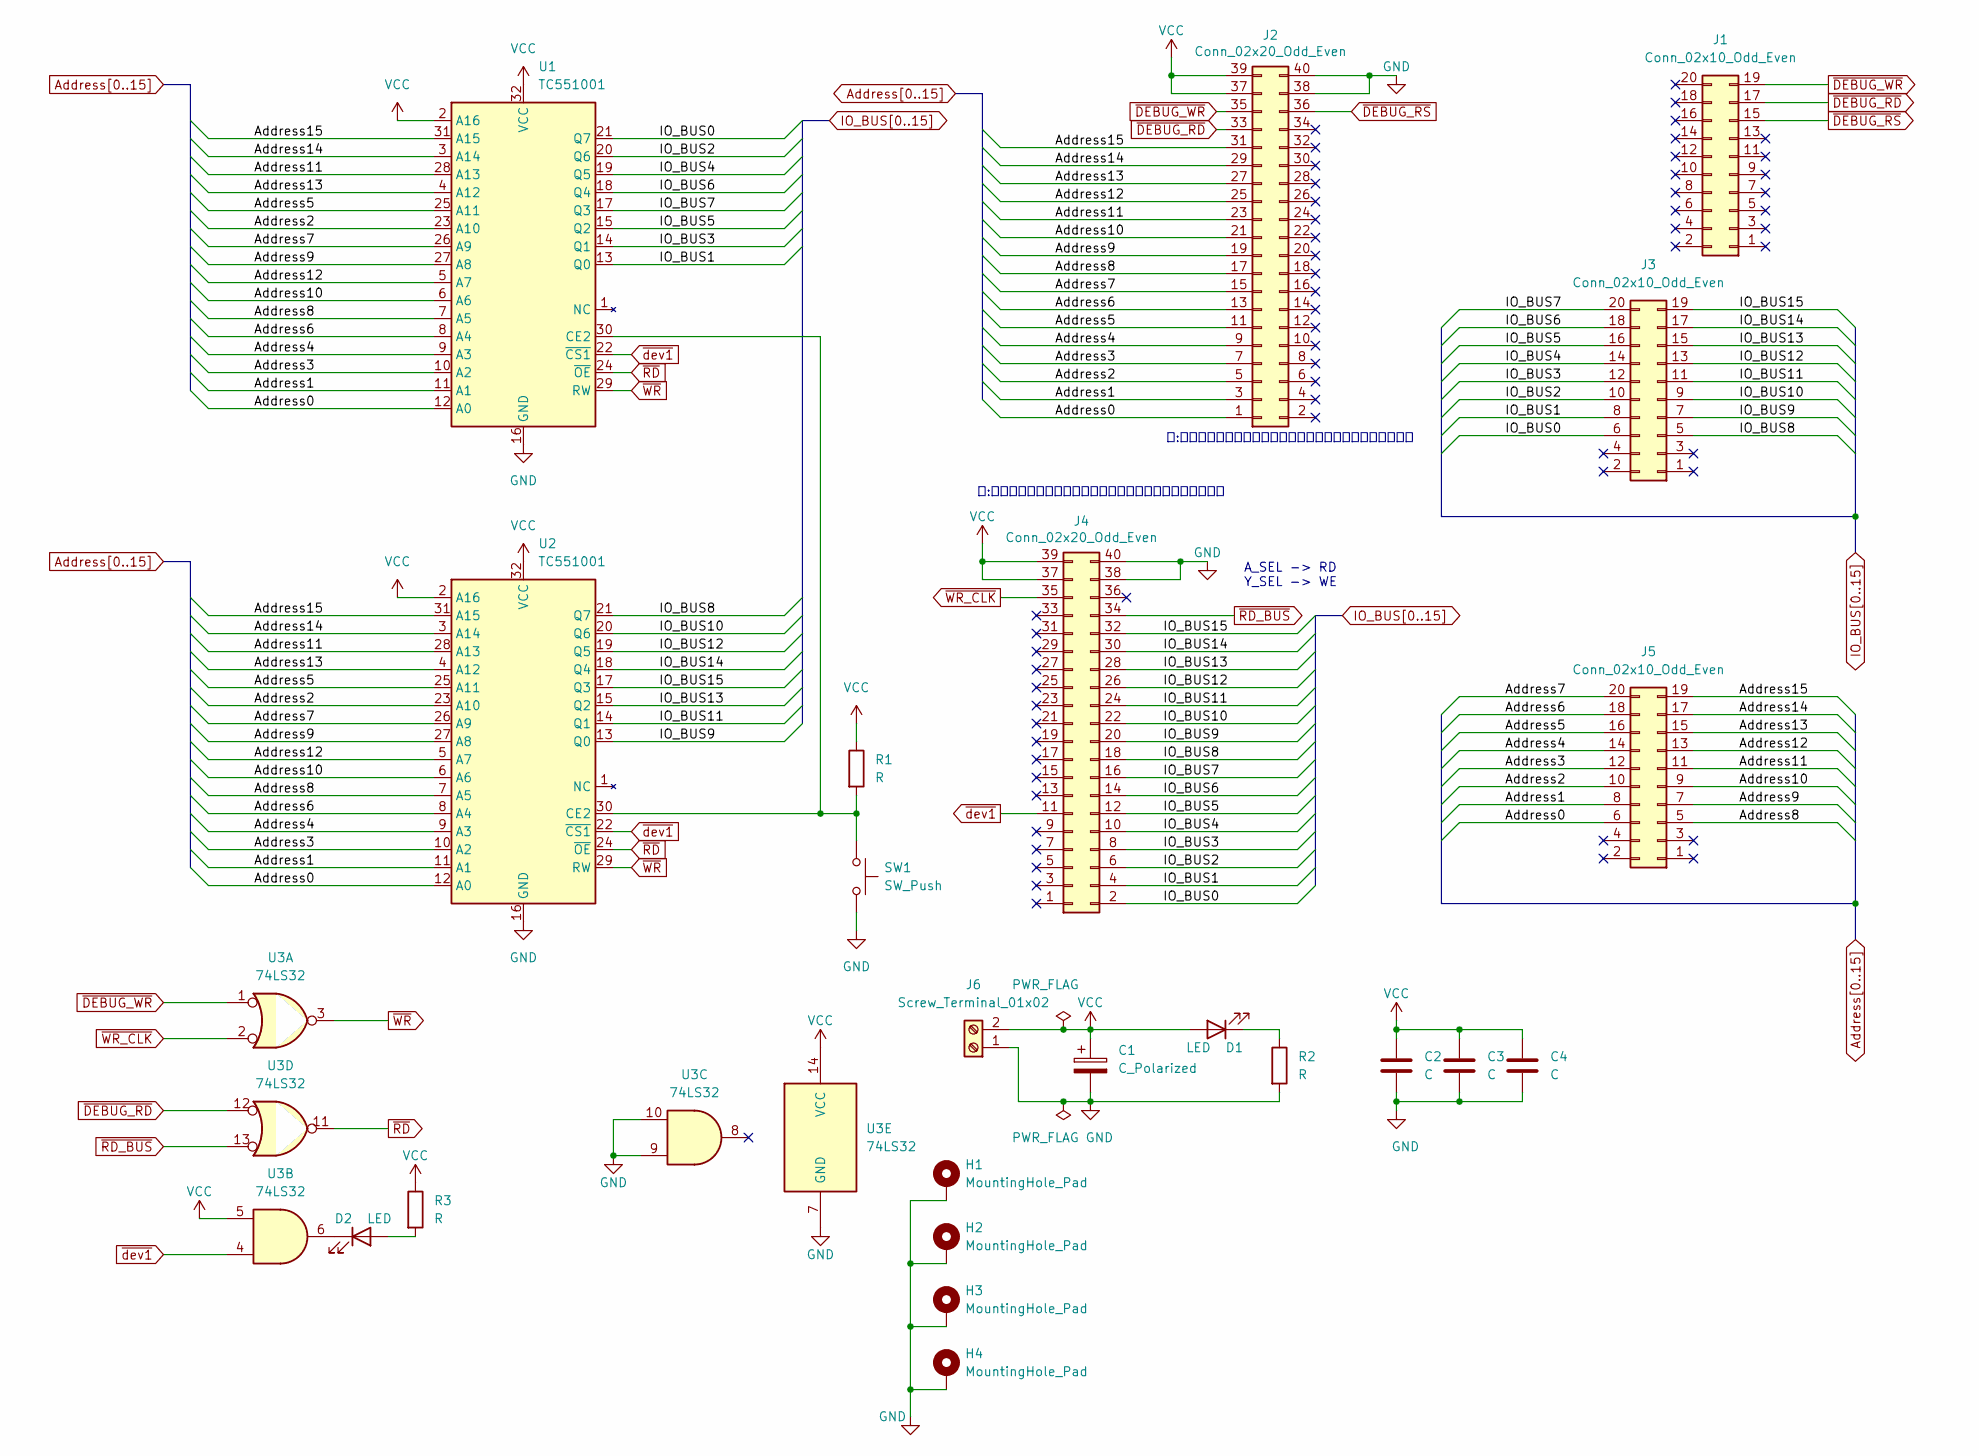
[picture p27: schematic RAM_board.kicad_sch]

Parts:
C1: C_Polarized; CP_Radial_D5.0mm_P2.50mm
C2, C3, C4: C; C_Disc_D7.0mm_W2.5mm_P5.00mm
D1, D2: LED; LED_D3.0mm
H1, H2, H3, H4: MountingHole_Pad; MountingHole_3.2mm_M3_Pad
J1, J3, J5: Conn_02x10_Odd_Even; PinHeader_2x10_P2.54mm_Vertical
J2, J4: Conn_02x20_Odd_Even; PinSocket_2x20_P2.54mm_Vertical
J6: Screw_Terminal_01x02; TerminalBlock_bornier-2_P5.08mm
R1, R2, R3: R; R_0603_1608Metric_Pad0.98x0.95mm_HandSolder
SW1: SW_Push; SW_Tactile_SPST_Angled_PTS645Vx31-2LFS
U1, U2: TC551001; DIP-32_W15.24mm
U3: 74LS32; DIP-14_W7.62mm

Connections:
Address0: J2.1, J5.6, U1.12 (A0), U2.12 (A0)
Address1: J2.3, J5.8, U1.11 (A1), U2.11 (A1)
Address2: J2.5, J5.10, U1.23 (A10), U2.23 (A10)
Address3: J2.7, J5.12, U1.10 (A2), U2.10 (A2)
Address4: J2.9, J5.14, U1.9 (A3), U2.9 (A3)
Address5: J2.11, J5.16, U1.25 (A11), U2.25 (A11)
Address6: J2.13, J5.18, U1.8 (A4), U2.8 (A4)
Address7: J2.15, J5.20, U1.26 (A9), U2.26 (A9)
Address8: J2.17, J5.5, U1.7 (A5), U2.7 (A5)
Address9: J2.19, J5.7, U1.27 (A8), U2.27 (A8)
Address10: J2.21, J5.9, U1.6 (A6), U2.6 (A6)
Address11: J2.23, J5.11, U1.28 (A13), U2.28 (A13)
Address12: J2.25, J5.13, U1.5 (A7), U2.5 (A7)
Address13: J2.27, J5.15, U1.4 (A12), U2.4 (A12)
Address14: J2.29, J5.17, U1.3 (A14), U2.3 (A14)
Address15: J2.31, J5.19, U1.31 (A15), U2.31 (A15)
GND: C1.2, C2.2, C3.2, C4.2, H1.1, H2.1, H3.1, H4.1, J2.38, J2.40, J4.38, J4.40, J6.1, R2.2, SW1.2, U1.16 (GND), U2.16 (GND), U3.7 (GND), U3.9, U3.10
IO_BUS0: J3.6, J4.2, U1.21 (Q7)
IO_BUS1: J3.8, J4.4, U1.13 (Q0)
IO_BUS2: J3.10, J4.6, U1.20 (Q6)
IO_BUS3: J3.12, J4.8, U1.14 (Q1)
IO_BUS4: J3.14, J4.10, U1.19 (Q5)
IO_BUS5: J3.16, J4.12, U1.15 (Q2)
IO_BUS6: J3.18, J4.14, U1.18 (Q4)
IO_BUS7: J3.20, J4.16, U1.17 (Q3)
IO_BUS8: J3.5, J4.18, U2.21 (Q7)
IO_BUS9: J3.7, J4.20, U2.13 (Q0)
IO_BUS10: J3.9, J4.22, U2.20 (Q6)
IO_BUS11: J3.11, J4.24, U2.14 (Q1)
IO_BUS12: J3.13, J4.26, U2.19 (Q5)
IO_BUS13: J3.15, J4.28, U2.15 (Q2)
IO_BUS14: J3.17, J4.30, U2.18 (Q4)
IO_BUS15: J3.19, J4.32, U2.17 (Q3)
unnamed: D1.1 (K), R2.1
unnamed: D2.1 (K), U3.6
unnamed: D2.2 (A), R3.2
unnamed: R1.2, SW1.1, U1.30 (CE2), U2.30 (CE2)
VCC: C1.1, C2.1, C3.1, C4.1, D1.2 (A), J2.37, J2.39, J4.37, J4.39, J6.2, R1.1, R3.1, U1.2 (A16), U1.32 (VCC), U2.2 (A16), U2.32 (VCC), U3.5, U3.14 (VCC)
~DEBUG_RD: J1.17, J2.33, U3.12
~DEBUG_RS: J1.15, J2.36
~DEBUG_WR: J1.19, J2.35, U3.1
~RD_BUS: J4.34, U3.13
~RD: U1.24 (~OE), U2.24 (~OE), U3.11
~WR_CLK: J4.35, U3.2
~WR: U1.29 (RW), U2.29 (RW), U3.3
~dev1: J4.11, U1.22 (~CS1), U2.22 (~CS1), U3.4

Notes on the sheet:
注:ピンヘッダとピンソケットでフットプリントの左右が違う
A_SEL -> RD Y_SEL -> WE

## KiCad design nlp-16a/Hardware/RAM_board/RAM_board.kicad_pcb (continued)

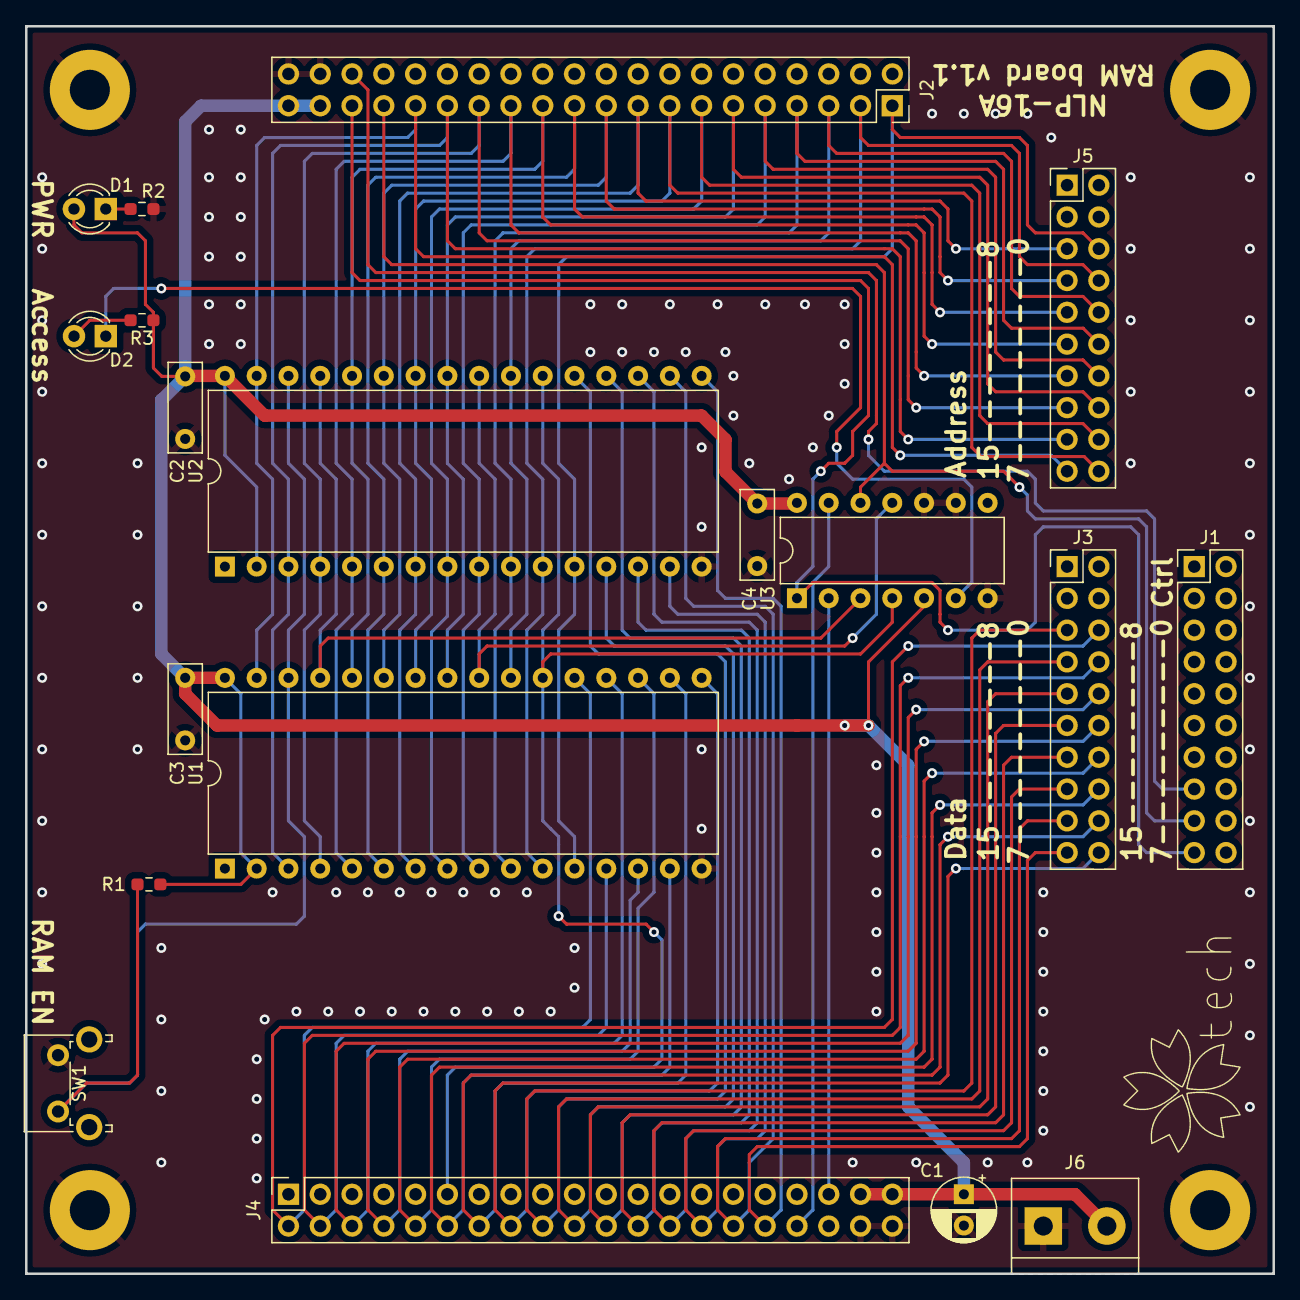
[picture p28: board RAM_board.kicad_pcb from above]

Board: 2 copper layers, 99.7 x 99.7 mm, 23 parts (0 on the bottom side), 46 nets.

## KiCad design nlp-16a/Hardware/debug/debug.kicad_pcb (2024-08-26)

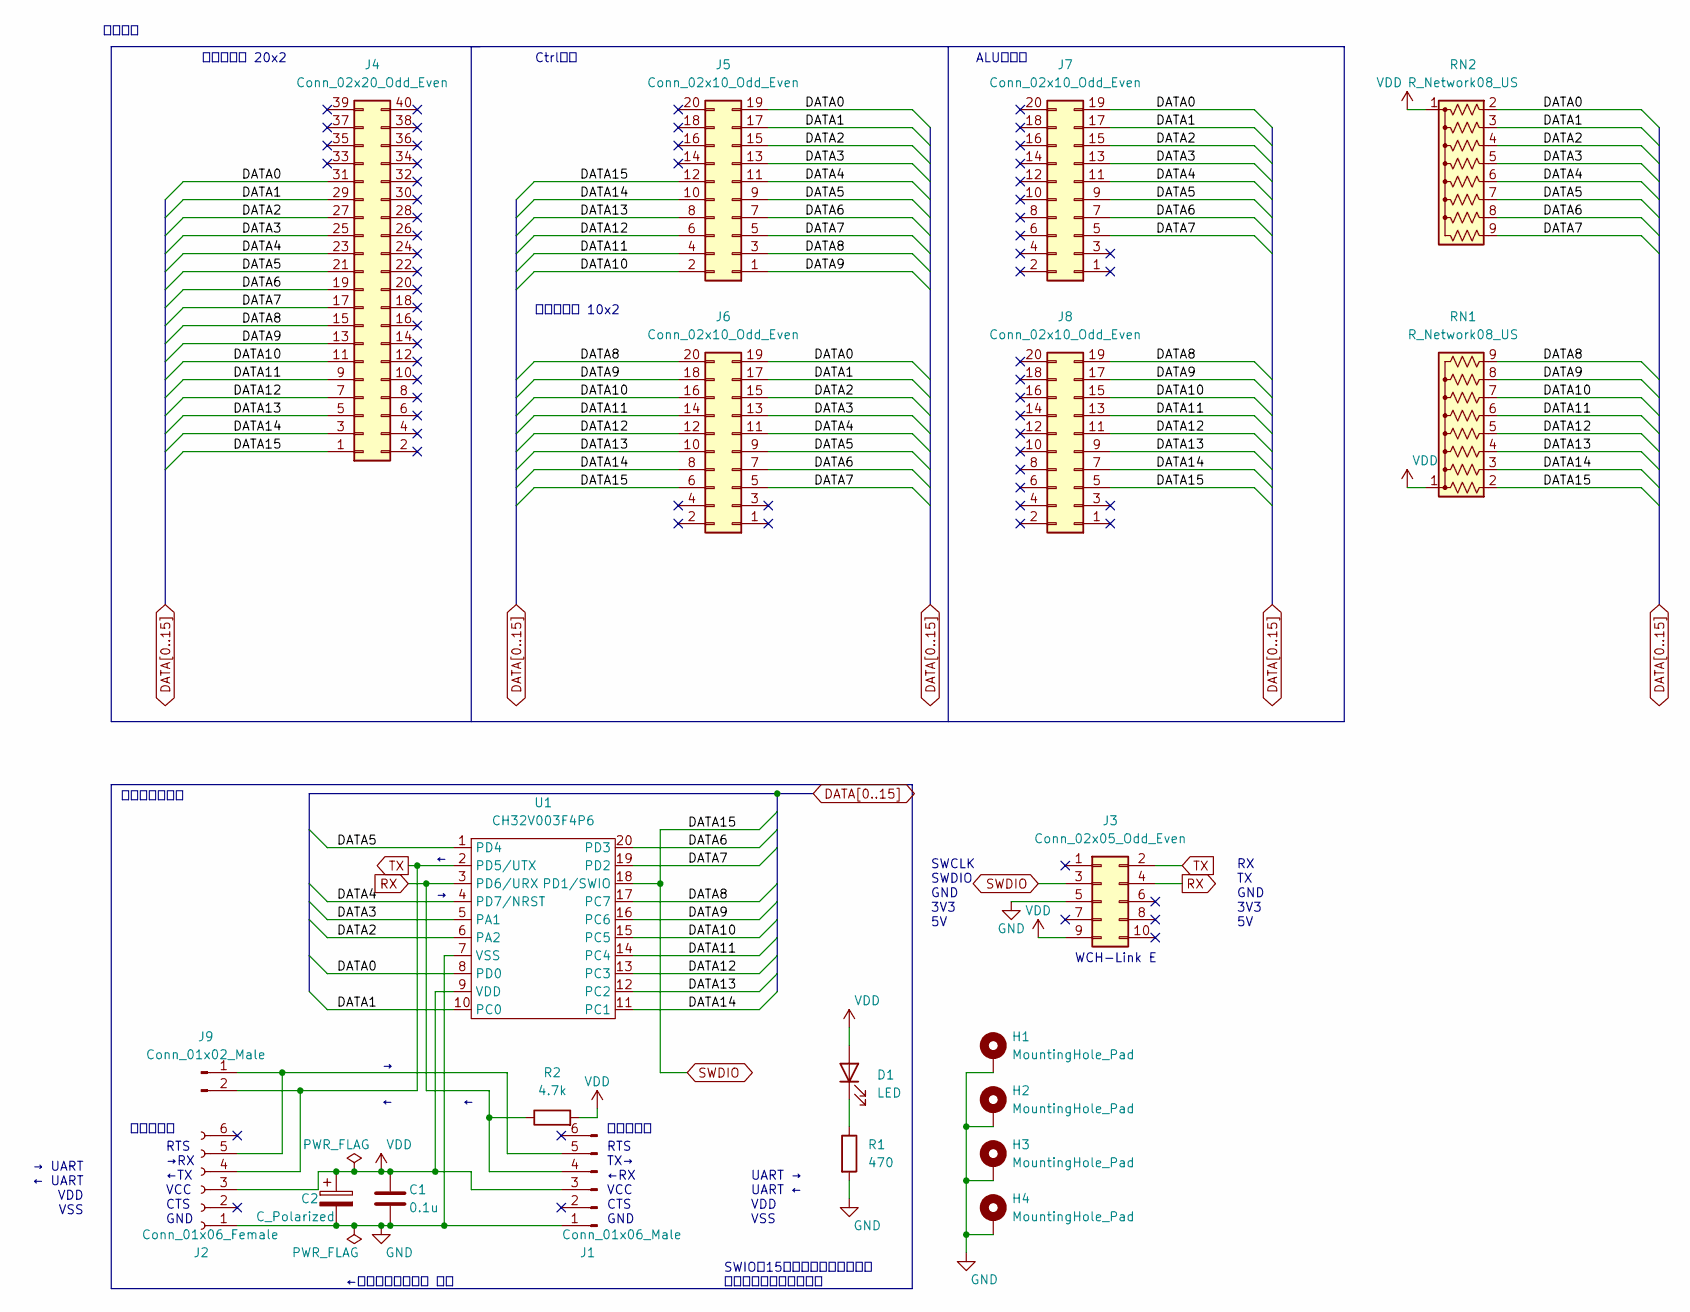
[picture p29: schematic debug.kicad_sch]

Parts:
C1: 0.1u; C_0603_1608Metric_Pad1.08x0.95mm_HandSolder
C2: C_Polarized; CP_Radial_D5.0mm_P2.50mm
D1: LED; LED_D3.0mm
H1, H2, H3, H4: MountingHole_Pad; MountingHole_3.2mm_M3_Pad
J1: Conn_01x06_Male; PinHeader_1x06_P2.54mm_Horizontal
J2: Conn_01x06_Female; PinSocket_1x06_P2.54mm_Horizontal
J3: Conn_02x05_Odd_Even; PinHeader_2x05_P2.54mm_Vertical
J4: Conn_02x20_Odd_Even; PinHeader_2x20_P2.54mm_Vertical
J5, J6, J7, J8: Conn_02x10_Odd_Even; PinHeader_2x10_P2.54mm_Vertical
J9: Conn_01x02_Male; PinHeader_1x02_P2.54mm_Vertical
R1: 470; R_0603_1608Metric_Pad0.98x0.95mm_HandSolder
R2: 4.7k; R_0603_1608Metric_Pad0.98x0.95mm_HandSolder
RN1, RN2: R_Network08_US; R_Array_SIP9
U1: CH32V003F4P6; SSOP-20_4.4x6.5mm_P0.65mm

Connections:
DATA0: J4.31, J5.19, J6.19, J7.19, RN2.2 (R1), U1.8 (PD0)
DATA1: J4.29, J5.17, J6.17, J7.17, RN2.3 (R2), U1.10 (PC0)
DATA2: J4.27, J5.15, J6.15, J7.15, RN2.4 (R3), U1.6 (PA2)
DATA3: J4.25, J5.13, J6.13, J7.13, RN2.5 (R4), U1.5 (PA1)
DATA4: J4.23, J5.11, J6.11, J7.11, RN2.6 (R5), U1.4 (PD7/NRST)
DATA5: J4.21, J5.9, J6.9, J7.9, RN2.7 (R6), U1.1 (PD4)
DATA6: J4.19, J5.7, J6.7, J7.7, RN2.8 (R7), U1.20 (PD3)
DATA7: J4.17, J5.5, J6.5, J7.5, RN2.9 (R8), U1.19 (PD2)
DATA8: J4.15, J5.3, J6.20, J8.19, RN1.9 (R8), U1.17 (PC7)
DATA9: J4.13, J5.1, J6.18, J8.17, RN1.8 (R7), U1.16 (PC6)
DATA10: J4.11, J5.2, J6.16, J8.15, RN1.7 (R6), U1.15 (PC5)
DATA11: J4.9, J5.4, J6.14, J8.13, RN1.6 (R5), U1.14 (PC4)
DATA12: J4.7, J5.6, J6.12, J8.11, RN1.5 (R4), U1.13 (PC3)
DATA13: J4.5, J5.8, J6.10, J8.9, RN1.4 (R3), U1.12 (PC2)
DATA14: J4.3, J5.10, J6.8, J8.7, RN1.3 (R2), U1.11 (PC1)
GND: C1.2, C2.2, H1.1, H2.1, H3.1, H4.1, J1.1, J2.1, J3.5, R1.2, U1.7 (VSS)
unnamed: D1.1 (K), R1.1
unnamed: J1.5, J2.5, J9.1
RX: J1.4, J3.4, R2.1, U1.3 (PD6/URX)
SWDIO: J3.3, J4.1, J5.12, J6.6, J8.5, RN1.2 (R1), U1.18 (PD1/SWIO)
TX: J2.4, J3.2, J9.2, U1.2 (PD5/UTX)
VDD: C1.1, C2.1, D1.2 (A), J1.3, J2.3, J3.9, R2.2, RN1.1 (common), RN2.1 (common), U1.9 (VDD)

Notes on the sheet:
RTS →RX ←TX VCC CTS GND
←デイジーチェーン 方向
ALUデータ
マスター側
SWCLK SWDIO GND 3V3 5V
WCH-Link E
接続関係
SWIOは15番目に持っていきたい その他はいい感じに配線
RX TX GND 3V3 5V
スレーブ側
汎用データ 20x2
UART → UART ← VDD VSS
RTS TX→ ←RX VCC CTS GND
Ctrlバス
汎用データ 10x2
デバッガ制御部
→ UART ← UART VDD VSS

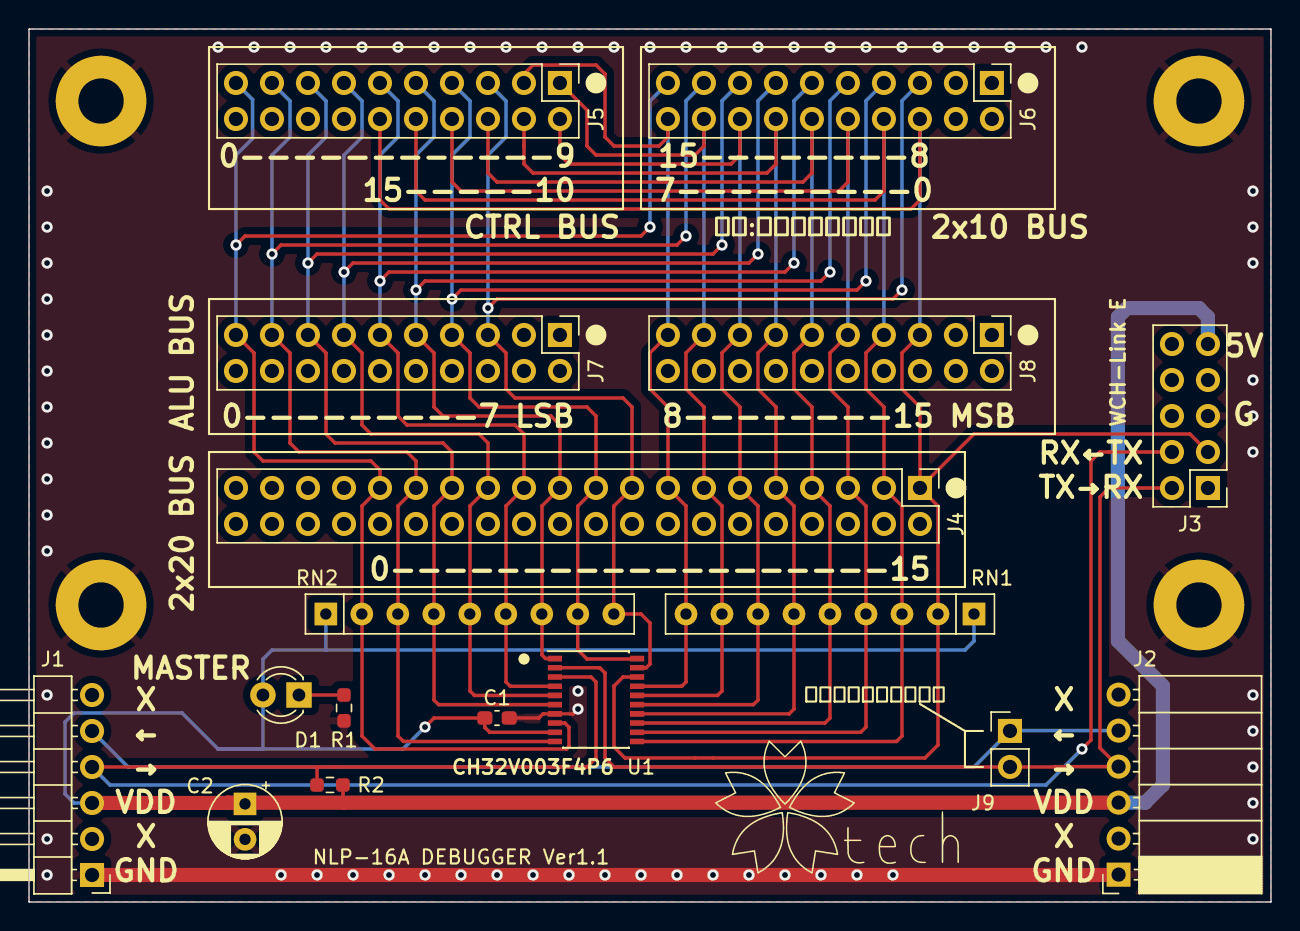
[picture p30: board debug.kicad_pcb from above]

Board: 2 copper layers, 87.6 x 61.6 mm, 21 parts (0 on the bottom side), 22 nets.

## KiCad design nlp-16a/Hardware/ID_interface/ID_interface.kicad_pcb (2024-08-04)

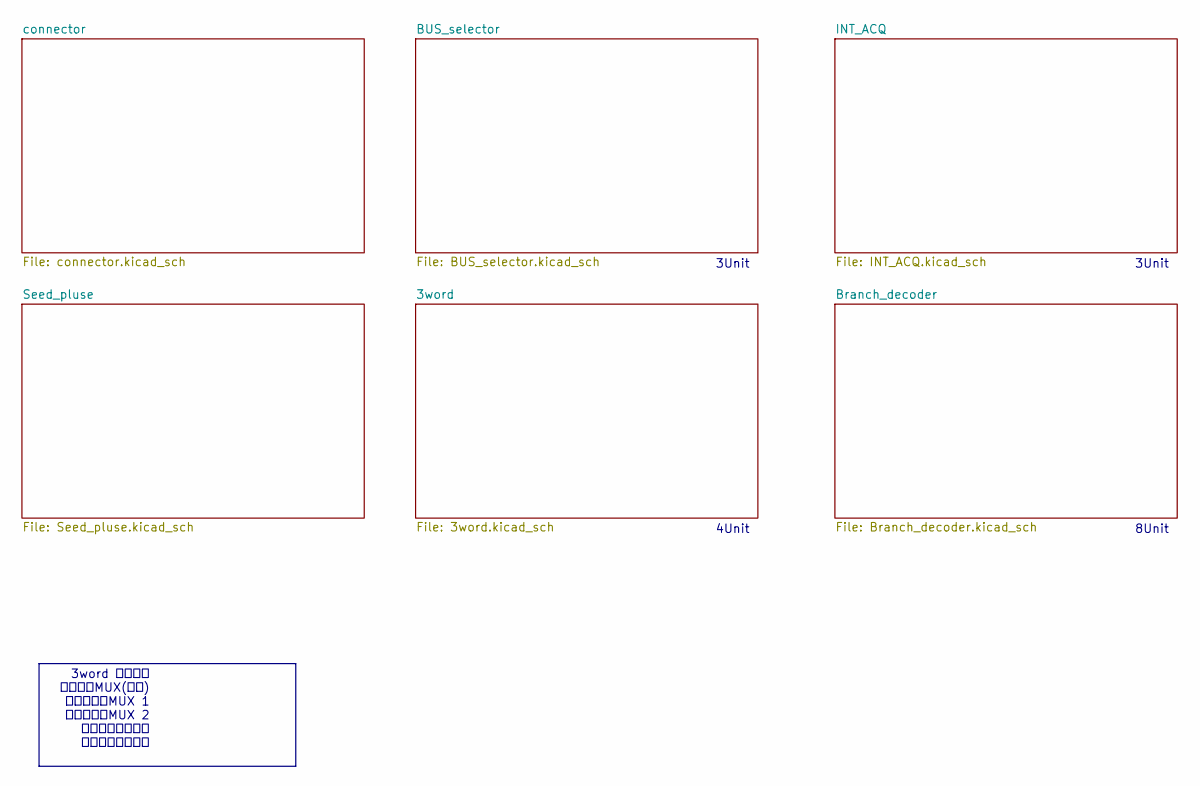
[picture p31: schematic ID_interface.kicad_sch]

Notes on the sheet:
3word 命令検出 レジスタMUX(統合) ・レジスタMUX 1 ・レジスタMUX 2 ブランチデコーダ パルスシード生成
3Unit
4Unit
8Unit

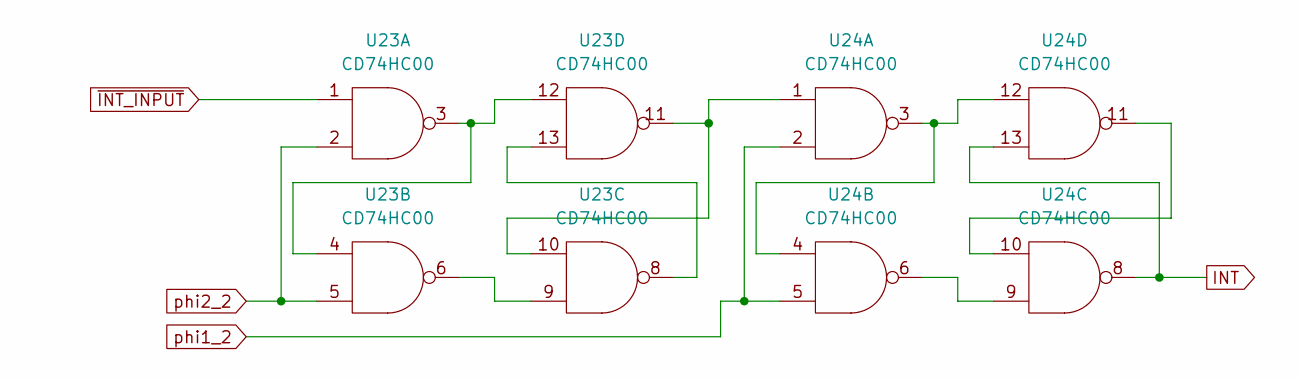
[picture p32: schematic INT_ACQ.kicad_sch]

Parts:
U23, U24: CD74HC00; DIP-14_W7.62mm

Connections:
GND: U23.7 (GND), U24.7 (GND); also elsewhere on the board
INT: U24.8, U24.13; also elsewhere on the board
unnamed: U23.6, U23.9
unnamed: U23.10, U23.11, U24.1
unnamed: U23.3, U23.4, U23.12
unnamed: U23.8, U23.13
unnamed: U24.6, U24.9
unnamed: U24.10, U24.11
unnamed: U24.3, U24.4, U24.12
VCC: U23.14 (VCC), U24.14 (VCC); also elsewhere on the board
phi1_2: U24.2, U24.5; also elsewhere on the board
phi2_2: U23.2, U23.5; also elsewhere on the board
~INT_INPUT: U23.1; also elsewhere on the board

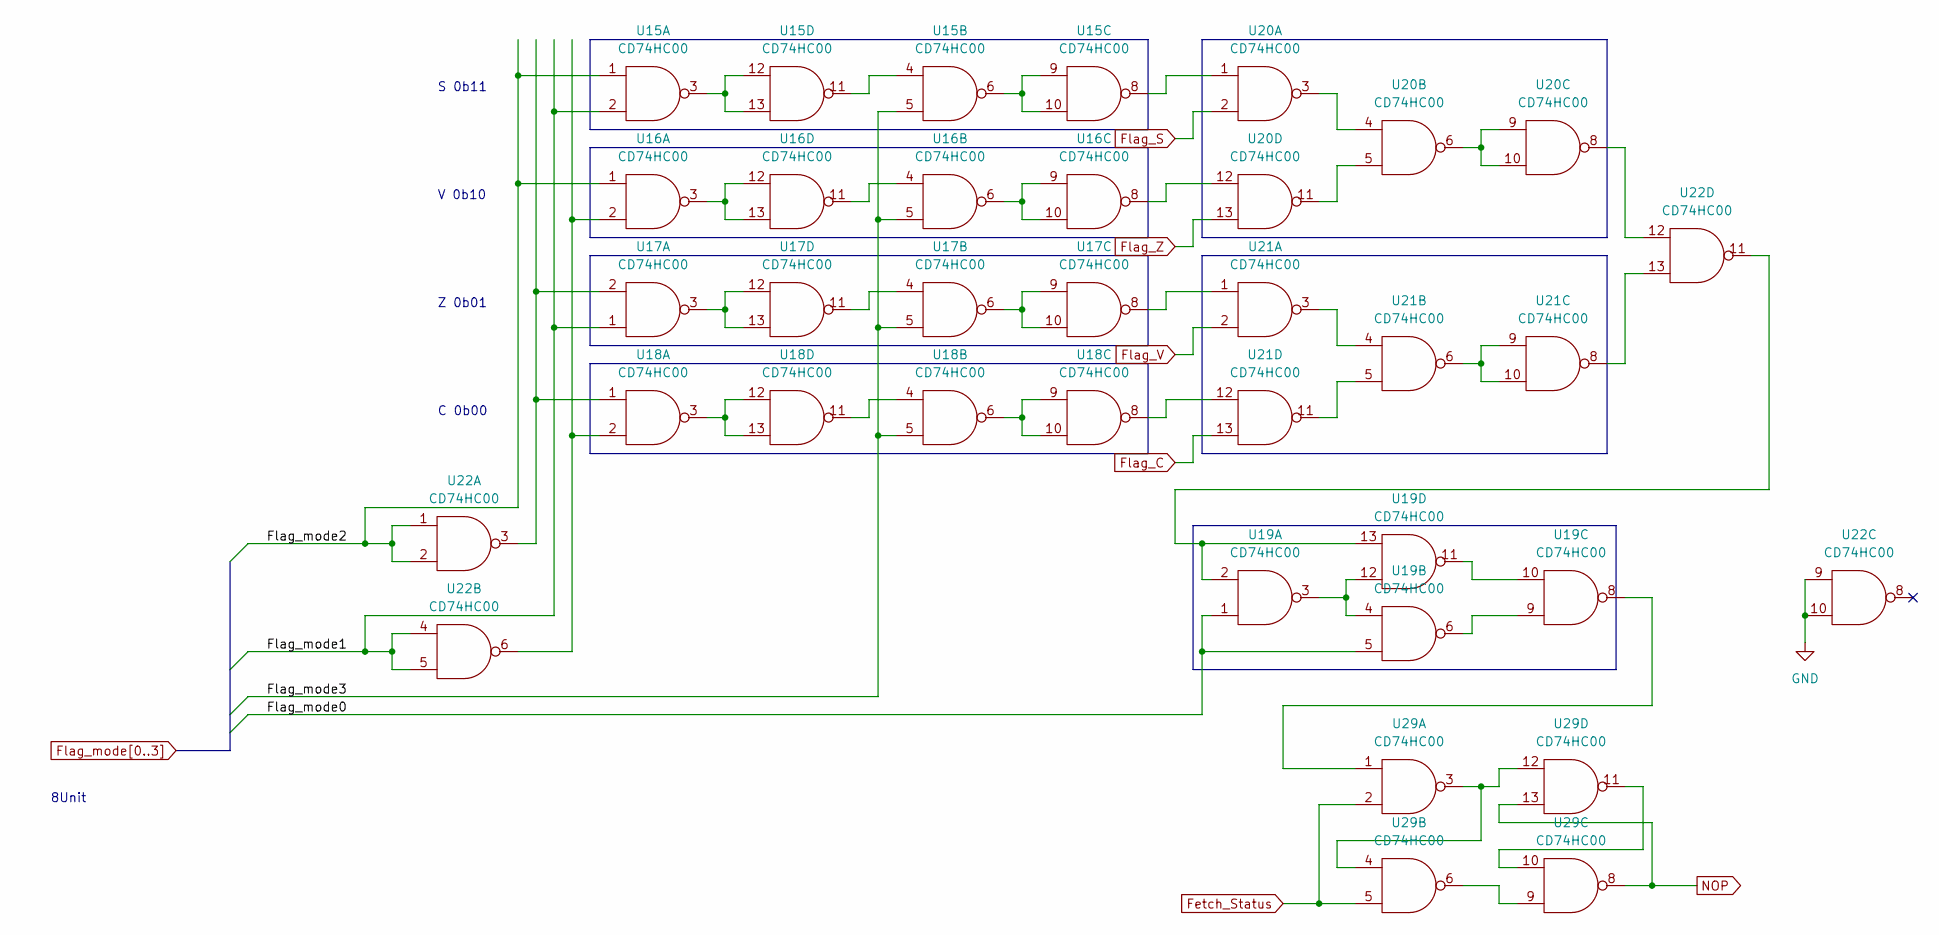
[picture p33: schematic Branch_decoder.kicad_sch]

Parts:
U15, U16, U17, U18, U19, U20, U21, U22, U29: CD74HC00; DIP-14_W7.62mm

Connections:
Fetch_Status: U29.2, U29.5; also elsewhere on the board
Flag_C: U21.13; also elsewhere on the board
Flag_S: U20.2; also elsewhere on the board
Flag_V: U21.2; also elsewhere on the board
Flag_Z: U20.13; also elsewhere on the board
Flag_mode0: U19.1, U19.5; also elsewhere on the board
Flag_mode1: U15.2, U17.1, U22.4, U22.5; also elsewhere on the board
Flag_mode2: U15.1, U16.1, U22.1, U22.2; also elsewhere on the board
Flag_mode3: U15.5, U16.5, U17.5, U18.5; also elsewhere on the board
GND: U15.7 (GND), U16.7 (GND), U17.7 (GND), U18.7 (GND), U19.7 (GND), U20.7 (GND), U21.7 (GND), U22.7 (GND), U22.9, U22.10, U29.7 (GND); also elsewhere on the board
NOP: U29.8, U29.13; also elsewhere on the board
unnamed: U15.8, U20.1
unnamed: U15.6, U15.9, U15.10
unnamed: U15.4, U15.11
unnamed: U15.3, U15.12, U15.13
unnamed: U16.2, U18.2, U22.6
unnamed: U16.8, U20.12
unnamed: U16.6, U16.9, U16.10
unnamed: U16.4, U16.11
unnamed: U16.3, U16.12, U16.13
unnamed: U17.2, U18.1, U22.3
unnamed: U17.8, U21.1
unnamed: U17.6, U17.9, U17.10
unnamed: U17.4, U17.11
unnamed: U17.3, U17.12, U17.13
unnamed: U18.8, U21.12
unnamed: U18.6, U18.9, U18.10
unnamed: U18.4, U18.11
unnamed: U18.3, U18.12, U18.13
unnamed: U19.6, U19.9
unnamed: U19.8, U29.1
unnamed: U19.10, U19.11
unnamed: U19.3, U19.4, U19.12
unnamed: U19.2, U19.13, U22.11
unnamed: U20.3, U20.4
unnamed: U20.8, U22.12
unnamed: U20.6, U20.9, U20.10
unnamed: U20.5, U20.11
unnamed: U21.3, U21.4
unnamed: U21.8, U22.13
unnamed: U21.6, U21.9, U21.10
unnamed: U21.5, U21.11
unnamed: U29.6, U29.9
unnamed: U29.10, U29.11
unnamed: U29.3, U29.4, U29.12
VCC: U15.14 (VCC), U16.14 (VCC), U17.14 (VCC), U18.14 (VCC), U19.14 (VCC), U20.14 (VCC), U21.14 (VCC), U22.14 (VCC), U29.14 (VCC); also elsewhere on the board

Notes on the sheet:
S 0b11
Z 0b01
C 0b00
8Unit
V 0b10


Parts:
U11, U12, U13, U14: CD74HC00; DIP-14_W7.62mm

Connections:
3word: U14.8; also elsewhere on the board
GND: U11.7 (GND), U12.4, U12.5, U12.7 (GND), U13.7 (GND), U14.7 (GND); also elsewhere on the board
unnamed: U11.3, U11.4
unnamed: U11.8, U12.9
unnamed: U11.6, U11.9, U11.10
unnamed: U11.5, U11.11
unnamed: U12.8, U14.10
unnamed: U12.10, U12.11
unnamed: U12.3, U12.12, U12.13
unnamed: U13.3, U13.4
unnamed: U13.8, U14.4
unnamed: U13.6, U13.9, U13.10
unnamed: U13.5, U13.11
unnamed: U14.6, U14.9
unnamed: U14.5, U14.11
unnamed: U14.3, U14.12, U14.13
RA2_0: U12.2; also elsewhere on the board
RA2_1: U12.1; also elsewhere on the board
RA2_2: U11.12, U11.13; also elsewhere on the board
RA2_3: U11.1, U11.2; also elsewhere on the board
RA3_0: U14.2; also elsewhere on the board
RA3_1: U14.1; also elsewhere on the board
RA3_2: U13.12, U13.13; also elsewhere on the board
RA3_3: U13.1, U13.2; also elsewhere on the board
VCC: U11.14 (VCC), U12.14 (VCC), U13.14 (VCC), U14.14 (VCC); also elsewhere on the board

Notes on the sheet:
IR3を1 0 0 0 にすればもっとゲート数を減らせる． ただその場合使用ゲート数が13，つまり4n+1個になり都合が悪いので 0 0 1 1で良い
0 0 1 1をRA1，RA2それぞれで検出 重要:IR3のIDを変更


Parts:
U4, U5, U6, U7, U8, U9, U10: CD74HC00; DIP-14_W7.62mm

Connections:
A_BUS_Addr0: U9.8; also elsewhere on the board
A_BUS_Addr1: U9.11; also elsewhere on the board
A_BUS_Addr2: U8.8; also elsewhere on the board
A_BUS_Addr3: U8.11; also elsewhere on the board
BUS_A/~B: U4.13, U5.13, U6.13, U7.13, U10.1, U10.2; also elsewhere on the board
BUS_A/~Y: U4.10, U5.10, U6.10, U7.10, U10.12, U10.13; also elsewhere on the board
GND: U4.7 (GND), U5.7 (GND), U6.7 (GND), U7.7 (GND), U8.7 (GND), U9.7 (GND), U10.4, U10.5, U10.7 (GND); also elsewhere on the board
unnamed: U4.3, U4.4
unnamed: U4.6, U4.9
unnamed: U4.8, U8.13
unnamed: U4.5, U4.11
unnamed: U5.3, U5.4
unnamed: U5.6, U5.9
unnamed: U5.8, U8.10
unnamed: U5.5, U5.11
unnamed: U6.3, U6.4
unnamed: U6.6, U6.9
unnamed: U6.8, U9.13
unnamed: U6.5, U6.11
unnamed: U7.3, U7.4
unnamed: U7.6, U7.9
unnamed: U7.8, U9.10
unnamed: U7.5, U7.11
unnamed: U8.6, U8.9
unnamed: U8.3, U8.12
unnamed: U9.6, U9.9
unnamed: U9.3, U9.12
unnamed: U4.2, U5.2, U6.2, U7.2, U10.3
unnamed: U8.2, U8.5, U9.2, U9.5, U10.11
RA1_0: U9.4; also elsewhere on the board
RA1_1: U9.1; also elsewhere on the board
RA1_2: U8.4; also elsewhere on the board
RA1_3: U8.1; also elsewhere on the board
RA2_0: U7.12; also elsewhere on the board
RA2_1: U6.12; also elsewhere on the board
RA2_2: U5.12; also elsewhere on the board
RA2_3: U4.12; also elsewhere on the board
RA3_0: U7.1; also elsewhere on the board
RA3_1: U6.1; also elsewhere on the board
RA3_2: U5.1; also elsewhere on the board
RA3_3: U4.1; also elsewhere on the board
VCC: U4.14 (VCC), U5.14 (VCC), U6.14 (VCC), U7.14 (VCC), U8.14 (VCC), U9.14 (VCC), U10.14 (VCC); also elsewhere on the board

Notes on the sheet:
3Unit


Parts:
U1, U2, U3: CD74HC00; DIP-14_W7.62mm

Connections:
GND: U1.7 (GND), U1.12, U1.13, U2.7 (GND), U3.7 (GND); also elsewhere on the board
unnamed: U1.1, U1.6, U1.9
unnamed: U1.3, U1.4
unnamed: U1.8, U2.2
unnamed: U2.6, U2.9
unnamed: U2.10, U2.11
unnamed: U2.3, U2.4, U2.12
unnamed: U2.8, U2.13, U3.2
unnamed: U3.6, U3.9
unnamed: U3.10, U3.11
unnamed: U3.3, U3.4, U3.12
VCC: U1.14 (VCC), U2.14 (VCC), U3.14 (VCC); also elsewhere on the board
phi1_2: U3.1, U3.5; also elsewhere on the board
phi2_2: U2.1, U2.5; also elsewhere on the board
~RS: U1.5, U1.10; also elsewhere on the board
~Seed_pluse: U1.2, U3.8, U3.13; also elsewhere on the board

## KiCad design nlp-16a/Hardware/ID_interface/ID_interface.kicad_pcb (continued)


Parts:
C1, C2, C3, C4, C5, C6, C7, C8, C9, C10, C11, C12, C13, C14, C15, C16, C17, C18, C19, C20, C21, C22: C; C_Disc_D7.0mm_W2.5mm_P5.00mm
C23: C_Polarized; CP_Radial_D5.0mm_P2.50mm
D1, D2, D3, D4, D5, D6, D7, D8, D9, D10, D11: LED; LED_D3.0mm
H1, H2, H3, H4: MountingHole_Pad; MountingHole_3mm_Pad
J1, J5, J6, J7, J8: Screw_Terminal_01x02; TerminalBlock_bornier-2_P5.08mm
J2: Conn_02x10_Counter_Clockwise; PinHeader_2x10_P2.54mm_Horizontal
J3, J4, J9, J10, J11: Conn_02x10_Odd_Even; PinHeader_2x10_P2.54mm_Horizontal
R1, R2, R3, R4, R5: R; R_0603_1608Metric_Pad0.98x0.95mm_HandSolder
RN1: R_Network08_Split; R_Array_SIP9
U10, U25, U26, U27, U28, U30: CD74HC00; DIP-14_W7.62mm

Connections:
3word: D4.2 (A), J4.8; also elsewhere on the board
A_BUS_Addr0: J3.12; also elsewhere on the board
A_BUS_Addr1: J3.10; also elsewhere on the board
A_BUS_Addr2: J3.8; also elsewhere on the board
A_BUS_Addr3: J3.6; also elsewhere on the board
BUS_A/~B: D11.2 (A), J4.9; also elsewhere on the board
BUS_A/~Y: D10.2 (A), J4.7; also elsewhere on the board
Fetch_Status: D7.2 (A), J4.11; also elsewhere on the board
Flag_C: J2.2, J11.6; also elsewhere on the board
Flag_S: J11.12; also elsewhere on the board
Flag_V: J11.8; also elsewhere on the board
Flag_Z: J11.10; also elsewhere on the board
Flag_mode0: J10.14; also elsewhere on the board
Flag_mode1: J10.16; also elsewhere on the board
Flag_mode2: J10.18; also elsewhere on the board
Flag_mode3: J10.20; also elsewhere on the board
GND: C1.1, C2.1, C3.1, C4.1, C5.1, C6.1, C7.1, C8.1, C9.1, C10.1, C11.1, C12.1, C13.1, C14.1, C15.1, C16.1, C17.1, C18.1, C19.1, C20.1, C21.1, C22.1, C23.2, H1.1, H2.1, H3.1, H4.1, J1.1, J2.6, J2.8, J2.10, J2.12, J2.14, J2.16, J2.18, J2.20, J3.2, J3.4, J4.2, J4.4, J5.1, J6.1, J7.1, J8.1, R1.2, R2.2, R3.2, RN1.1 (R1.1), U10.7 (GND), U25.7 (GND), U26.7 (GND), U27.7 (GND), U28.7 (GND), U30.1, U30.2, U30.4, U30.5, U30.7 (GND); also elsewhere on the board
INT: D6.2 (A), J4.10; also elsewhere on the board
INT_EN: D5.2 (A), J4.5
NOP: D9.2 (A), J4.16; also elsewhere on the board
unnamed: D1.1 (K), R1.1
unnamed: D2.1 (K), R2.1
unnamed: D2.2 (A), U25.11
unnamed: D3.1 (K), R3.1
unnamed: D3.2 (A), U26.11
unnamed: D4.1 (K), RN1.9 (R8.2)
unnamed: D5.1 (K), RN1.8 (R7.2)
unnamed: D6.1 (K), RN1.7 (R6.2)
unnamed: D7.1 (K), RN1.6 (R5.2)
unnamed: D8.1 (K), RN1.5 (R4.2)
unnamed: D9.1 (K), RN1.4 (R3.2)
unnamed: D10.1 (K), RN1.3 (R2.2)
unnamed: D11.1 (K), RN1.2 (R1.2)
unnamed: U25.3, U25.4, U25.5, U25.9, U25.10, U25.12, U25.13
unnamed: U26.3, U26.4, U26.5, U26.9, U26.10, U26.12, U26.13
unnamed: U30.9, U30.10, U30.11
OP0: J2.9, J3.19, J10.5
OP1: J2.11, J3.17, J10.7
OP2: J2.13, J3.15, J10.9
OP3: J2.15, J3.13, J10.11
OP4: J2.17, J3.11, J10.13
OP5: J2.19, J3.9, J10.15
OP6: J3.7, J10.17
OP7: J3.5, J10.19, U10.9, U10.10
RA1_0: J3.20, J10.6; also elsewhere on the board
RA1_1: J3.18, J10.8; also elsewhere on the board
RA1_2: J3.16, J10.10; also elsewhere on the board
RA1_3: J3.14, J10.12; also elsewhere on the board
RA2_0: J9.13; also elsewhere on the board
RA2_1: J9.15; also elsewhere on the board
RA2_2: J9.17; also elsewhere on the board
RA2_3: J9.19; also elsewhere on the board
RA3_0: J9.5; also elsewhere on the board
RA3_1: J9.7; also elsewhere on the board
RA3_2: J9.9; also elsewhere on the board
RA3_3: J9.11; also elsewhere on the board
VCC: C1.2, C2.2, C3.2, C4.2, C5.2, C6.2, C7.2, C8.2, C9.2, C10.2, C11.2, C12.2, C13.2, C14.2, C15.2, C16.2, C17.2, C18.2, C19.2, C20.2, C21.2, C22.2, C23.1, D1.2 (A), J1.2, R4.2, R5.2, U10.14 (VCC), U25.14 (VCC), U26.14 (VCC), U27.14 (VCC), U28.14 (VCC), U30.13, U30.14 (VCC); also elsewhere on the board
Y_Flag_sel: J2.4, J4.13
phi1: J5.2, U25.1, U25.2
phi1_1: J4.20, U25.8
phi1_2: U25.6; also elsewhere on the board
phi2: J6.2, U26.1, U26.2
phi2_1: J4.18, U26.8
phi2_2: U26.6; also elsewhere on the board
~Addr_ALU: J2.7, U10.8
~DEC_ALU: J2.1, J4.15
~INC_ALU: J2.3, J4.17
~INTERNAL_ALU: J2.5, J4.19
~INT_INPUT: J8.2, R5.1; also elsewhere on the board
~RS_INPUT: J7.2, R4.1, U30.12
~RS: D8.2 (A), J4.14, U30.8; also elsewhere on the board
~Seed_pluse: J4.12; also elsewhere on the board

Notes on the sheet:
Ctrl0-5 IR 8-13 Ctrl6 ADDRESS_MODE(IR1 15) Ctrl7 ~INTERNAL_MOV Ctrl8 ~INTERNAL_INC Ctrl9 ~INTERNAL_DEC ADDRESS_MODE: アドレッシング時の演算モードに切り替え．演算命令以外でこのモードになる． INTERNAL_MOV: 内部処理での値を移動するときのモード． ADDRESS_MODEより優先される． INTERNAI_INC: 内部処理でインクリメントするときのモード． このモードを使用する際にはINTERNAL_MOVが有効である必要がある． ADDRESS_MODEより優先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
IR2
Flag
LでYが出力
Power
== ALU Ctrl入力 == IR1の8-13 MOV,JMP キャリーフラグ(with carryな命令用) 動作指定用 ALU_G 動作指定用 MOV 動作指定用 ~INC/DEC == Y/Flagセレクタ == Y/Flag 計12ピン
IR1
Reg RD -IV -MEM -IP -SP WR -IR1 -IR2 -IR3 -Acc -Flag -MEM -Address -IP -SP Ctrl -Internal 変更↓ A BUS 4本 Y BUS 4本
ALU -Internal -INC -DEC -Address -Y/F
v1.1以上
etc -3word -NOP -INT -Fetch -RS -BUS Dir -BUS A,B -Seed_pluse CLK -phi1 -phi2
Operand -OP7 -OP6 -OP5 -OP4 -OP1 -OP0
Y BUS
ALU制御バス


Board: 2 copper layers, 209.6 x 154.9 mm, 85 parts (0 on the bottom side), 159 nets.

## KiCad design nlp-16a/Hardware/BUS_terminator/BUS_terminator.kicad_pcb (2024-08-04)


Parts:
RN3, RN4: R_Network08; R_Array_SIP9
U21, U22: 74HCT541; DIP-20_W7.62mm
U25: CD74HC00; DIP-14_W7.62mm

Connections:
A_SEL: U25.12; also elsewhere on the board
Address_in0: U22.9 (A7); also elsewhere on the board
Address_in1: U22.7 (A5); also elsewhere on the board
Address_in2: U22.5 (A3); also elsewhere on the board
Address_in3: U22.3 (A1); also elsewhere on the board
Address_in4: U21.9 (A7); also elsewhere on the board
Address_in5: U21.7 (A5); also elsewhere on the board
Address_in6: U21.5 (A3); also elsewhere on the board
Address_in7: U21.3 (A1); also elsewhere on the board
Address_in8: U22.8 (A6); also elsewhere on the board
Address_in9: U22.6 (A4); also elsewhere on the board
Address_in10: U22.4 (A2); also elsewhere on the board
Address_in11: U22.2 (A0); also elsewhere on the board
Address_in12: U21.8 (A6); also elsewhere on the board
Address_in13: U21.6 (A4); also elsewhere on the board
Address_in14: U21.4 (A2); also elsewhere on the board
Address_in15: U21.2 (A0); also elsewhere on the board
Address_out0: RN4.9 (R8), U22.11 (Y7); also elsewhere on the board
Address_out1: RN4.7 (R6), U22.13 (Y5); also elsewhere on the board
Address_out2: RN4.5 (R4), U22.15 (Y3); also elsewhere on the board
Address_out3: RN4.3 (R2), U22.17 (Y1); also elsewhere on the board
Address_out4: RN3.9 (R8), U21.11 (Y7); also elsewhere on the board
Address_out5: RN3.7 (R6), U21.13 (Y5); also elsewhere on the board
Address_out6: RN3.5 (R4), U21.15 (Y3); also elsewhere on the board
Address_out7: RN3.3 (R2), U21.17 (Y1); also elsewhere on the board
Address_out8: RN4.8 (R7), U22.12 (Y6); also elsewhere on the board
Address_out9: RN4.6 (R5), U22.14 (Y4); also elsewhere on the board
Address_out10: RN4.4 (R3), U22.16 (Y2); also elsewhere on the board
Address_out11: RN4.2 (R1), U22.18 (Y0); also elsewhere on the board
Address_out12: RN3.8 (R7), U21.12 (Y6); also elsewhere on the board
Address_out13: RN3.6 (R5), U21.14 (Y4); also elsewhere on the board
Address_out14: RN3.4 (R3), U21.16 (Y2); also elsewhere on the board
Address_out15: RN3.2 (R1), U21.18 (Y0); also elsewhere on the board
GND: U21.10 (GND), U21.19 (G2), U22.10 (GND), U22.19 (G2), U25.7 (GND); also elsewhere on the board
unnamed: U21.1 (G1), U22.1 (G1), U25.8
unnamed: U25.3, U25.4
unnamed: U25.6, U25.9, U25.10
unnamed: U25.5, U25.11
VCC: RN3.1 (common), RN4.1 (common), U21.20 (VCC), U22.20 (VCC), U25.1, U25.13, U25.14 (VCC); also elsewhere on the board
Y_SEL: U25.2; also elsewhere on the board


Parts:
C1, C2, C3, C4, C5, C6, C7, C17: C; C_Disc_D7.0mm_W2.5mm_P5.00mm
C8: C_Polarized; CP_Radial_D5.0mm_P2.50mm
D1: LED; LED_D3.0mm
H1, H2, H3, H4: MountingHole_Pad; MountingHole_3mm_Pad
J1, J2, J3: Conn_02x20_Odd_Even; PinHeader_2x20_P2.54mm_Horizontal
J4: Conn_02x10_Odd_Even; PinHeader_2x10_P2.54mm_Horizontal
J5: Screw_Terminal_01x02; TerminalBlock_bornier-2_P5.08mm
J6, J7: Conn_02x16_Odd_Even; PinHeader_2x16_P2.54mm_Vertical
R1, R2, R3, R4, R5, R6, R7, R8, R9, R10, R11, R12, R13, R14, R15, R16: 22; R_0603_1608Metric_Pad0.98x0.95mm_HandSolder
R17: R; R_0603_1608Metric_Pad0.98x0.95mm_HandSolder

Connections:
A_SEL: J3.33, J7.1, J7.3, J7.5, J7.7, J7.9, J7.11, J7.13, J7.15, J7.17, J7.19, J7.21, J7.23, J7.25, J7.27, J7.29, J7.31; also elsewhere on the board
Address_in0: J4.6; also elsewhere on the board
Address_in1: J4.8; also elsewhere on the board
Address_in2: J4.10; also elsewhere on the board
Address_in3: J4.12; also elsewhere on the board
Address_in4: J4.14; also elsewhere on the board
Address_in5: J4.16; also elsewhere on the board
Address_in6: J4.18; also elsewhere on the board
Address_in7: J4.20; also elsewhere on the board
Address_in8: J4.5; also elsewhere on the board
Address_in9: J4.7; also elsewhere on the board
Address_in10: J4.9; also elsewhere on the board
Address_in11: J4.11; also elsewhere on the board
Address_in12: J4.13; also elsewhere on the board
Address_in13: J4.15; also elsewhere on the board
Address_in14: J4.17; also elsewhere on the board
Address_in15: J4.19; also elsewhere on the board
Address_out0: J3.2; also elsewhere on the board
Address_out1: J3.4; also elsewhere on the board
Address_out2: J3.6; also elsewhere on the board
Address_out3: J3.8; also elsewhere on the board
Address_out4: J3.10; also elsewhere on the board
Address_out5: J3.12; also elsewhere on the board
Address_out6: J3.14; also elsewhere on the board
Address_out7: J3.16; also elsewhere on the board
Address_out8: J3.18; also elsewhere on the board
Address_out9: J3.20; also elsewhere on the board
Address_out10: J3.22; also elsewhere on the board
Address_out11: J3.24; also elsewhere on the board
Address_out12: J3.26; also elsewhere on the board
Address_out13: J3.28; also elsewhere on the board
Address_out14: J3.30; also elsewhere on the board
Address_out15: J3.32; also elsewhere on the board
BUS_Correction: J2.35; also elsewhere on the board
Data_Correction: J2.33; also elsewhere on the board
GND: C1.2, C2.2, C3.2, C4.2, C5.2, C6.2, C7.2, C8.2, C17.2, H1.1, H2.1, H3.1, H4.1, J1.35, J1.37, J1.39, J2.37, J2.39, J3.37, J3.39, J5.1, R17.2; also elsewhere on the board
IN0: J1.31; also elsewhere on the board
IN1: J1.29; also elsewhere on the board
IN2: J1.27; also elsewhere on the board
IN3: J1.25; also elsewhere on the board
IN4: J1.23; also elsewhere on the board
IN5: J1.21; also elsewhere on the board
IN6: J1.19; also elsewhere on the board
IN7: J1.17; also elsewhere on the board
IN8: J1.15; also elsewhere on the board
IN9: J1.13; also elsewhere on the board
IN10: J1.11; also elsewhere on the board
IN11: J1.9; also elsewhere on the board
IN12: J1.7; also elsewhere on the board
IN13: J1.5; also elsewhere on the board
IN14: J1.3; also elsewhere on the board
IN15: J1.1; also elsewhere on the board
IO_BUS0: J3.1; also elsewhere on the board
IO_BUS1: J3.3; also elsewhere on the board
IO_BUS2: J3.5; also elsewhere on the board
IO_BUS3: J3.7; also elsewhere on the board
IO_BUS4: J3.9; also elsewhere on the board
IO_BUS5: J3.11; also elsewhere on the board
IO_BUS6: J3.13; also elsewhere on the board
IO_BUS7: J3.15; also elsewhere on the board
IO_BUS8: J3.17; also elsewhere on the board
IO_BUS9: J3.19; also elsewhere on the board
IO_BUS10: J3.21; also elsewhere on the board
IO_BUS11: J3.23; also elsewhere on the board
IO_BUS12: J3.25; also elsewhere on the board
IO_BUS13: J3.27; also elsewhere on the board
IO_BUS14: J3.29; also elsewhere on the board
IO_BUS15: J3.31; also elsewhere on the board
unnamed: D1.1 (K), R17.1
unnamed: J1.2, J6.2
unnamed: J1.4, J6.4
unnamed: J1.6, J6.6
unnamed: J1.8, J6.8
unnamed: J1.10, J6.10
unnamed: J1.12, J6.12
unnamed: J1.14, J6.14
unnamed: J1.16, J6.16
unnamed: J1.18, J6.18
unnamed: J1.20, J6.20
unnamed: J1.22, J6.22
unnamed: J1.24, J6.24
unnamed: J1.26, J6.26
unnamed: J1.28, J6.28
unnamed: J1.30, J6.30
unnamed: J1.32, J6.32
unnamed: J2.1, R16.1
unnamed: J2.2, J7.2
unnamed: J2.3, R15.1
unnamed: J2.4, J7.4
unnamed: J2.5, R14.1
unnamed: J2.6, J7.6
unnamed: J2.7, R13.1
unnamed: J2.8, J7.8
unnamed: J2.9, R12.1
unnamed: J2.10, J7.10
unnamed: J2.11, R11.1
unnamed: J2.12, J7.12
unnamed: J2.13, R10.1
unnamed: J2.14, J7.14
unnamed: J2.15, R9.1
unnamed: J2.16, J7.16
unnamed: J2.17, R8.1
unnamed: J2.18, J7.18
unnamed: J2.19, R7.1
unnamed: J2.20, J7.20
unnamed: J2.21, R6.1
unnamed: J2.22, J7.22
unnamed: J2.23, R5.1
unnamed: J2.24, J7.24
unnamed: J2.25, R4.1
unnamed: J2.26, J7.26
unnamed: J2.27, R3.1
unnamed: J2.28, J7.28
unnamed: J2.29, R2.1
unnamed: J2.30, J7.30
unnamed: J2.31, R1.1
unnamed: J2.32, J7.32
OUT0: R1.2; also elsewhere on the board
OUT1: R2.2; also elsewhere on the board
OUT2: R3.2; also elsewhere on the board
OUT3: R4.2; also elsewhere on the board
OUT4: R5.2; also elsewhere on the board
OUT5: R6.2; also elsewhere on the board
OUT6: R7.2; also elsewhere on the board
OUT7: R8.2; also elsewhere on the board
OUT8: R9.2; also elsewhere on the board
OUT9: R10.2; also elsewhere on the board
OUT10: R11.2; also elsewhere on the board
OUT11: R12.2; also elsewhere on the board
OUT12: R13.2; also elsewhere on the board
OUT13: R14.2; also elsewhere on the board
OUT14: R15.2; also elsewhere on the board
OUT15: R16.2; also elsewhere on the board
RD_CLK: J3.34; also elsewhere on the board
VCC: C1.1, C2.1, C3.1, C4.1, C5.1, C6.1, C7.1, C8.1, C17.1, D1.2 (A), J1.38, J1.40, J2.38, J2.40, J3.38, J3.40, J5.2; also elsewhere on the board
WR_CLK: J3.36; also elsewhere on the board
Y_SEL: J3.35, J6.1, J6.3, J6.5, J6.7, J6.9, J6.11, J6.13, J6.15, J6.17, J6.19, J6.21, J6.23, J6.25, J6.27, J6.29, J6.31; also elsewhere on the board
phi1: J1.36; also elsewhere on the board
phi2: J1.34; also elsewhere on the board

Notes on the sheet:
OUTPUT - Data 16bit - Address 16bit - phi1 1bit - phi2 1bit - RD 1bit - WR 1bit
Writeサイクル ・phi2で転送先MEMアドレス確定 ・phi1で転送元Regアドレス確定 ・phi1立下りでTMP Regに転送元データ転送完了 ・phi2で転送先Regアドレス確定 ・phi2立下りでMEMにデータ転送完了
リードサイクル アドレス確定，RD→L phi1にパルス TMPへ転送 RD→H
A_SEL -> RD Y_SEL -> WE
RDはデバイス側のOEに接続
・phi2でアドレス確定 ・phi1でRegアドレス確定 ・phi1立下りでTMP Regにデータ転送完了 ・phi2で転送先Regに転送完了
WR,RDはReg Addrから生成されるアサート信号
ライトサイクル アドレス確定，WR→L phi2にパルス，WRとANDを取って書き込みパルス WR→H
phi1,2を供給し，各デバイスでENを検知する


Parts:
C9, C10, C12, C13, C14, C15, C16: C; C_Disc_D7.0mm_W2.5mm_P5.00mm
J8, J9: Conn_02x10_Odd_Even; PinHeader_2x10_P2.54mm_Horizontal
U13, U14, U15, U16, U19, U20: CD74HC00; DIP-14_W7.62mm
U23, U24: TC551001; DIP-32_W15.24mm

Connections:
GND: C9.2, C10.2, C12.2, C13.2, C14.2, C15.2, C16.2, U13.7 (GND), U14.7 (GND), U15.7 (GND), U16.7 (GND), U19.7 (GND), U20.7 (GND), U23.16 (GND), U24.16 (GND); also elsewhere on the board
VCC: C9.1, C10.1, C12.1, C13.1, C14.1, C15.1, C16.1, U13.14 (VCC), U14.14 (VCC), U15.14 (VCC), U16.14 (VCC), U19.14 (VCC), U20.14 (VCC), U23.32 (VCC), U24.32 (VCC); also elsewhere on the board

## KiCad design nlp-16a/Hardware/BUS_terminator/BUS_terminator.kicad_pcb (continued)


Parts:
D2, D3: LED; LED_D3.0mm
R18, R19: R; R_0603_1608Metric_Pad0.98x0.95mm_HandSolder
RN1, RN2: R_Network08; R_Array_SIP9
U1, U2, U3, U4, U5, U6, U7, U8, U11, U12: CD74HC00; DIP-14_W7.62mm
U9, U10: 74HCT541; DIP-20_W7.62mm

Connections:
A_SEL: U11.2, U12.4; also elsewhere on the board
BUS_Correction: U11.5, U11.10; also elsewhere on the board
Data_Correction: U5.2, U5.5, U6.2, U6.5, U7.2, U7.5, U8.2, U8.5, U12.3; also elsewhere on the board
GND: U1.7 (GND), U2.7 (GND), U3.7 (GND), U4.7 (GND), U5.7 (GND), U6.7 (GND), U7.7 (GND), U8.7 (GND), U9.1 (G1), U9.10 (GND), U10.1 (G1), U10.10 (GND), U11.7 (GND), U12.7 (GND); also elsewhere on the board
IN0: U10.9 (A7); also elsewhere on the board
IN1: U10.8 (A6); also elsewhere on the board
IN2: U10.7 (A5); also elsewhere on the board
IN3: U10.6 (A4); also elsewhere on the board
IN4: U10.5 (A3); also elsewhere on the board
IN5: U10.4 (A2); also elsewhere on the board
IN6: U10.3 (A1); also elsewhere on the board
IN7: U10.2 (A0); also elsewhere on the board
IN8: U9.9 (A7); also elsewhere on the board
IN9: U9.8 (A6); also elsewhere on the board
IN10: U9.7 (A5); also elsewhere on the board
IN11: U9.6 (A4); also elsewhere on the board
IN12: U9.5 (A3); also elsewhere on the board
IN13: U9.4 (A2); also elsewhere on the board
IN14: U9.3 (A1); also elsewhere on the board
IN15: U9.2 (A0); also elsewhere on the board
IO_BUS0: RN2.9 (R8), U8.4, U10.11 (Y7); also elsewhere on the board
IO_BUS1: RN2.8 (R7), U8.1, U10.12 (Y6); also elsewhere on the board
IO_BUS2: RN2.7 (R6), U7.4, U10.13 (Y5); also elsewhere on the board
IO_BUS3: RN2.6 (R5), U7.1, U10.14 (Y4); also elsewhere on the board
IO_BUS4: RN2.5 (R4), U6.4, U10.15 (Y3); also elsewhere on the board
IO_BUS5: RN2.4 (R3), U6.1, U10.16 (Y2); also elsewhere on the board
IO_BUS6: RN2.3 (R2), U5.4, U10.17 (Y1); also elsewhere on the board
IO_BUS7: RN2.2 (R1), U5.1, U10.18 (Y0); also elsewhere on the board
IO_BUS8: RN1.9 (R8), U4.4, U9.11 (Y7); also elsewhere on the board
IO_BUS9: RN1.8 (R7), U4.1, U9.12 (Y6); also elsewhere on the board
IO_BUS10: RN1.7 (R6), U3.4, U9.13 (Y5); also elsewhere on the board
IO_BUS11: RN1.6 (R5), U3.1, U9.14 (Y4); also elsewhere on the board
IO_BUS12: RN1.5 (R4), U2.4, U9.15 (Y3); also elsewhere on the board
IO_BUS13: RN1.4 (R3), U2.1, U9.16 (Y2); also elsewhere on the board
IO_BUS14: RN1.3 (R2), U1.4, U9.17 (Y1); also elsewhere on the board
IO_BUS15: RN1.2 (R1), U1.1, U9.18 (Y0); also elsewhere on the board
unnamed: D2.1 (K), U11.3, U11.4, U11.9, U11.12, U11.13, U12.1, U12.2, U12.12
unnamed: D2.2 (A), R18.2
unnamed: D3.1 (K), U9.19 (G2), U10.19 (G2), U12.11
unnamed: D3.2 (A), R19.2
unnamed: U1.2, U1.5, U2.2, U2.5, U3.2, U3.5, U4.2, U4.5, U11.11
unnamed: U1.6, U1.9
unnamed: U1.10, U1.13, U2.10, U2.13, U3.10, U3.13, U4.10, U4.13, U11.6
unnamed: U1.3, U1.12
unnamed: U2.6, U2.9
unnamed: U2.3, U2.12
unnamed: U3.6, U3.9
unnamed: U3.3, U3.12
unnamed: U4.6, U4.9
unnamed: U4.3, U4.12
unnamed: U5.6, U5.9
unnamed: U5.3, U5.12
unnamed: U6.6, U6.9
unnamed: U6.3, U6.12
unnamed: U7.6, U7.9
unnamed: U7.3, U7.12
unnamed: U8.6, U8.9
unnamed: U8.3, U8.12
unnamed: U5.10, U5.13, U6.10, U6.13, U7.10, U7.13, U8.10, U8.13, U11.8
OUT0: U8.8; also elsewhere on the board
OUT1: U8.11; also elsewhere on the board
OUT2: U7.8; also elsewhere on the board
OUT3: U7.11; also elsewhere on the board
OUT4: U6.8; also elsewhere on the board
OUT5: U6.11; also elsewhere on the board
OUT6: U5.8; also elsewhere on the board
OUT7: U5.11; also elsewhere on the board
OUT8: U4.8; also elsewhere on the board
OUT9: U4.11; also elsewhere on the board
OUT10: U3.8; also elsewhere on the board
OUT11: U3.11; also elsewhere on the board
OUT12: U2.8; also elsewhere on the board
OUT13: U2.11; also elsewhere on the board
OUT14: U1.8; also elsewhere on the board
OUT15: U1.11; also elsewhere on the board
RD_CLK: U12.6; also elsewhere on the board
VCC: R18.1, R19.1, RN1.1 (common), RN2.1 (common), U1.14 (VCC), U2.14 (VCC), U3.14 (VCC), U4.14 (VCC), U5.14 (VCC), U6.14 (VCC), U7.14 (VCC), U8.14 (VCC), U9.20 (VCC), U10.20 (VCC), U11.1, U11.14 (VCC), U12.14 (VCC); also elsewhere on the board
WR_CLK: U12.8; also elsewhere on the board
Y_SEL: U12.10, U12.13; also elsewhere on the board
phi1: U12.5; also elsewhere on the board
phi2: U12.9; also elsewhere on the board

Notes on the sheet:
上位bit
A_SEL == LOW && Y_SEL == HIGH -> /OE = LOW
Y BUS


Board: 2 copper layers, 209.6 x 154.9 mm, 78 parts (0 on the bottom side), 166 nets.

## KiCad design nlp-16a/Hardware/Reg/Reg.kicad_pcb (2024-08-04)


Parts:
C1, C2, C3, C4, C5, C6, C7, C8, C9, C10, C11, C12, C13, C14, C15, C16, C18, C19: C; C_Disc_D7.5mm_W2.5mm_P5.00mm
C17: C_Polarized; CP_Radial_D5.0mm_P2.50mm
D17: LED; LED_D3.0mm
H1, H2, H3, H4: MountingHole_Pad; MountingHole_3mm_Pad
J1, J2: Conn_02x20_Odd_Even; PinHeader_2x20_P2.54mm_Vertical
J3, J4: Conn_02x20_Odd_Even; PinHeader_2x20_P2.54mm_Horizontal
J5, J6: Conn_02x16_Odd_Even; PinHeader_2x16_P2.54mm_Vertical
J7: Screw_Terminal_01x02; TerminalBlock_bornier-2_P5.08mm
J8: Conn_02x10_Odd_Even; PinHeader_2x10_P2.54mm_Horizontal
R1, R2, R3, R4, R5, R6, R7, R8, R9, R10, R11, R12, R13, R14, R15, R16: 22; R_0603_1608Metric_Pad0.98x0.95mm_HandSolder
R33, R36, R37: R; R_0603_1608Metric_Pad0.98x0.95mm_HandSolder
U35, U36: CD74HC00; DIP-14_W7.62mm

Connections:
A_Address0: J2.32, J4.32, J6.32
A_Address1: J2.30, J4.30, J6.30
A_Address2: J2.28, J4.28, J6.28
A_Address3: J2.26, J4.26, J6.26
A_Address4: J2.24, J4.24, J6.24
A_Address5: J2.22, J4.22, J6.22
A_Address6: J2.20, J4.20, J6.20
A_Address7: J2.18, J4.18, J6.18
A_Address8: J2.16, J4.16, J6.16
A_Address9: J2.14, J4.14, J6.14
A_Address10: J2.12, J4.12, J6.12
A_Address11: J2.10, J4.10, J6.10
A_Address12: J2.8, J4.8, J6.8
A_Address13: J2.6, J4.6, J6.6
A_Address14: J2.4, J4.4, J6.4
A_Address15: J2.2, J4.2, J6.2
A_IN0: J4.31; also elsewhere on the board
A_IN1: J4.29; also elsewhere on the board
A_IN2: J4.27; also elsewhere on the board
A_IN3: J4.25; also elsewhere on the board
A_IN4: J4.23; also elsewhere on the board
A_IN5: J4.21; also elsewhere on the board
A_IN6: J4.19; also elsewhere on the board
A_IN7: J4.17; also elsewhere on the board
A_IN8: J4.15; also elsewhere on the board
A_IN9: J4.13; also elsewhere on the board
A_IN10: J4.11; also elsewhere on the board
A_IN11: J4.9; also elsewhere on the board
A_IN12: J4.7; also elsewhere on the board
A_IN13: J4.5; also elsewhere on the board
A_IN14: J4.3; also elsewhere on the board
A_IN15: J4.1; also elsewhere on the board
A_OUT0: R1.2; also elsewhere on the board
A_OUT1: R2.2; also elsewhere on the board
A_OUT2: R3.2; also elsewhere on the board
A_OUT3: R4.2; also elsewhere on the board
A_OUT4: R5.2; also elsewhere on the board
A_OUT5: R6.2; also elsewhere on the board
A_OUT6: R7.2; also elsewhere on the board
A_OUT7: R8.2; also elsewhere on the board
A_OUT8: R9.2; also elsewhere on the board
A_OUT9: R10.2; also elsewhere on the board
A_OUT10: R11.2; also elsewhere on the board
A_OUT11: R12.2; also elsewhere on the board
A_OUT12: R13.2; also elsewhere on the board
A_OUT13: R14.2; also elsewhere on the board
A_OUT14: R15.2; also elsewhere on the board
A_OUT15: R16.2; also elsewhere on the board
A_SEL: J6.1, J6.3, J6.5, J6.7, J6.9, J6.11, J6.13, J6.15, J6.17, J6.19, J6.21, J6.23, J6.25, J6.27, J6.29, J6.31, R37.2; also elsewhere on the board
BUS_Correction_IN: J2.35; also elsewhere on the board
BUS_Correction_OUT: J4.35; also elsewhere on the board
Data_Correction_IN: J4.33; also elsewhere on the board
Data_Correction_OUT: J2.33; also elsewhere on the board
GND: C1.2, C2.2, C3.2, C4.2, C5.2, C6.2, C7.2, C8.2, C9.2, C10.2, C11.2, C12.2, C13.2, C14.2, C15.2, C16.2, C17.2, C18.2, C19.2, H1.1, H2.1, H3.1, H4.1, J1.35, J1.37, J1.39, J2.37, J2.39, J3.35, J3.37, J3.39, J4.37, J4.39, J7.1, R33.2, U35.7 (GND), U36.7 (GND); also elsewhere on the board
unnamed: D17.1 (K), R33.1
unnamed: J2.1, R16.1
unnamed: J2.3, R15.1
unnamed: J2.5, R14.1
unnamed: J2.7, R13.1
unnamed: J2.9, R12.1
unnamed: J2.11, R11.1
unnamed: J2.13, R10.1
unnamed: J2.15, R9.1
unnamed: J2.17, R8.1
unnamed: J2.19, R7.1
unnamed: J2.21, R6.1
unnamed: J2.23, R5.1
unnamed: J2.25, R4.1
unnamed: J2.27, R3.1
unnamed: J2.29, R2.1
unnamed: J2.31, R1.1
unnamed: U35.3, U35.12, U35.13
unnamed: U36.3, U36.12, U36.13
Reg_out0: J8.6; also elsewhere on the board
Reg_out1: J8.8; also elsewhere on the board
Reg_out2: J8.10; also elsewhere on the board
Reg_out3: J8.12; also elsewhere on the board
Reg_out4: J8.14; also elsewhere on the board
Reg_out5: J8.16; also elsewhere on the board
Reg_out6: J8.18; also elsewhere on the board
Reg_out7: J8.20; also elsewhere on the board
Reg_out8: J8.5; also elsewhere on the board
Reg_out9: J8.7; also elsewhere on the board
Reg_out10: J8.9; also elsewhere on the board
Reg_out11: J8.11; also elsewhere on the board
Reg_out12: J8.13; also elsewhere on the board
Reg_out13: J8.15; also elsewhere on the board
Reg_out14: J8.17; also elsewhere on the board
Reg_out15: J8.19; also elsewhere on the board
VCC: C1.1, C2.1, C3.1, C4.1, C5.1, C6.1, C7.1, C8.1, C9.1, C10.1, C11.1, C12.1, C13.1, C14.1, C15.1, C16.1, C17.1, C18.1, C19.1, D17.2 (A), J1.38, J1.40, J2.38, J2.40, J3.38, J3.40, J4.38, J4.40, J7.2, R36.1, R37.1, U35.2, U35.14 (VCC), U36.2, U36.14 (VCC); also elsewhere on the board
Y_Address0: J1.32, J3.32, J5.32
Y_Address1: J1.30, J3.30, J5.30
Y_Address2: J1.28, J3.28, J5.28
Y_Address3: J1.26, J3.26, J5.26
Y_Address4: J1.24, J3.24, J5.24
Y_Address5: J1.22, J3.22, J5.22
Y_Address6: J1.20, J3.20, J5.20
Y_Address7: J1.18, J3.18, J5.18
Y_Address8: J1.16, J3.16, J5.16
Y_Address9: J1.14, J3.14, J5.14
Y_Address10: J1.12, J3.12, J5.12
Y_Address11: J1.10, J3.10, J5.10
Y_Address12: J1.8, J3.8, J5.8
Y_Address13: J1.6, J3.6, J5.6
Y_Address14: J1.4, J3.4, J5.4
Y_Address15: J1.2, J3.2, J5.2
Y_IN0: J1.31; also elsewhere on the board
Y_IN1: J1.29; also elsewhere on the board
Y_IN2: J1.27; also elsewhere on the board
Y_IN3: J1.25; also elsewhere on the board
Y_IN4: J1.23; also elsewhere on the board
Y_IN5: J1.21; also elsewhere on the board
Y_IN6: J1.19; also elsewhere on the board
Y_IN7: J1.17; also elsewhere on the board
Y_IN8: J1.15; also elsewhere on the board
Y_IN9: J1.13; also elsewhere on the board
Y_IN10: J1.11; also elsewhere on the board
Y_IN11: J1.9; also elsewhere on the board
Y_IN12: J1.7; also elsewhere on the board
Y_IN13: J1.5; also elsewhere on the board
Y_IN14: J1.3; also elsewhere on the board
Y_IN15: J1.1; also elsewhere on the board
Y_OUT0: J3.31; also elsewhere on the board
Y_OUT1: J3.29; also elsewhere on the board
Y_OUT2: J3.27; also elsewhere on the board
Y_OUT3: J3.25; also elsewhere on the board
Y_OUT4: J3.23; also elsewhere on the board
Y_OUT5: J3.21; also elsewhere on the board
Y_OUT6: J3.19; also elsewhere on the board
Y_OUT7: J3.17; also elsewhere on the board
Y_OUT8: J3.15; also elsewhere on the board
Y_OUT9: J3.13; also elsewhere on the board
Y_OUT10: J3.11; also elsewhere on the board
Y_OUT11: J3.9; also elsewhere on the board
Y_OUT12: J3.7; also elsewhere on the board
Y_OUT13: J3.5; also elsewhere on the board
Y_OUT14: J3.3; also elsewhere on the board
Y_OUT15: J3.1; also elsewhere on the board
Y_SEL: J5.1, J5.3, J5.5, J5.7, J5.9, J5.11, J5.13, J5.15, J5.17, J5.19, J5.21, J5.23, J5.25, J5.27, J5.29, J5.31, R36.2; also elsewhere on the board
phi1_in: J1.36, U36.1
phi1_out: J3.36, U36.11
phi2_in: J1.34, U35.1
phi2_out: J3.34, U35.11; also elsewhere on the board
~CLR_in: J1.33; also elsewhere on the board
~CLR_out: J3.33; also elsewhere on the board

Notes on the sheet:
上流側
下流側


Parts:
JP1, JP2, JP3, JP4, JP5, JP6, JP7, JP8, JP9, JP10, JP11, JP12, JP13, JP14, JP15, JP16: SolderJumper_2_Open; SolderJumper-2_P1.3mm_Open_RoundedPad1.0x1.5mm
R17, R18, R19, R20, R21, R22, R23, R24, R25, R26, R27, R28, R29, R30, R31, R32: 22; R_0603_1608Metric_Pad0.98x0.95mm_HandSolder
U1, U2, U3, U4, U5, U6, U7, U8, U35, U36: CD74HC00; DIP-14_W7.62mm

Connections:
CLR: U35.6, U35.9, U35.10, U36.9, U36.10; also elsewhere on the board
GND: U1.7 (GND), U2.7 (GND), U3.7 (GND), U4.7 (GND), U5.7 (GND), U6.7 (GND), U7.7 (GND), U8.7 (GND), U35.7 (GND), U36.7 (GND); also elsewhere on the board
unnamed: U1.2, U1.5, U2.2, U2.5, U3.2, U3.5, U4.2, U4.5, U5.2, U5.5, U6.2, U6.5, U7.2, U7.5, U8.2, U8.5, U36.8
unnamed: U1.6, U1.9, U1.10
unnamed: U1.3, U1.12, U1.13
unnamed: U2.6, U2.9, U2.10
unnamed: U2.3, U2.12, U2.13
unnamed: U3.6, U3.9, U3.10
unnamed: U3.3, U3.12, U3.13
unnamed: U4.6, U4.9, U4.10
unnamed: U4.3, U4.12, U4.13
unnamed: U5.6, U5.9, U5.10
unnamed: U5.3, U5.12, U5.13
unnamed: U6.6, U6.9, U6.10
unnamed: U6.3, U6.12, U6.13
unnamed: U7.6, U7.9, U7.10
unnamed: U7.3, U7.12, U7.13
unnamed: U8.6, U8.9, U8.10
unnamed: U8.3, U8.12, U8.13
VCC: U1.14 (VCC), U2.14 (VCC), U3.14 (VCC), U4.14 (VCC), U5.14 (VCC), U6.14 (VCC), U7.14 (VCC), U8.14 (VCC), U35.5, U35.14 (VCC), U36.14 (VCC); also elsewhere on the board
Y_Data0: R17.1, U8.8; also elsewhere on the board
Y_Data1: R18.1, U8.11; also elsewhere on the board
Y_Data2: R19.1, U7.8; also elsewhere on the board
Y_Data3: R20.1, U7.11; also elsewhere on the board
Y_Data4: R21.1, U6.8; also elsewhere on the board
Y_Data5: R22.1, U6.11; also elsewhere on the board
Y_Data6: R23.1, U5.8; also elsewhere on the board
Y_Data7: R24.1, U5.11; also elsewhere on the board
Y_Data8: R25.1, U4.8; also elsewhere on the board
Y_Data9: R26.1, U4.11; also elsewhere on the board
Y_Data10: R27.1, U3.8; also elsewhere on the board
Y_Data11: R28.1, U3.11; also elsewhere on the board
Y_Data12: R29.1, U2.8; also elsewhere on the board
Y_Data13: R30.1, U2.11; also elsewhere on the board
Y_Data14: R31.1, U1.8; also elsewhere on the board
Y_Data15: R32.1, U1.11; also elsewhere on the board
Y_IN0: JP1.1 (A), U8.4; also elsewhere on the board
Y_IN1: JP2.1 (A), U8.1; also elsewhere on the board
Y_IN2: JP3.1 (A), U7.4; also elsewhere on the board
Y_IN3: JP4.1 (A), U7.1; also elsewhere on the board
Y_IN4: JP5.1 (A), U6.4; also elsewhere on the board
Y_IN5: JP6.1 (A), U6.1; also elsewhere on the board
Y_IN6: JP7.1 (A), U5.4; also elsewhere on the board
Y_IN7: JP8.1 (A), U5.1; also elsewhere on the board
Y_IN8: JP9.1 (A), U4.4; also elsewhere on the board
Y_IN9: JP10.1 (A), U4.1; also elsewhere on the board
Y_IN10: JP11.1 (A), U3.4; also elsewhere on the board
Y_IN11: JP12.1 (A), U3.1; also elsewhere on the board
Y_IN12: JP13.1 (A), U2.4; also elsewhere on the board
Y_IN13: JP14.1 (A), U2.1; also elsewhere on the board
Y_IN14: JP15.1 (A), U1.4; also elsewhere on the board
Y_IN15: JP16.1 (A), U1.1; also elsewhere on the board
Y_OUT0: JP1.2 (B), R17.2; also elsewhere on the board
Y_OUT1: JP2.2 (B), R18.2; also elsewhere on the board
Y_OUT2: JP3.2 (B), R19.2; also elsewhere on the board
Y_OUT3: JP4.2 (B), R20.2; also elsewhere on the board
Y_OUT4: JP5.2 (B), R21.2; also elsewhere on the board
Y_OUT5: JP6.2 (B), R22.2; also elsewhere on the board
Y_OUT6: JP7.2 (B), R23.2; also elsewhere on the board
Y_OUT7: JP8.2 (B), R24.2; also elsewhere on the board
Y_OUT8: JP9.2 (B), R25.2; also elsewhere on the board
Y_OUT9: JP10.2 (B), R26.2; also elsewhere on the board
Y_OUT10: JP11.2 (B), R27.2; also elsewhere on the board
Y_OUT11: JP12.2 (B), R28.2; also elsewhere on the board
Y_OUT12: JP13.2 (B), R29.2; also elsewhere on the board
Y_OUT13: JP14.2 (B), R30.2; also elsewhere on the board
Y_OUT14: JP15.2 (B), R31.2; also elsewhere on the board
Y_OUT15: JP16.2 (B), R32.2; also elsewhere on the board
~CLR_in: U35.4; also elsewhere on the board
~CLR_out: U35.8; also elsewhere on the board

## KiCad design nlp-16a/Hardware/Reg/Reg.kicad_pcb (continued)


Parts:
D1, D2, D3, D4, D5, D6, D7, D8, D9, D10, D11, D12, D13, D14, D15, D16, D18, D19: LED; LED_D3.0mm
J9: Conn_01x02_Male; PinHeader_1x02_P2.54mm_Horizontal
JP17: Jumper_3_Bridged12; SolderJumper-3_P1.3mm_Bridged12_RoundedPad1.0x1.5mm_NumberL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
R34, R35: R; R_0603_1608Metric_Pad0.98x0.95mm_HandSolder
RN1, RN2: R_Network08_Split; R_Array_SIP9
U9, U10, U11, U12, U13, U14, U15, U16, U33, U34, U36: CD74HC00; DIP-14_W7.62mm

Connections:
/Register/Reg0/Gate: U33.8; also elsewhere on the board
/Register/Reg1/Gate: D18.2 (A), J9.1, U33.6; also elsewhere on the board
A_IN0: U16.10; also elsewhere on the board
A_IN1: U16.13; also elsewhere on the board
A_IN2: U15.10; also elsewhere on the board
A_IN3: U15.13; also elsewhere on the board
A_IN4: U14.10; also elsewhere on the board
A_IN5: U14.13; also elsewhere on the board
A_IN6: U13.10; also elsewhere on the board
A_IN7: U13.13; also elsewhere on the board
A_IN8: U12.10; also elsewhere on the board
A_IN9: U12.13; also elsewhere on the board
A_IN10: U11.10; also elsewhere on the board
A_IN11: U11.13; also elsewhere on the board
A_IN12: U10.10; also elsewhere on the board
A_IN13: U10.13; also elsewhere on the board
A_IN14: U9.10; also elsewhere on the board
A_IN15: U9.13; also elsewhere on the board
A_OUT0: U16.8; also elsewhere on the board
A_OUT1: U16.11; also elsewhere on the board
A_OUT2: U15.8; also elsewhere on the board
A_OUT3: U15.11; also elsewhere on the board
A_OUT4: U14.8; also elsewhere on the board
A_OUT5: U14.11; also elsewhere on the board
A_OUT6: U13.8; also elsewhere on the board
A_OUT7: U13.11; also elsewhere on the board
A_OUT8: U12.8; also elsewhere on the board
A_OUT9: U12.11; also elsewhere on the board
A_OUT10: U11.8; also elsewhere on the board
A_OUT11: U11.11; also elsewhere on the board
A_OUT12: U10.8; also elsewhere on the board
A_OUT13: U10.11; also elsewhere on the board
A_OUT14: U9.8; also elsewhere on the board
A_OUT15: U9.11; also elsewhere on the board
A_SEL: U33.2; also elsewhere on the board
BUS_Correction_IN: U34.2; also elsewhere on the board
BUS_Correction_OUT: U34.3; also elsewhere on the board
CLR: U36.4; also elsewhere on the board
Data_Correction_IN: U34.5; also elsewhere on the board
Data_Correction_OUT: U34.6; also elsewhere on the board
GND: JP17.3 (B), R34.2, R35.2, RN1.1 (R1.1), RN2.1 (R1.1), U9.7 (GND), U10.7 (GND), U11.7 (GND), U12.7 (GND), U13.7 (GND), U14.7 (GND), U15.7 (GND), U16.7 (GND), U33.7 (GND), U34.7 (GND), U36.7 (GND); also elsewhere on the board
unnamed: D1.1 (K), RN1.2 (R1.2)
unnamed: D2.1 (K), RN1.3 (R2.2)
unnamed: D3.1 (K), RN1.4 (R3.2)
unnamed: D4.1 (K), RN1.5 (R4.2)
unnamed: D5.1 (K), RN1.6 (R5.2)
unnamed: D6.1 (K), RN1.7 (R6.2)
unnamed: D7.1 (K), RN1.8 (R7.2)
unnamed: D8.1 (K), RN1.9 (R8.2)
unnamed: D9.1 (K), RN2.2 (R1.2)
unnamed: D10.1 (K), RN2.3 (R2.2)
unnamed: D11.1 (K), RN2.4 (R3.2)
unnamed: D12.1 (K), RN2.5 (R4.2)
unnamed: D13.1 (K), RN2.6 (R5.2)
unnamed: D14.1 (K), RN2.7 (R6.2)
unnamed: D15.1 (K), RN2.8 (R7.2)
unnamed: D16.1 (K), RN2.9 (R8.2)
unnamed: D18.1 (K), R34.1
unnamed: D19.1 (K), R35.1
unnamed: D19.2 (A), J9.2, JP17.1 (A), U34.11
unnamed: JP17.2 (C), U9.1, U9.4, U10.1, U10.4, U11.1, U11.4, U12.1, U12.4
unnamed: U9.6, U9.9
unnamed: U9.3, U9.12
unnamed: U10.6, U10.9
unnamed: U10.3, U10.12
unnamed: U11.6, U11.9
unnamed: U11.3, U11.12
unnamed: U12.6, U12.9
unnamed: U12.3, U12.12
unnamed: U13.1, U13.4, U14.1, U14.4, U15.1, U15.4, U16.1, U16.4, U34.8
unnamed: U13.6, U13.9
unnamed: U13.3, U13.12
unnamed: U14.6, U14.9
unnamed: U14.3, U14.12
unnamed: U15.6, U15.9
unnamed: U15.3, U15.12
unnamed: U16.6, U16.9
unnamed: U16.3, U16.12
unnamed: U33.3, U34.1, U34.4, U34.9, U34.10, U34.12, U34.13
unnamed: U33.5, U33.10, U36.6
unnamed: U33.4, U33.9, U33.11
Reg_out0: D1.2 (A), U16.5; also elsewhere on the board
Reg_out1: D2.2 (A), U16.2; also elsewhere on the board
Reg_out2: D3.2 (A), U15.5; also elsewhere on the board
Reg_out3: D4.2 (A), U15.2; also elsewhere on the board
Reg_out4: D5.2 (A), U14.5; also elsewhere on the board
Reg_out5: D6.2 (A), U14.2; also elsewhere on the board
Reg_out6: D7.2 (A), U13.5; also elsewhere on the board
Reg_out7: D8.2 (A), U13.2; also elsewhere on the board
Reg_out8: D9.2 (A), U12.5; also elsewhere on the board
Reg_out9: D10.2 (A), U12.2; also elsewhere on the board
Reg_out10: D11.2 (A), U11.5; also elsewhere on the board
Reg_out11: D12.2 (A), U11.2; also elsewhere on the board
Reg_out12: D13.2 (A), U10.5; also elsewhere on the board
Reg_out13: D14.2 (A), U10.2; also elsewhere on the board
Reg_out14: D15.2 (A), U9.5; also elsewhere on the board
Reg_out15: D16.2 (A), U9.2; also elsewhere on the board
VCC: U9.14 (VCC), U10.14 (VCC), U11.14 (VCC), U12.14 (VCC), U13.14 (VCC), U14.14 (VCC), U15.14 (VCC), U16.14 (VCC), U33.1, U33.14 (VCC), U34.14 (VCC), U36.14 (VCC); also elsewhere on the board
Y_SEL: U33.13; also elsewhere on the board
phi2_out: U33.12, U36.5; also elsewhere on the board


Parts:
U32: CD74HC00; DIP-14_W7.62mm

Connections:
/Register/Reg0/Gate: U32.2, U32.5; also elsewhere on the board
GND: U32.7 (GND); also elsewhere on the board
unnamed: U32.6, U32.9
unnamed: U32.3, U32.4, U32.12
unnamed: U32.8, U32.13
Reg_out0: U32.10, U32.11; also elsewhere on the board
VCC: U32.14 (VCC); also elsewhere on the board
Y_Data0: U32.1; also elsewhere on the board


Board: 2 copper layers, 209.6 x 154.9 mm, 143 parts (0 on the bottom side), 269 nets.

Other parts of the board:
U17, U18, U19, U20, U21, U22, U23, U24, U25, U26, U27, U28, U29, U30, U31: CD74HC00; DIP-14_W7.62mm
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

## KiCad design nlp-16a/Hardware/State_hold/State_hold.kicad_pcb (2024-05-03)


Board: 2 copper layers, 45.7 x 99.1 mm, 55 parts (0 on the bottom side), 88 nets.

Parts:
C1, C2, C3, C4, C5, C6: C; C_Disc_D7.0mm_W2.5mm_P5.00mm
D1, D2, D3, D4, D5, D6, D7, D8, D9, D10, D11, D12: LED; LED_D3.0mm
J1, J2, J3, J4, J5, J6, J7, J8, J9, J10, J11, J12: Conn_01x05_Female; PinSocket_1x05_P2.54mm_Vertical
J13: Conn_01x02_Male; PinHeader_1x02_P2.54mm_Vertical
R1, R2, R3, R4, R5, R6, R7, R8, R9, R10, R11, R12: R; R_0603_1608Metric_Pad0.98x0.95mm_HandSolder
U1, U2, U3, U4, U5, U6, U7, U8, U9, U10, U11, U12: CD74HC00; DIP-14_W7.62mm

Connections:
/State_latch0/D: J1.1, U1.2
/State_latch0/Gate: J1.2, J3.2, J5.2, J7.2, J9.2, J11.2, U1.1, U1.5, U3.1, U3.5, U5.1, U5.5, U7.1, U7.5, U9.1, U9.5, U11.1, U11.5
/State_latch0/LED: J1.4, R1.1
/State_latch0/Q: J1.3, U1.10, U1.11
/State_latch0/~Q: J1.5, U1.8, U1.13
/State_latch1/D: J2.1, U2.2
/State_latch1/Gate: J2.2, J4.2, J6.2, J8.2, J10.2, J12.2, U2.1, U2.5, U4.1, U4.5, U6.1, U6.5, U8.1, U8.5, U10.1, U10.5, U12.1, U12.5
/State_latch1/LED: J2.4, R2.1
/State_latch1/Q: J2.3, U2.10, U2.11
/State_latch1/~Q: J2.5, U2.8, U2.13
/State_latch2/D: J3.1, U3.2
/State_latch2/LED: J3.4, R3.1
/State_latch2/Q: J3.3, U3.10, U3.11
/State_latch2/~Q: J3.5, U3.8, U3.13
/State_latch3/D: J4.1, U4.2
/State_latch3/LED: J4.4, R4.1
/State_latch3/Q: J4.3, U4.10, U4.11
/State_latch3/~Q: J4.5, U4.8, U4.13
/State_latch4/D: J5.1, U5.2
/State_latch4/LED: J5.4, R5.1
/State_latch4/Q: J5.3, U5.10, U5.11
/State_latch4/~Q: J5.5, U5.8, U5.13
/State_latch5/D: J6.1, U6.2
/State_latch5/LED: J6.4, R6.1
/State_latch5/Q: J6.3, U6.10, U6.11
/State_latch5/~Q: J6.5, U6.8, U6.13
/State_latch6/D: J7.1, U7.2
/State_latch6/LED: J7.4, R7.1
/State_latch6/Q: J7.3, U7.10, U7.11
/State_latch6/~Q: J7.5, U7.8, U7.13
/State_latch7/D: J8.1, U8.2
/State_latch7/LED: J8.4, R8.1
/State_latch7/Q: J8.3, U8.10, U8.11
/State_latch7/~Q: J8.5, U8.8, U8.13
/State_latch8/D: J9.1, U9.2
/State_latch8/LED: J9.4, R9.1
/State_latch8/Q: J9.3, U9.10, U9.11
/State_latch8/~Q: J9.5, U9.8, U9.13
/State_latch9/D: J10.1, U10.2
/State_latch9/LED: J10.4, R10.1
/State_latch9/Q: J10.3, U10.10, U10.11
/State_latch9/~Q: J10.5, U10.8, U10.13
/State_latch10/D: J11.1, U11.2
/State_latch10/LED: J11.4, R11.1
/State_latch10/Q: J11.3, U11.10, U11.11
/State_latch10/~Q: J11.5, U11.8, U11.13
/State_latch11/D: J12.1, U12.2
/State_latch11/LED: J12.4, R12.1
/State_latch11/Q: J12.3, U12.10, U12.11
/State_latch11/~Q: J12.5, U12.8, U12.13
GND: C1.1, C2.1, C3.1, C4.1, C5.1, C6.1, D1.1 (K), D2.1 (K), D3.1 (K), D4.1 (K), D5.1 (K), D6.1 (K), D7.1 (K), D8.1 (K), D9.1 (K), D10.1 (K), D11.1 (K), D12.1 (K), J13.1, U1.7 (GND), U2.7 (GND), U3.7 (GND), U4.7 (GND), U5.7 (GND), U6.7 (GND), U7.7 (GND), U8.7 (GND), U9.7 (GND), U10.7 (GND), U11.7 (GND), U12.7 (GND)
unnamed: D1.2 (A), R1.2
unnamed: D2.2 (A), R2.2
unnamed: D3.2 (A), R3.2
unnamed: D4.2 (A), R4.2
unnamed: D5.2 (A), R5.2
unnamed: D6.2 (A), R6.2
unnamed: D7.2 (A), R7.2
unnamed: D8.2 (A), R8.2
unnamed: D9.2 (A), R9.2
unnamed: D10.2 (A), R10.2
unnamed: D11.2 (A), R11.2
unnamed: D12.2 (A), R12.2
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

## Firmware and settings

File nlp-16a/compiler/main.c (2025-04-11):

#include <ctype.h>
#include <stdint.h>
#include <stdio.h>
#include <stdlib.h>
#include <stdbool.h>
#include <stdarg.h>
#include <string.h>

#define MAX_LINE 1000//最大行数
#define MAX_ONELINE 85//一行の文字数

FILE *input_file;
FILE *asm_output;
FILE *ast_output;
#define AST_OUT ast_output
#define ASM_OUT asm_output
char* src;//コードを格納
char* src_p;
int line_count = 1;

void error_at(char *loc, char *fmt, ...) {
    va_list ap;
    va_start(ap, fmt);

    int pos = loc - src;
    fprintf(stderr, "\x1b[31m");
    fprintf(stderr, "Error : line[%d]\n", line_count);
    for(int line=1;line_count!=line;src++,pos--){
        if(*src=='\n'|*src=='\0'){
            line++;
        }
    }
    for(;*src!='\n' & *src!='\0';src++){
        fprintf(stderr, "%c", *src);
    }
    //fprintf(stderr, "%s\n", src);
    fprintf(stderr, "\n%*s", pos, " "); // pos個の空白を出力
    fprintf(stderr, "^ ");
    vfprintf(stderr, fmt, ap);
    fprintf(stderr, "\x1b[39m\n");
    exit(1);
}

// トークン関連
// トークンの種類
typedef enum {
    //0-127は一文字トークン(+や*等)で使用．文字コードそのまま．
    // 実装済み
    // + - * / ( ) < >

    TK_NUM=128,     // 整数トークン
    TK_IDENT,       // 識別子
    TK_EOF,         // 入力の終わりを表すトークン
    //二文字以上のトークン
    TK_LOGICAL_OR,  // ||
    TK_LOGICAL_AND, // &&
    TK_EQ,          // ==
    TK_NE,          // !=
    TK_LE,          // <=
    TK_GE,          // >=
    TK_RET,         // return
    TK_IF,          // if
    TK_ELSE,        // else
    TK_WHILE,       // while
    TK_INT,         // int
    TK_CHAR_DATA,   //一文字
    TK_INC,         //++
    TK_DEC,         //--
    TK_PUTS,        //puts()
    TK_GETCH,       //getch()
    TK_MALLOC,      //malloc()
    TK_EXIT,        //exit()
    TK_COMMENT_OPEN,// /*
    TK_COMMENT_CLOSE,// */
} TokenKind;

typedef struct Token Token;
// トークン型
struct Token {
    TokenKind kind; // トークンの型
    int val;        // kindがTK_NUMの場合、その数値
    char *str;      // トークン文字列
    int len;
};

Token *reserved_cmp(Token* tk,int expct_kind,char*name){
    if( memcmp(src_p,name,strlen(name)) != 0 ){
        //fprintf(stderr,"Unmatch(%s)\n",name);
        return NULL;
    }else{
        fprintf(stderr,"\x1b[32mmatch(%s)\x1b[39m\n",name);
        tk->len = strlen(name);
        tk->kind = expct_kind;
        tk->str = src_p;
        src_p += tk->len;
        return tk;
    }
}
Token *keyword_cmp(Token* tk,int expct_kind,char*name){
    char *p = src_p;
    tk = reserved_cmp(tk,expct_kind,name);
    if (tk!=NULL & isalnum(*src_p) == 0 & *src_p != '_'){
        //fprintf(stderr,"\x1b[32mmatch return\x1b[39m\n");
        return tk;
    }else{
        //fprintf(stderr,"Unmatch return\n");
        src_p = p;
        return NULL;
    }
    return tk;
}

// 次のトークンが期待している記号のときには、トークンを1つ読み進めてトークンを返す。それ以外の場合には偽を返す。
// トークナイズと一緒にやる
Token *consume(int expct_kind) {
    Token* tk = calloc(1, sizeof(Token));
    //fprintf(stderr,"now address:[%d](%c)\n",src_p,*src_p);
    if(keyword_cmp(NULL,TK_COMMENT_OPEN,"/*")){
        while(keyword_cmp(NULL,TK_COMMENT_CLOSE,"*/")){
            if(*src_p=='\n'){
                line_count++;
            }
            src_p++;
        }
    }
    if(expct_kind == TK_CHAR_DATA){
        tk->str = src_p;
        if (isprint(*src_p)) {
            fprintf(stderr,"\x1b[32mTK_CHAR_DATA %c\x1b[39m\n",*src_p);
            tk->len = 1;
            tk->kind = expct_kind;
            tk->str = src_p;
            tk->val = (int)*src_p;
            src_p += tk->len;
            return tk;
        }else{
            fprintf(stderr,"Unmatch(TK_CHAR_DATA) %d\n",*src_p);
            src_p = tk->str;
            return NULL;
        }
    }
    while (isspace(*src_p)){
        if(*src_p=='\n'){
            line_count++;
        }
        src_p++;
    }
    if (expct_kind == TK_EOF){
        if( *src_p == '\0' ){
            fprintf(stderr,"\x1b[32mEOF\x1b[39m\n");
            tk->len = 0;
            tk->kind = expct_kind;
            tk->str = src_p;
            src_p += tk->len;
            return tk;
        }else{
            //fprintf(stderr,"Unmatch(TK_EOF)%c\n",*src_p);
            return NULL;
        }
    }
    if(expct_kind == TK_NUM){
        tk->str = src_p;
        if (isdigit(*src_p)) {
            int x = strtol(src_p, &src_p, 10);
            tk->kind = TK_NUM;
            tk->len = src_p - tk->str;
            tk->val = x;
            fprintf(stderr,"TK_NUM[%d] len:%d\n",x,tk->len);
            fprintf(stderr,"\x1b[32mmatch(TK_NUM)\x1b[39m [%d]\n",tk->val);
            return tk;
        }else{
            //fprintf(stderr,"Unmatch(TK_NUM) [%d != %d]%c\n",expct_kind, TK_NUM,*src_p);
            src_p = tk->str;
            return NULL;
        }
    }
    if (expct_kind == TK_IDENT){
        if (isalpha(*src_p)){
            tk->str = src_p;
            while(isalnum(*src_p) | *src_p == '_'){
                src_p++;
            }
            tk->len = src_p - tk->str;
            tk->kind = expct_kind;
            fprintf(stderr,"\x1b[32mmatch(TK_IDENT)\x1b[39m [%.*s] len:%d\n",tk->len,tk->str,tk->len);
            return tk;
        }else{
            //fprintf(stderr,"Unmatch(TK_IDENT)%c\n",*src_p);
            return NULL;
        }
    }
    if (expct_kind>=128){
        char *ret_src_p = src_p;
        switch (expct_kind){
            case TK_INC:
                return reserved_cmp(tk,TK_INC,"++");
            case TK_DEC:
                return reserved_cmp(tk,TK_DEC,"--");
            case TK_LOGICAL_OR:
                return reserved_cmp(tk,TK_LOGICAL_OR,"||");
            case TK_LOGICAL_AND:
                return reserved_cmp(tk,TK_LOGICAL_AND,"&&");
            case TK_EQ:
                return reserved_cmp(tk,TK_EQ,"==");
            case TK_NE:
                return reserved_cmp(tk,TK_NE,"!=");
            case TK_LE:
                return reserved_cmp(tk,TK_LE,"<=");
            case TK_GE:
                return reserved_cmp(tk,TK_GE,">=");
            case TK_RET:
                return keyword_cmp(tk,TK_RET,"return");
            case TK_IF:
                return keyword_cmp(tk,TK_IF,"if");
            case TK_ELSE:
                return keyword_cmp(tk,TK_ELSE,"else");
            case TK_WHILE:
                return keyword_cmp(tk,TK_WHILE,"while");
            case TK_INT:
                return keyword_cmp(tk,TK_INT,"int");
            case TK_PUTS:
                return keyword_cmp(tk,TK_PUTS,"puts");
            case TK_GETCH:
                return keyword_cmp(tk,TK_GETCH,"getch");
            case TK_MALLOC:
                return keyword_cmp(tk,TK_MALLOC,"malloc");
            case TK_EXIT:
                return keyword_cmp(tk,TK_MALLOC,"exit");
            case TK_COMMENT_OPEN:
                return keyword_cmp(tk,TK_MALLOC,"/*");
            case TK_COMMENT_CLOSE:
                return keyword_cmp(tk,TK_MALLOC,"*/");
            default:
                error_at(src_p,"Unknown token(expct_kind)\n");
        }
    }
    if (expct_kind == *src_p){
        fprintf(stderr,"\x1b[32mmatch(TK_RESERVED)\x1b[39m [%c]\n",expct_kind);
        tk->kind = expct_kind;
        tk->str = src_p;
        tk->len = 1;
        src_p++;
        return tk;
    }else{
        //fprintf(stderr,"Unmatch(TK_RESERVED) [%d != %d]%c\n",expct_kind, tk->kind,*src_p);
        return NULL;
    }
    error_at(src_p,"Tokenize error\n");
    return NULL;
}
Token *expect(int expct_kind) {
    Token *tok = consume(expct_kind);
    if (tok == NULL) {
        error_at(src_p,"Tokenize error\n");
    }
    return tok;
}
int expect_number() {
    fprintf(stderr,"TK_NUM [%d]\n",TK_NUM);
    Token *tok = consume(TK_NUM);
    if (tok == NULL) {
        error_at(src_p,"Tokenize error\n");
    }
    int val = tok->val;
    return val;
}
int expect_char() {
    Token *tok = consume(TK_CHAR_DATA);
    if (tok == NULL) {
        error_at(src_p,"Tokenize error\n");
    }
    int val = tok->val;
    return val;
}
Token *check_tk(int expct_kind){
    char *now = src_p;
    Token *tok = consume(expct_kind);
    src_p = now;
    return tok;
}

typedef enum{
    LVar_INT,
    LVar_ARRAY,
    LVar_POINTER,
    GVar_INT,
    GVar_ARRAY,
    GVar_POINTER,
} LVar_type;

// 変数関連
typedef struct LVar LVar;
struct LVar {
    LVar *next;     //次のLVar
    char *name;     //変数名
    int len;        //変数名長
    int offset;     //オフセット
    int size;
    LVar_type type; //種類
};

// ノード関連
// 抽象構文木のノードの種類
typedef enum {
    ND_ROOT,
    ND_DEF_LIST,
    ND_ADD,     // +
    ND_SUB,     // -
    ND_MUL,     // *
    ND_DIV,     // /
    ND_MOD,     // %
    ND_NUM,     // 整数
    ND_LOGICAL_OR,  // ||
    ND_LOGICAL_AND, // &&
    ND_EQ,      // ==
    ND_NE,      // !=
    // 比較演算子はCPUの仕様上
    // 小なり(つまりCMP結果がFlag_S=1，)大なりイコール(CMP結果がFlag_S=0)
    // となるためこの二つ．
    ND_LT,      // <
    ND_GE,      // >=

    ND_ASSIGN,  // =

    ND_DEF_FUNC,//関数定義
    ND_BLOCK,   //ステートメントのリスト
    ND_STMT,    //ステートメント本体
    ND_RET,     // return
    ND_LVAR,    // ローカル変数
    ND_IF,      // if
    ND_ELSE,    // else
    ND_WHILE,   // while
    ND_BREAK,   //break
    ND_CONTINUE,//continue
    
    ND_CAL_FUNC,//関数呼び出し

    ND_ARG_LIST,    //引数リスト
    ND_ARG,    //引数

    ND_ADDR,    //&
    ND_DEREF,   //*
    ND_INC,
    ND_DEC,
    ND_PUTS,
    ND_GETCH,
    ND_MALLOC,
    ND_EXIT,
} NodeKind;

typedef struct Node Node;

// 抽象構文木のノードの型
struct Node {
    NodeKind kind;  // ノードの型
    Token *tk;
    Node *parent;
    Node *list;
    Node *cond;      // 左辺
    Node *lhs;      // 左辺
    Node *rhs;      // 右辺
    int val;        // ND_NUM : num
                    // ND_DEF_FUNC : max lvar offset

    LVar *locals;
};
Node *new_node(NodeKind kind,Node *parent, Node *(*lhs)(Node *parent), Node *(*rhs)(Node *parent),Node *nd) {
    Node *node = calloc(1, sizeof(Node));
    node->kind = kind;
    node->parent = parent;
    if(lhs != NULL){
        node->lhs = lhs(node);
    }else{
        node->lhs = nd;
    }
    if(rhs != NULL){
        node->rhs = rhs(node);
    }else{
        node->rhs = nd;
    }
    node->locals = NULL;
    return node;
}
// 数値
Node *new_node_num(Node *parent,int val) {
    Node *node = new_node(ND_NUM,parent,NULL,NULL,NULL);
    node->val = val;
    return node;
}

LVar *new_arg(Token *tok,Node *func_node,int offset){
    if(func_node->kind == ND_DEF_FUNC){
        LVar *lvar= calloc(1, sizeof(LVar));
        lvar->next = func_node->locals;
        lvar->name = tok->str;
        lvar->len = tok->len;
        lvar->offset = offset;
        func_node->locals = lvar;
        return lvar;
    }return NULL;
}
LVar *new_lvar(Token *tok,Node *parent,int size, LVar_type type) {
    for (Node *nd = parent; nd!=NULL; nd = nd->parent){
        if(nd->kind == ND_BLOCK || nd->kind == ND_ROOT){
            LVar *lvar= calloc(1, sizeof(LVar));
            lvar->next = nd->locals;
            lvar->name = tok->str;
            lvar->len = tok->len;
            //lvar->offset = nd->locals->offset - nd->locals->size;
            lvar->offset = nd->locals->offset - size;
            lvar->size = size;
            lvar->type = type;
            nd->locals = lvar;
            return lvar;
        }
    }
    error_at(src_p,"lvar error : failed to make a LVar\n");
}
LVar *find_lvar_block(Token *tok,Node *parent){
    Node *nd;
    for (nd = parent; nd!=NULL && nd->locals==NULL; nd = nd->parent){}
    if(nd==NULL){
        return NULL;
    }
    for (LVar *var = nd->locals; var; var = var->next){
        if (var->len == tok->len && !memcmp(tok->str, var->name, var->len)){
            return var;
        }
    }
    return NULL;
}
LVar *find_lvar(Token *tok,Node *parent){
    for (Node *nd = parent; nd!=NULL; nd = nd->parent){
        for (LVar *var = nd->locals; var; var = var->next){
            if (var->len == tok->len && !memcmp(tok->str, var->name, var->len)){
                return var;
            }
        }
    }
    return NULL;
}
int block_offset(Node* nd){
    for (LVar *var = nd->locals; var; var = var->next){
        return var->offset;
    }
}
int lvar_offset(Node *parent){
    for (Node *nd = parent; nd!=NULL; nd = nd->parent){
        if(nd->kind==ND_BLOCK){
            return block_offset(nd);
        }
    }
    return 0;
}
//呼び出し順
Node *program();
Node *def_list(Node *parent);
Node *block(Node *parent);
Node *stmt_list(Node *parent);
Node *stmt(Node *parent);
Node *expr(Node *parent);
Node *assign(Node *parent);
Node *logical_or(Node *parent);
Node *logical_and(Node *parent);
Node *equality(Node *parent);
Node *relation(Node *parent);
Node *add(Node *parent);
Node *mul(Node *parent);
Node *unary(Node *parent);
Node *postfix_expr(Node *parent);
Node *primary(Node *parent);

Node *program(){
    fprintf(stderr,"\x1b[36m->program()\x1b[39m");
    Node *prog = new_node(ND_ROOT,NULL,NULL,NULL,NULL);
    prog->locals = calloc(1, sizeof(LVar));//グローバル変数生成
    Node *cur = prog;
    while (consume(TK_EOF)==NULL){
        Node *nd = new_node(ND_DEF_LIST,prog,def_list,NULL,NULL);
        cur->list = nd;
        cur = nd;
    }
    fprintf(stderr,"\x1b[36m->program()end\x1b[39m\n");
    return prog;
}
int arg_list(Node *node){
    if(check_tk(')')){
        return 2;
    }else{
        expect(TK_INT);
        while(consume('*'));
        Token *tk = consume(TK_IDENT);
        consume(',');
        int arg_offset = arg_list(node);
        LVar *lvar = new_arg(tk,node,arg_offset);
        fprintf(stderr,"local var : [%.*s] len:%d offset:%d\n",tk->len,tk->str,tk->len,lvar->offset);
        return ++arg_offset;
    }
}
Node *def_list(Node *parent){
    Node *node;
    while(1){
        expect(TK_INT);
        while(consume('*'));
        Token *tk = expect(TK_IDENT);
        if(consume('(')){
            node = new_node(ND_DEF_FUNC,parent,NULL,NULL,NULL);
            node->tk = tk; //関数名とかがtk内に入る
            node->locals = calloc(1, sizeof(LVar));//ローカル変数生成
            arg_list(node);
            expect(')');
            node->lhs = block(node);
            return node;
        }else{
            LVar_type type=GVar_INT;
            int size = 1;
            while(consume('[')){
                size *= expect_number();
                expect(']');
                type = GVar_ARRAY;
            }
            LVar *gvar;
            gvar = new_lvar(tk,parent,size,GVar_INT);
            fprintf(stderr,"global var : [%.*s] size:%d\n",tk->len,tk->str,gvar->size);
            expect(';');
        }
    }
}
Node *block(Node *parent){
    Node *node = new_node(ND_BLOCK,parent,NULL,NULL,NULL);
    node->locals= calloc(1, sizeof(LVar));//ローカル変数生成
    node->locals->offset = lvar_offset(parent);
    node->locals->size = 1;
    expect('{');

    Node *cur = node;
    while (consume('}')==NULL)
    {
        Node *nd = new_node(ND_STMT,node,stmt,NULL,NULL);
        cur->list = nd;
        cur = nd;
    }
    int offset = block_offset(node);
    if(node->val > offset){
        node->val = offset;
    }
    for (Node *nd = node; nd!=NULL; nd = nd->parent){
        if(nd->kind == ND_BLOCK && nd->val > offset){
            nd->val = offset;
        }
    }
    return node;
}
void decl_list(Node *parent){
    fprintf(stderr,"\x1b[35m->decl_list()\x1b[39m");
    while(consume(TK_INT) != NULL){
        LVar_type type=LVar_INT;
        while(consume('*')){type = LVar_POINTER;};
        Token *tk = consume(TK_IDENT);
        LVar *lvar = find_lvar_block(tk,parent);
        if (lvar!=NULL){
            error_at(src_p," error: redeclaration of '%.*s'",tk->len,tk->str);
        }
        int size = 1;
        while(consume('[')){
            size *= expect_number();
            expect(']');
            type = LVar_ARRAY;
        }
        expect(';'); 
        lvar = new_lvar(tk,parent,size,type);
        fprintf(stderr,"local var : [%.*s] len:%d offset:%d\n",tk->len,tk->str,tk->len,lvar->offset);
    }
    fprintf(stderr,"\x1b[35m->decl_list()end\x1b[39m\n");
    return;
}
Node *stmt(Node *parent){
    Node *node;
    fprintf(stderr,"\x1b[35m->stmt()\x1b[39m");
    decl_list(parent);
    if(consume(TK_RET)){
        fprintf(stderr,"\x1b[35m->return()\x1b[39m");
        fprintf(stderr,"\x1b[33m[return]\x1b[39m\n");
        if(consume(';')){// リターンのみ
            node = new_node(ND_RET,parent,NULL,NULL,NULL);
        }else{// 値を返す
            node = new_node(ND_RET,parent,expr,NULL,NULL);
            expect(';');
        }
        fprintf(stderr,"\x1b[35m->return()end\x1b[39m\n");
    }else if(consume(TK_IF)){
        fprintf(stderr,"\x1b[35m->if()\x1b[39m");
        fprintf(stderr,"\x1b[33m[if]\x1b[39m\n");
        node = new_node(ND_IF,parent,NULL,NULL,NULL);
        expect('(');
        node->cond = expr(node);
        expect(')');
        node->lhs = stmt(node);
        if(consume(TK_ELSE)){
            fprintf(stderr,"\x1b[33m[else]\x1b[39m\n");
            node->rhs = stmt(node);
        }
        fprintf(stderr,"\x1b[35m->if()end\x1b[39m\n");
    }else if(consume(TK_WHILE)){
        fprintf(stderr,"\x1b[35m->while()\x1b[39m");
        fprintf(stderr,"\x1b[33m[wehike]\x1b[39m\n");
        node = new_node(ND_WHILE,parent,NULL,NULL,NULL);
        expect('(');
        node->cond = expr(node);
        expect(')');
        node->lhs = stmt(node);
        fprintf(stderr,"\x1b[35m->while()end\x1b[39m\n");
    }else if(check_tk('{')){
        node = block(parent);
    }else{
        node = expr(parent);
        expect(';');
    }
    fprintf(stderr,"\x1b[35m->stmt()end\x1b[39m\n");
    return node;
}
Node *expr(Node *parent) {
    fprintf(stderr,"->expr()");
    return assign(parent);
}
Node *assign(Node *parent){
    fprintf(stderr,"->assign()");
    Node *node = logical_or(parent);
    if(consume('=')){
        fprintf(stderr,"\x1b[33m[=]\x1b[39m\n");
        node = new_node(ND_ASSIGN,parent,NULL,assign,node);
    }
    fprintf(stderr,"->assign()end\n");
    return node;
}

Node *logical_or(Node *parent){
    fprintf(stderr,"->equality()");
    Node *node = logical_and(parent);
    while(1){
        if(consume(TK_LOGICAL_OR)){
            fprintf(stderr,"\x1b[33m[==]\x1b[39m\n");
            node = new_node(ND_LOGICAL_OR,parent,NULL,logical_and,node);
        }else{
            fprintf(stderr,"->equality()end\n");
            return node;
        }
    }
}

Node *logical_and(Node *parent){
    fprintf(stderr,"->equality()");
    Node *node = equality(parent);
    while(1){
        if(consume(TK_LOGICAL_AND)){
            fprintf(stderr,"\x1b[33m[==]\x1b[39m\n");
            node = new_node(ND_LOGICAL_AND,parent,NULL,equality,node);
        }else{
            fprintf(stderr,"->equality()end\n");
            return node;
        }
    }
}

Node *equality(Node *parent){
    fprintf(stderr,"->equality()");
    Node *node = relation(parent);
    while(1){
        if(consume(TK_EQ)){
            fprintf(stderr,"\x1b[33m[==]\x1b[39m\n");
            node = new_node(ND_EQ,parent,NULL,relation,node);
        }else if(consume(TK_NE)){
            fprintf(stderr,"\x1b[33m[!=]\x1b[39m\n");
            node = new_node(ND_NE,parent,NULL,relation,node);
        }else{
            fprintf(stderr,"->equality()end\n");
            return node;
        }
    }
}
Node *relation(Node *parent){
    fprintf(stderr,"->relation()");
    Node *node = add(parent);
    while(1){
        if(consume(TK_LE)){
            fprintf(stderr,"\x1b[33m[<=]\x1b[39m\n");
            node = new_node(ND_GE,parent,add,NULL,node);
        }else if(consume(TK_GE)){
            fprintf(stderr,"\x1b[33m[>=]\x1b[39m\n");
            node = new_node(ND_GE,parent,NULL,add,node);
        }else if(consume('<')){
            fprintf(stderr,"\x1b[33m[<]\x1b[39m\n");
            node = new_node(ND_LT,parent,NULL,add,node);
        }else if(consume('>')){
            fprintf(stderr,"\x1b[33m[>]\x1b[39m\n");
            node = new_node(ND_LT,parent,add,NULL,node);
        }else{
            fprintf(stderr,"->relation()end\n");
            return node;
        }
    }
}
Node *add(Node *parent){
    fprintf(stderr,"->add()");
    Node *node = mul(parent);
    while(1){
        if(consume('+')){
            node = new_node(ND_ADD,parent,NULL,mul,node);
            fprintf(stderr,"\x1b[33m[+]\x1b[39m\n");
        }
        else if(consume('-')){//SubはAddの仲間
            node = new_node(ND_SUB,parent,NULL,mul,node);
            fprintf(stderr,"\x1b[33m[-]\x1b[39m\n");
        }else{
            fprintf(stderr,"->add()end\n");
            return node;
        }
    }
}
Node *mul(Node *parent) {
    fprintf(stderr,"->mul()");
    Node *node = unary(parent);
    while(1){
        if(consume('*')){
            node = new_node(ND_MUL,parent,NULL,unary,node);
            fprintf(stderr,"\x1b[33m[*]\x1b[39m\n");
        }else if(consume('/')){
            node = new_node(ND_DIV,parent,NULL,unary,node);
            fprintf(stderr,"\x1b[33m[/]\x1b[39m\n");
        }else if(consume('%')){
            node = new_node(ND_MOD,parent,NULL,unary,node);
            fprintf(stderr,"\x1b[33m[/]\x1b[39m\n");
        }else{
            fprintf(stderr,"->mul()end\n");
            return node;
        }
    }
}
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
int main(int argc, char **argv){
    input_file = stdin;
    asm_output = stdout;
    ast_output = NULL;
    for (int i = 1; i < argc; i++) {
        if (strcmp(argv[i], "--ast") == 0) {
          ast_output = stdout;
          asm_output = NULL;
        }
    }
    src = malloc(MAX_LINE * MAX_ONELINE);
    src_p = src;
    size_t src_len = fread(src, 1, MAX_LINE * MAX_ONELINE - 1, input_file);
    src[src_len] = '\0';
    Node *root = program();
    fprintf(AST_OUT,"digraph G {\n\trankdir=TB;\n\tgraph [fontname=\"MyricaM M\"];\n\tnode  [fontname=\"MyricaM M\"];\n\tedge  [fontname=\"MyricaM M\"];\n");
    
    // ビルドイン関数
    FILE * buildin_file = NULL;
    buildin_file = fopen( "buildin.asm", "r");
    if(buildin_file == NULL){
        fprintf(stderr,"open error");
    }
    char c;
	while ((c = fgetc(buildin_file)) != EOF){
		fprintf(ASM_OUT,"%c", c);
	}
	fclose(buildin_file);

    gen(root);
    
    fprintf(AST_OUT,"}");

    fprintf(stderr,"\x1b[32mok. \x1b[39m\n");
}

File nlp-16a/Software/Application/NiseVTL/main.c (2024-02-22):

#include <stdio.h>
#include <stdlib.h>
#include <ctype.h>
#include <string.h>

#define BUF_SIZE 500
#define END_OF_P BUF_SIZE-1
char buf[BUF_SIZE];
char input_buf[BUF_SIZE];
int top_end_p;
int bottom_start_p;

#define STACK_SIZE 100
int stack[STACK_SIZE] = {};
int sp=0;
#define VAR(n) n-48
int variable[30] = {};

#define ARRAY_SIZE 256
int array[ARRAY_SIZE];

char char_get(int now_p);
int p_get(int now_p);
void cursol_update(int new_cursol);
void insert(char data);
void view_raw_data();
int print_line(int line_num);
int line_head(int line_num);
void text_insert(int line_num);
int line_count();
void line_del(int line_num);
void text_change(int line_num);
int VTL_RUN();
int POP();
void PUSH(int data);
int stack_top();
void stack_print();

int main(void){
    top_end_p =  0;
    bottom_start_p = BUF_SIZE;
    cursol_update(0);
    for(int now_p = 0; now_p<BUF_SIZE;now_p++){buf[now_p]='\0';}
    int cursol_line = 1;
    for(cursol_line = 1;print_line(cursol_line);cursol_line++){}
    while(1){
        printf("editor c-mode>");
        fgets(input_buf, sizeof(input_buf), stdin);
        input_buf[strlen(input_buf) - 1] = '\0';
        fflush(stdin);
        int input_num[2] = {};
        int now_input_num = 0;
        int sign_flag=0;
        switch (input_buf[0])
        {
        case 'q':exit(0);//終了
        case 'a':text_insert(cursol_line);break;//挿入
        case 'c':text_change(cursol_line);break;//変更
        case 'n':printf("now cursol:%d\n",cursol_line);break;//現在のカーソル位置
        case 'p':for(cursol_line = 1;print_line(cursol_line);cursol_line++){}break;//全行表示
        case 'd':line_del(cursol_line);break;//削除
        case 'r':VTL_RUN();break;//インタプリタ実行
        case 'D':view_raw_data();break;//ギャップバッファデバッグ用
        default:
        /***
         * カーソル移動関連．.は現在のカーソル，$は最終行．
         * 数値,数値で指定範囲の表示．
         * カーソルや指定範囲には．や$に+-で指定も可能．
        */
            for(int count = 0;count < BUF_SIZE;count++){
                if(isdigit(input_buf[count])){
                    int num = 0;
                    for(;count < BUF_SIZE && isdigit(input_buf[count]);count++){
                        num *= 10;
                        num += input_buf[count]-48;
                    }
                    if(sign_flag==0)input_num[now_input_num] += num;
                    else input_num[now_input_num] -= num;
                    sign_flag = 0;
                    count--;
                }else if(input_buf[count] == '+'){
                }else if(input_buf[count] == '-'){
                    sign_flag=1;
                }else if(input_buf[count] == '.'){
                    input_num[now_input_num] = cursol_line;
                }else if(input_buf[count] == '$'){
                    input_num[now_input_num] = line_count();
                }else if(input_buf[count] == ','){
                    now_input_num++;
                }else if(input_buf[count]=='\0'){
                    if(input_num[1]>input_num[0]){
                        for(int cn=input_num[0];cn<=input_num[1];cn++){
                            print_line(cn);
                            cursol_line = input_num[1];
                        }
                    }else{
                        cursol_line = input_num[0];
                        print_line(cursol_line);
                    }
                    break;
                }
            }
        }
    }
    return 0;
}
/****************
 * スタックはアドレス計算のタイミングをハードの仕様に合わせてある．
 * ただスタックが伸びる方向が逆になっているので0番地が使われない謎仕様．
 * 問題はないのでおｋ
 ************* **/
int POP(){
    int wk = stack[sp];
    if(sp <= 0){
        printf("Error : stack pop[%d]",sp);
        exit(1);
    }
    sp--;
    return wk;
}
void PUSH(int data){
    if(sp >= STACK_SIZE){
        printf("Error : stack push[%d]",sp);
        exit(1);
    }
    ++sp;
    stack[sp]=data;
}
int stack_top(){
    return stack[sp];
}
int VTL_RUN(){
    int line = 0;
    int to_jump = 0;
    sp = 0;
    for(int count = 0;count < BUF_SIZE;count++){
        if(char_get(count)=='\0' || char_get(count)==EOF)return 0;//末尾で終了
        if(isdigit(char_get(count))){//数値を読み取り
            int num=0;
            for(;char_get(count) != EOF && isdigit(char_get(count));count++){
                num *= 10;
                num += char_get(count)-48;
            }
            PUSH(num);//入力された数値をスタックへ積む
            count--;
        }else{
            //各種計算関連
            if(char_get(count) == '+'){
                int wk1 = POP();//全てでこのようにPOPを並べているが，アセンブリにするときに都合が良いのでこのまま．
                int wk2 = POP();
                PUSH(wk1+wk2);
            }else if(char_get(count) == '-'){
                int wk1 = POP();
                int wk2 = POP();
                PUSH(wk2-wk1);
            }else if(char_get(count) == '/'){
                int wk1 = POP();
                int wk2 = POP();
                PUSH(wk2/wk1);
            }else if(char_get(count) == '*'){
                int wk1 = POP();
                int wk2 = POP();
                PUSH(wk1*wk2);
            }else if(char_get(count) == '%'){
                int wk1 = POP();
                int wk2 = POP();
                PUSH(wk2%wk1);
            }else if(char_get(count) == '$'){
                PUSH(getchar());
            }else if(char_get(count) == '?'){
                int tmp;
                scanf("%d",&tmp);
                getchar();
                PUSH(tmp);
            }else if(char_get(count) == '>'){
                int wk1 = POP();
                int wk2 = POP();
                PUSH(wk2>wk1);
            }else if(char_get(count) == '<'){
                int wk1 = POP();
                int wk2 = POP();
                PUSH(wk2<wk1);
            }else if(char_get(count) == '='){
                count++;
                if(char_get(count) == '='){//==で比較演算子
                    int wk1 = POP();
                    int wk2 = POP();
                    PUSH(wk2==wk1);//基本的に比較も含めて結果はすべてスタックに積む．
                }else{//=の次が=でなければ代入演算子
                    char operand = char_get(count);
                    int wk1 = POP();
                    if(operand=='?'){//数値として表示
                        printf("%d",wk1);
                    }else if(operand=='$'){//文字として表示
                        printf("%c",wk1);
                    }else if(operand=='#'){//プログラムカウンタに代入(かなり投げやりな実装)
                        if(wk1==0)continue;
                        to_jump = wk1;
                        count=0;
                    }else if(operand==':'){
                        if(0 <= wk1 && wk1 <= ARRAY_SIZE)array[wk1] = POP();
                        else{
                            printf("out of range [%c] line:[%d]\n",wk1,line);
                        }
                    }else{
                        if('A' <= operand && operand <= 'Z')variable[VAR(operand)] = wk1;
                        else{
                            printf("unknow variable [%c] line:[%d]\n",operand,line);
                        }
                    }
                }
            }else if(char_get(count) == '\n'){
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

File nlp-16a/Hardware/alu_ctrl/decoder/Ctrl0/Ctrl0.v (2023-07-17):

module AND(
  a, b, x
);

  input a, b;
  output x;

  assign x = a & b;

endmodule // AND

module NAND(a, b, y);
    input a, b;
    output y;
    wire tmp;
    AND AND(a,b,tmp);

    assign y = ~tmp;
endmodule



module test_tb ();

    parameter clk_period_p = 10;

    reg Ctrl0,INTERNAL_MOV,ADDRESS_MODE,INTERNAL_INC_DEC,INTERNAL_DEC;
    wire [0:0] out_Ctrl0;

    decode_ctrl0 decode_ctrl0(Ctrl0,INTERNAL_MOV,ADDRESS_MODE,INTERNAL_INC_DEC,INTERNAL_DEC,Ctrl0_out);

    initial begin
        $dumpfile("test.vcd");
        $dumpvars(0);
        $monitor("%t: Ctrl0 = %b, INTERNAL_MOV =%b, ADDRESS_MODE = %b, INTERNAL_INC_DEC = %b, INTERNAL_DEC = %b, Ctrl0_out = %b", $time,Ctrl0,INTERNAL_MOV,ADDRESS_MODE,INTERNAL_INC_DEC,INTERNAL_DEC,Ctrl0_out);
        //通常モード
        Ctrl0 = 0;
        INTERNAL_MOV = 1;
        ADDRESS_MODE = 1;
        INTERNAL_INC_DEC = 1;
        INTERNAL_DEC = 1;
        #clk_period_p;

        Ctrl0 = 1;
        INTERNAL_MOV = 1;
        ADDRESS_MODE = 1;
        INTERNAL_INC_DEC = 1;
        INTERNAL_DEC = 1;
        #clk_period_p;

        //内部処理 MOV
        Ctrl0 = 0;
        INTERNAL_MOV = 0;
        ADDRESS_MODE = 1;
        INTERNAL_INC_DEC = 1;
        INTERNAL_DEC = 1;
        #clk_period_p;

        Ctrl0 = 1;
        INTERNAL_MOV = 0;
        ADDRESS_MODE = 1;
        INTERNAL_INC_DEC = 1;
        INTERNAL_DEC = 1;
        #clk_period_p;

        //内部処理 INC
        Ctrl0 = 0;
        INTERNAL_MOV = 0;
        ADDRESS_MODE = 1;
        INTERNAL_INC_DEC = 0;
        INTERNAL_DEC = 1;
        #clk_period_p;

        Ctrl0 = 1;
        INTERNAL_MOV = 0;
        ADDRESS_MODE = 1;
        INTERNAL_INC_DEC = 0;
        INTERNAL_DEC = 1;
        #clk_period_p;

        //内部処理 INC
        Ctrl0 = 0;
        INTERNAL_MOV = 0;
        ADDRESS_MODE = 1;
        INTERNAL_INC_DEC = 0;
        INTERNAL_DEC = 0;
        #clk_period_p;

        Ctrl0 = 1;
        INTERNAL_MOV = 0;
        ADDRESS_MODE = 1;
        INTERNAL_INC_DEC = 0;
        INTERNAL_DEC = 0;
        #clk_period_p;

      //アドレス演算モード//
        //通常モード
        Ctrl0 = 0;
        INTERNAL_MOV = 1;
        ADDRESS_MODE = 0;
        INTERNAL_INC_DEC = 1;
        INTERNAL_DEC = 1;
        #clk_period_p;
        Ctrl0 = 1;
        INTERNAL_MOV = 1;
        ADDRESS_MODE = 0;
        INTERNAL_INC_DEC = 1;
        INTERNAL_DEC = 1;
        #clk_period_p;
        //内部処理 MOV
        Ctrl0 = 0;
        INTERNAL_MOV = 0;
        ADDRESS_MODE = 0;
        INTERNAL_INC_DEC = 1;
        INTERNAL_DEC = 1;
        #clk_period_p;

        Ctrl0 = 1;
        INTERNAL_MOV = 0;
        ADDRESS_MODE = 0;
        INTERNAL_INC_DEC = 1;
        INTERNAL_DEC = 1;
        #clk_period_p;

        //内部処理 INC
        Ctrl0 = 0;
        INTERNAL_MOV = 0;
        ADDRESS_MODE = 0;
        INTERNAL_INC_DEC = 0;
        INTERNAL_DEC = 1;
        #clk_period_p;

        Ctrl0 = 1;
        INTERNAL_MOV = 0;
        ADDRESS_MODE = 0;
        INTERNAL_INC_DEC = 0;
        INTERNAL_DEC = 1;
        #clk_period_p;
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

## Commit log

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2023-05-17 readme場所修正
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2023-05-17 ALU基板
    [ALUv6.kicad_sch, ALUv9.kicad_sch, alu_c.kicad_sch]
2023-05-17 説明修正
2023-05-17 タイポ修正
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2023-06-15 周辺機器RS-232Cの回路図等
    [RS_232.kicad_pcb, RS_232.kicad_sch]
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2023-06-18 周辺機器RS-232C,定数および接続ピンの修正
    [Book1.xlsx, RS_232.kicad_sch]
2023-06-29 ALU制御追加
    [ALU_Ctrl_Connectors.kicad_sch, ALU_Ctrl_Dec.kicad_sch, ALU_Ctrl_Flags.kicad_sch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]
2023-07-14 部品表追加
    [部品表.xlsx]
2023-07-17 ALU制御の回路修正
    [ALU_Ctrl_Connectors.kicad_sch, ALU_Ctrl_Dec.kicad_sch, ALU_Ctrl_Flags.kicad_sch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]
2023-07-17 ALU基板 ターミナルの干渉を修正
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2023-07-17 誤字修正
2023-07-17 ゼロフラグ高速化
    [ALU_Ctrl_Dec.kicad_sch, ALU_Ctrl_Flags.kicad_sch]
2023-07-18 基板の途中経過(デコーダ部分を配線中)
    [ALU_Ctrl_Dec.kicad_sch, ALU_Ctrl_Flags.kicad_sch, alu_ctrl.kicad_pcb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]
2023-07-18 基板の途中経過
    [ALU_Ctrl_Connectors.kicad_sch, ALU_Ctrl_Dec.kicad_sch, ALU_Ctrl_Flags.kicad_sch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]
2023-07-19 デコーダ周りの配線が通った!
    [ALU_Ctrl_Flags.kicad_sch, alu_ctrl.kicad_pcb, alu_ctrl.kicad_sch]
2023-07-19 githubのページから作業が見られるように思いつきで基板，回路のプレビューを追加．以下ではなるべく変更時にプレビューを更新
    [ALU_Ctrl_Connectors.kicad_sch, alu_ctrl.kicad_pcb, alu_ctrl.kicad_sch]
2023-07-19 電源バス，シルクスクリーン更新
    [ALU_Ctrl_Connectors.kicad_sch, alu_ctrl.kicad_pcb, alu_ctrl.kicad_sch]
2023-07-19 Ctrlバス表示LED配線
    [ALU_Ctrl_Connectors.kicad_sch, alu_ctrl.kicad_pcb]
2023-07-19 Yバス他修正
    [alu_ctrl.kicad_pcb]
2023-07-19 だいたい終了残りは制御バスのデバッグポートのみ
    [ALU_Ctrl_Connectors.kicad_sch, alu_ctrl.kicad_pcb]
2023-07-20 ignore修正
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2023-07-23 コミット漏れていた
    [alu_ctrl.kicad_pcb]
2023-07-24 デバッグポート(ALU制御バス)の配置プランが立った
    [alu_ctrl.kicad_pcb]
2023-07-24 電源バスの引き直しとデバッグポートの配線完了
    [ALU_Ctrl_Connectors.kicad_sch, alu_ctrl.kicad_pcb, alu_ctrl.kicad_sch]
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2023-07-24 だいたい完成．残りは詳細チェックとビア打ち
    [ALU_Ctrl_Connectors.kicad_sch, alu_ctrl.kicad_pcb]
2023-07-24 ALU制御基板OK
    [alu_ctrl.kicad_pcb]
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2023-07-26 オーバーフロー検出部修正
    [ALU_Ctrl_Flags.kicad_sch]
2023-07-26 軽微な回路修正
    [ALU_Ctrl_Flags.kicad_sch]
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2023-07-26 先ほどのオーバーフロー検出部の不具合を修正
    [ALU_Ctrl_Connectors.kicad_sch, ALU_Ctrl_Flags.kicad_sch]
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2023-07-26 J6，J7の位置を修正
    [alu_ctrl.kicad_pcb]
2023-07-26 基板の製造データ生成最終
    [alu_ctrl.kicad_pcb]
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2023-08-21 デバッガ基板
    [debug.kicad_pcb, debug.kicad_sch]
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2023-08-21 基板修正
    [debug.kicad_pcb, debug.kicad_sch]
2023-08-21 A,Bバスコントローラ
    [A_B_BUS_Ctrl.kicad_pcb, A_B_BUS_Ctrl.kicad_sch, address_decoder.kicad_sch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]
2023-08-22 内部処理モードを追加
    [A_B_BUS_Ctrl.kicad_sch, BUS_OUTPUT_Correction.kicad_sch, address_decoder.kicad_sch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]
2023-08-22 信号補正部追加
    [A_B_BUS_Ctrl.kicad_sch, BUS_OUTPUT_Correction.kicad_sch, Correction.kicad_sch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]
2023-08-22 配線作業開始
    [A_B_BUS_Ctrl.kicad_pcb, A_B_BUS_Ctrl.kicad_sch, BUS_OUTPUT_Correction.kicad_sch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]
2023-09-04 デバッガ基板の設計完了
    [debug.kicad_pcb, debug.kicad_sch]
2023-09-04 部品表更新
    [部品表.xlsx]
2023-09-04 デバッガ基板の設計今度こそ完了
    [debug.kicad_pcb, debug.kicad_sch]
2023-09-06 Yバス制御追加
    [Reg.kicad_sch, TMP_Reg.kicad_sch, Y_BUS_Ctrl.kicad_pcb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]
2023-09-06 TMPレジスタ等を追加
    [Connector.kicad_sch, Reg.kicad_sch, TMP_Reg.kicad_sch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]
2023-09-06 Yバスだいたい配線完了
    [Connector.kicad_sch, Reg.kicad_sch, TMP_Reg.kicad_sch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]
2023-09-06 YバスTMPRegリファレンス割り当て
    [Connector.kicad_sch, Reg.kicad_sch, TMP_Reg.kicad_sch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]
2023-09-08 アドレスデコーダ部の論理のミスを修正
    [A_B_BUS_Ctrl.kicad_sch, BUS_OUTPUT_Correction.kicad_sch, address_decoder.kicad_sch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]
2023-09-08 Yバス制御 配置の決定，リファレンスの割り当て，ERCの確認完了
    [Connector.kicad_sch, Reg.kicad_sch, TMP_Reg.kicad_sch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]
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2023-10-04 ALU制御 右シフト/右ロール機能選択部の不具合を修正
    [ALU_Ctrl_Connectors.kicad_sch, alu_ctrl.kicad_pcb]
2023-10-27 ALU手動テストボード追加
    [SW_Board.kicad_pcb, SW_Board.kicad_sch]
2023-10-29 見積もり他
    [SW_Board.kicad_pcb, SW_Board.kicad_sch, 部品表.xlsx]
2023-10-30 ALU手動テストボード使いやすいように更新
    [SW_Board.kicad_pcb, SW_Board.kicad_sch, 部品表.xlsx]
2023-11-12 Y BUS制御の基板をとりあえず描いた．ビアとかはまた後で
    [Accumulator.kicad_sch, Reg.kicad_sch, TMP_Reg.kicad_sch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]
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2023-12-06 Y-BUS制御完成
    [Connector.kicad_sch, TMP_Reg.kicad_sch, Y_BUS_Ctrl.kicad_pcb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]
2023-12-06 Acc回路完成(変更の可能性有)
    [Accumulator.kicad_pcb, Accumulator.kicad_sch, Reg.kicad_sch]
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2024-01-24 A BUS制御 更新
    [A_BUS_Ctrl.kicad_sch, BUS_OUTPUT_Correction.kicad_sch, Correction.kicad_sch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]
2024-01-24 Y BUS制御 更新
    [Connector.kicad_sch, Y_BUS_Ctrl.kicad_sch, address_decoder.kicad_sch]
2024-01-24 アキュムレータ 更新
    [Accumulator.kicad_sch, dmy_pad.kicad_sch]
2024-01-24 BUSターミネータ 更新
    [BUS_terminator.kicad_pcb, BUS_terminator.kicad_sch, IO_port.kicad_sch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]
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2024-01-25 アキュムレータ更新
    [BUS_terminator.kicad_pcb, BUS_terminator.kicad_sch, IO_port.kicad_sch]
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2024-01-27 バスターミネータのDMA機能は不要と判断したので削除．必要ならば外部回路で実現するように
    [BUS_terminator.kicad_pcb, BUS_terminator.kicad_sch, IO_port.kicad_sch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]
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2024-02-02 レジスタ基板
    [BUS_Buf.kicad_sch, Reg.kicad_pcb, Reg.kicad_sch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]
2024-02-04 レジスタ基板だいたい完成
    [BUS_Buf.kicad_sch, Reg.kicad_pcb, Reg.kicad_sch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]
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2024-02-11 テストで見つかった不具合を修正(れジスタアドレスデコーダ，Addrの内部処理の方法を変更)
    [A_BUS_Ctrl.kicad_sch, BUS_OUTPUT_Correction.kicad_sch, address_decoder.kicad_sch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]
2024-02-11 テストを受けてレジスタの設計を更新
    [BUS_Buf.kicad_sch, Reg.kicad_pcb, Reg.kicad_sch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]
2024-02-11 レジスタクリア時の動作を修正
    [BUS_Buf.kicad_sch, Reg.kicad_pcb, Register.kicad_sch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]
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2024-02-22 イロイロ修正
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2024-02-25 Reg更新
    [Reg.kicad_pcb, Register.kicad_sch]
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2024-02-26 シフト演算修正
2024-02-26 NOT修正
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2024-03-12 命令デコーダインターフェイスとりあえずコミット
    [3word.kicad_sch, A_B_Select.kicad_sch, A_Y_Select.kicad_sch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]
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2024-03-12 Y BUS制御 IV -> Acc ENの修正
    [Connector.kicad_sch, Y_BUS_Ctrl.kicad_sch, address_decoder.kicad_sch]
2024-03-14 命令デコーダインターフェイスの回路がだいたいおｋ
    [ID_interface.kicad_sch, Seed_pluse.kicad_sch]
2024-03-14 A BUS制御 IVとIR3のアドレスの処理変更を反映
    [address_decoder.kicad_sch, connectors.kicad_sch]
2024-03-14 アキュムレータ書き込み条件変更(内部処理モードとAcc選択を追加)
    [Accumulator.kicad_sch, dmy_pad.kicad_sch]
2024-03-14 使用しない基板を削除
    [A_B_BUS_Ctrl.kicad_pcb, A_B_BUS_Ctrl.kicad_sch, BUS_OUTPUT_Correction.kicad_sch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]
2024-03-14 命令デコーダのステート保持用ラッチ追加
    [State_hold.kicad_pcb, State_hold.kicad_sch, State_hold_unit.kicad_sch.kicad_sch]
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2024-03-30 ステート保持ラッチ再設計．おそらく問題無し
    [State_hold.kicad_pcb, State_hold.kicad_sch, State_latch.kicad_sch]
2024-03-31 命令デコーダの回路ひとまず書き出し．未完成
    [Instruction_decoder.kicad_pcb, Instruction_decoder.kicad_sch, Interrupt.kicad_sch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]
2024-03-31 命令デコーダ 不具合修正
    [POP_RET.kicad_sch, execute.kicad_sch, fetch.kicad_sch]
2024-03-31 ALU制御 修正分反映
    [ALU_Ctrl_Dec.kicad_sch, ALU_Ctrl_Flags.kicad_sch, alu_ctrl.kicad_pcb]
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2024-04-08 命令デコーダ ロジック部の設計だいたい完了git statusgit statusやったぜ
    [Instruction_decoder.kicad_sch, Interrupt.kicad_sch, POP_RET.kicad_sch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]
2024-04-08 命令デコーダ 軽微な修正
    [Instruction_decoder.kicad_sch, control_signal.kicad_sch]
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2024-05-03 軽微な修正を加えてガーバー作成 発注
    [ID_interface.kicad_pcb, ID_interface.kicad_sch, Seed_pluse.kicad_sch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]
2024-05-13 Y BUS制御の軽微な修正
2024-05-13 修正はしていないがkicadで開いたら謎に変更が入った
    [ALU_Ctrl_Dec.kicad_sch]
2024-05-13 テスト修正
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2024-05-13 テストの軽微な修正
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2024-05-26 >noバグ修正完了
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2024-05-26 MUL/DIVサブルーチンの修正．
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2024-07-15 ALU エラッタ修正版
    [ALUv6.kicad_sch, alu_c.kicad_sch]
2024-07-15 ALU制御 エラッタ修正版
    [ALU_Ctrl_Connectors.kicad_sch, ALU_Ctrl_Dec.kicad_sch, ALU_Ctrl_Flags.kicad_sch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]
2024-07-22 A BUS制御修正
    [A_BUS_Ctrl.kicad_sch, address_decoder.kicad_sch]
2024-07-22 Y BUS制御修正
    [Y_BUS_Ctrl.kicad_sch, address_decoder.kicad_sch, address_decoder_ADDR.kicad_sch]
2024-07-22 アキュムレータ修正
    [Accumulator.kicad_sch]
2024-07-22 命令デコーダ修正
    [Instruction_decoder.kicad_sch, connector.kicad_sch, control_signal.kicad_sch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]
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2024-08-14 終了処理修正
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2024-10-29 RAMボードの部品の値を修正
    [RAM_board.kicad_sch]
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2024-11-02 RAMテストのアドレス指定を修正
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2024-11-02 デバッガのファームが古かったので修正
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2024-11-02 テキストエディタの軽微な修正
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2024-11-09 ALUとデータバス関連のテストID修正
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2024-11-21 MIKBUGを16A+周辺機器ボード用に修正
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2024-12-03 テストコード修正(今後Addr Regのテストを追加予定)
2024-12-05 命令デコーダテストコード修正
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2024-12-06 ライフゲームに軽微な修正
2024-12-06 スタック破壊の修正とモニタからの呼び出しに対応
2024-12-06 RPNを16A用に修正
2024-12-06 サンプルコードリストを修正
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2024-12-06 readme修正
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2025-01-13 接続ポートとモニタプログラムの修正
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2025-03-11 相対アドレッシング時のレジスタサイズ計算のバグを修正
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2025-05-24 ハードウェアReadmeちょっと修正
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2025-10-13 ビット演算と論理OR，ANDを修正
